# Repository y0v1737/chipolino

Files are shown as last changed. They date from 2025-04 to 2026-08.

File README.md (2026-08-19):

# Chip'olino: [The Playbook](The_Playbook/Chipolino_The_Playbook.md)

**Chip'olino** is a hardware-software platform designed for performing glitch attacks via power supply. It includes the main Chip'olino board and a set of addons for various microcontrollers. Chip'olino addresses two main tasks:
- Performing known power supply attacks on microcontrollers.    
- Research and experiments in the field of power supply attacks.

### Targets
Currently, the project includes algorithms for conducting attacks on:
* [Realtek (rtl8762)](The_Playbook/Realtek.md)
* [Rockchip (RK3588)](The_Playbook/RK3588.md)
* [nRF52 (The entire nRF5 family)](The_Playbook/nRF52.md)
* [Renesas RH850 (The entire RH850 family)](The_Playbook/Renesas.md)
* [NXP (LPC214x, LPC134x)](The_Playbook/NXP.md)
* [STM32 (Different series of chips)](The_Playbook/STM32.md)

In addition to the main algorithms, the repository contains auxiliary scripts for locking test chips, reading firmware, erasing the chip, and determining the current protection level.


##### Author's note.
Chip'olino implements algorithms for unlocking a large number of chips, but this does not eliminate the need to read the documentation and thoroughly understand what is happening. One needs to understand both how the protection of the target MCU works and how the attack is carried out. Power supply attacks are a complex and fascinating topic with many nuances.

Below is the functional diagram of the Chip'olino.

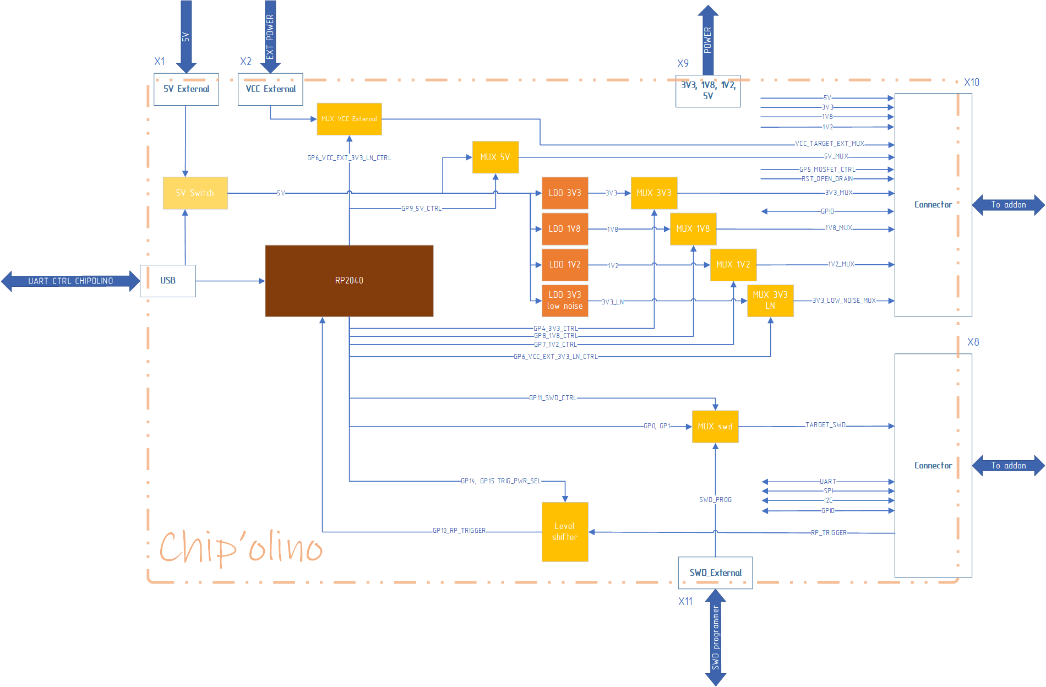
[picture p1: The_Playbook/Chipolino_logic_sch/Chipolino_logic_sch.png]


To carry out an attack on the MCU, it needs to be desoldered and soldered onto a ready-made addon, which can be connected to the main board. This approach allows for precise control of the timing parameters of the attack and significantly improves the repeatability of the attack.

### Features
* **External power supply for attacks:** Support for external power supply (0–5V, 100mA) through the X2 connector (External Target Supply). This is useful when the built-in power source is insufficient or when a lower voltage is required (e.g., for some chips that require less than the standard 3.3V). It allows you to connect a lab power supply and experiment with different power levels.    
- **High-speed SWD interface:** The implementation of SWD on the PIO in the Chip'olino module ensures direct and fast interaction with microcontrollers (NRF52, STM32, etc.) without the delays typical of USB programmers (J-Link and similar), speeding up command cycling by hundreds of times.    
- **SWD multiplexer:** The ability to switch between the built-in SWD interface and an external debugger connected to the X11 connector, which is convenient for quickly connecting an external programmer right after the attack is completed.    
- **Variety of power sources:** Several built-in power sources with independent control and support for external 5V power supply for the entire device, reducing the impact of noise and interference.    
- **Universal addon:** A module for connecting and testing any boards and devices.    
- **Auxiliary scripts:** A set of ready-made scripts for automating tasks and simplifying work with microcontrollers.

##### Note
```
All values for pulse widths and offset shifts for glitches provided in the instructions are based on the RP2040 clock frequency of 250 MHz.
```

### Files

```
.
├── The_Playbook
│   └── Chipolino_The_Playbook.md    # Chip'olino Playbook 
├── fw                               # Chip'olino firmware project 
│   ├── includes
│   ├── pio_sm
│   └── targets
├── pcb                              # PCB projects
│   ├── ChipOlino_revA               # Chip'olino PCB project
│   ├── Realtek                      # Realtek addons PCB
│   │   ├── RTL8762CKF_revA
│   ├── Nordic                       # Nordic addons PCB
│   │   ├── nRF52832-CIAA
│   │   ├── nRF52840-QIAA
│   │   └── nRF52833-QDAA
│   ├── NXP                          # NXP addons PCB
│   │   ├── LPC1343FBD48_revA
│   │   └── LPC2148FBD64_revA
│   ├── STM                          # STM addons PCB
│   │   ├── STM32F446RCT6_revA
│   │   └── STM32F411CCU_revA
│   ├── Renesas                      # Renesas addons PCB
│   │   └── RH850_F1L_revB   
│   ├── template_addon_revA          # template addon project
│   └── universal_addon_revA         # universal addon project
├── scripts                           
│   ├── check_ssr_rh850.py    
│   ├── chipctrl.py                  # Chip'olino control script (main for use)
│   ├── chipolino.py                 # class for Chip'olino board 
│   ├── dump_rh850.py                
│   ├── dump_stm32.py 
│   ├── dump_lpc1343.py
│   ├── dump_lpc2148.py
│   ├── erase_lpc2148.py
│   ├── erase_lpc1343.py
│   ├── erase_rh850.py               
│   ├── requirements.txt             # pip install -r requirements.txt
│   └── test_erase_stm32.py          
└── ...
```

### Quick start

1) Install all the necessary packages:
```
pip install -r ./scripts/requirements.txt
```
2) Read [The Playbook](The_Playbook/Chipolino_The_Playbook.md)

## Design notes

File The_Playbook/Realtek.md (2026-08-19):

## RTL8762CKF

### Overview
The **RTL8762CKF** is an ultra-low-power system on-chip solution for Bluetooth 5 low energy applications that combines the excellent performance of a leading RF transceiver with a low-power ARM Cortex-M4F and rich powerful supporting features and peripherals.

**RTL8762CKF** provides 6 security levels: 0 to 5. The security levels can be divided into two groups: 0 to 2 and 3 to 5. The only one difference of them is the HCI Download feature. A larger number indicates higher security level, which will affect debug and re-program of eFuse. Function control of each module under different security level is listed in the following table. 

| Security Level | SWD Control | eFuse Read | eFuse Write | HCI Download | HCI BT Test |
| --- | --- | --- | --- | --- | --- |
| 0 | Enable | Enable | Enable | Enable | Enable |
| 1 | Enable by password | Enable by password | Enable | Enable | Enable |
| 2 | Enable by password | Disable | Enable by password | Enable | Enable |
| 3 | Enable | Enable | Enable | Enable by password | Enable |
| 4 | Enable by password | Enable by password | Enable | Enable by password | Enable |
| 5 | Enable by password | Disable | Enable by password | Enable by password | Enable |

The documentation and SDK for this chip can be found here:
[https://www.realmcu.com/en/Resources/SDK/RTL8762C-Series](https://www.realmcu.com/en/Resources/SDK/RTL8762C-Series)  

For testing, you can solder the **RTL8762CKF** chip onto the addon board without any lock enabled and then activate the protection on it. It is recommended to use FT232 USB to UART converter boards for better stability. Connect addon board to USB to UART adapter as depicted below and use **MP Tool**  utility.  

Note: 2.5V (±10%) power supply must be applied when programming eFuse. The flash procedure supports wide voltage range and can be powered by 2.5V (±10%) as well. Under such circumstances, Flash and eFuse can be programmed in one step.  

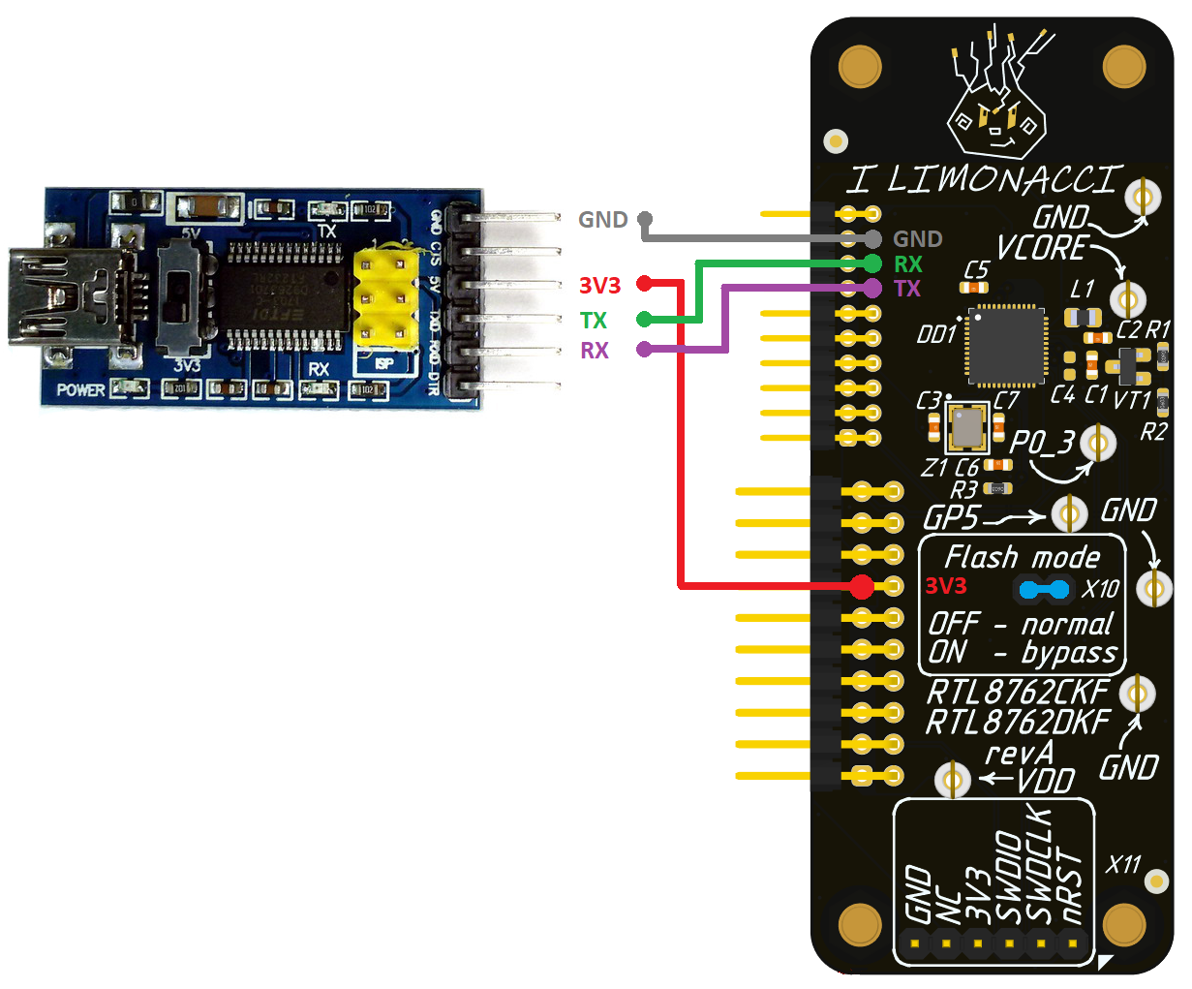
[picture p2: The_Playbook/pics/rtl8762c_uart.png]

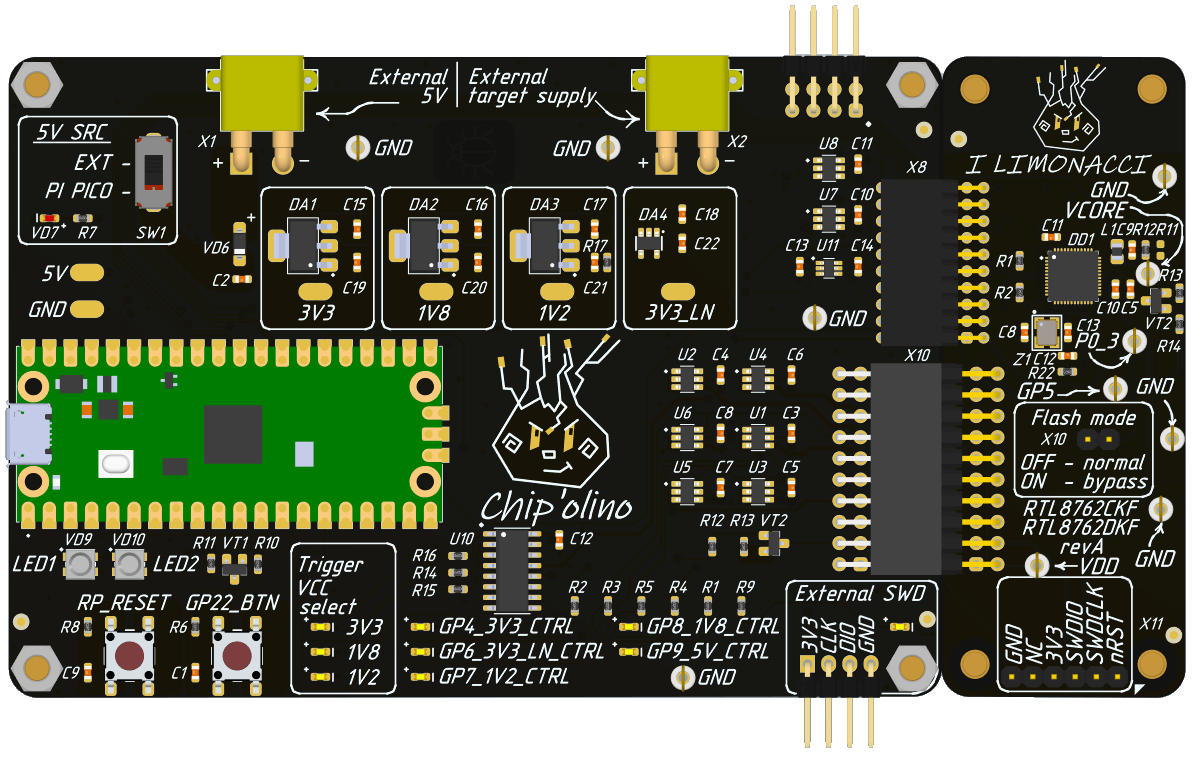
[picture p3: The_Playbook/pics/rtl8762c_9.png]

## Glitch can bypass SWD password check on boot.
During the security research of RTL8762CKF we were able to dump ROM from chip. One of the ROMs functions: **configure_security_register_and_LOCK_it()**  performs check of security state of IC and also verifies password to unlock SWD (Security LOCK_MODE 5, greatest).

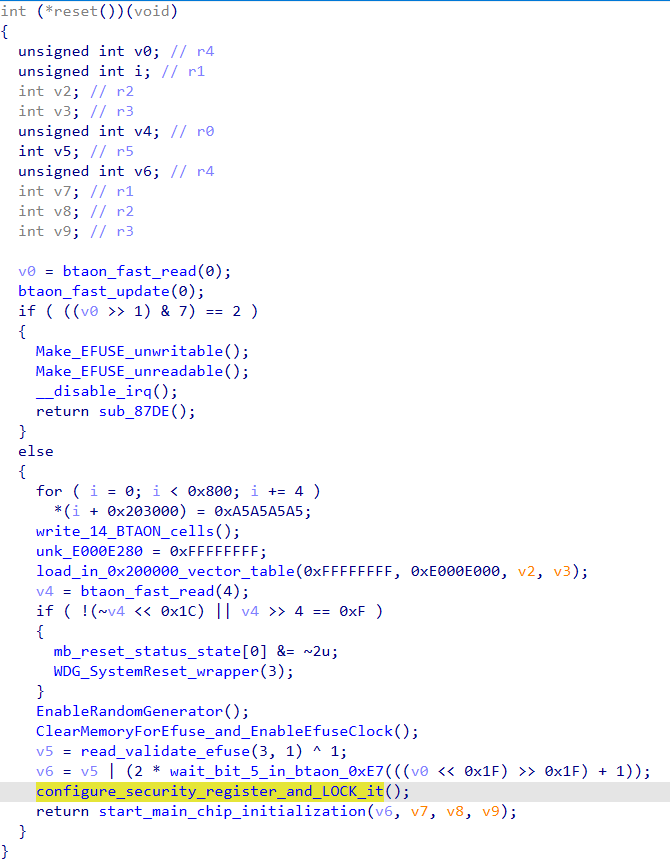
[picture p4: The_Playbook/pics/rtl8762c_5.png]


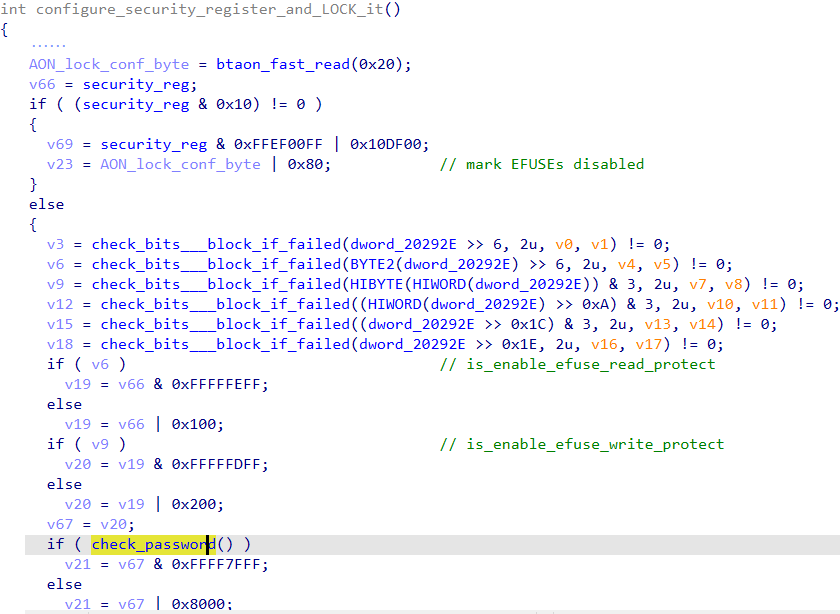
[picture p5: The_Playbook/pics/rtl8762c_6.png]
  

In **check_password()** function we identified, after memcmp() function we can possibly glitch CPU power to skip instruction or revert state of R0 register.

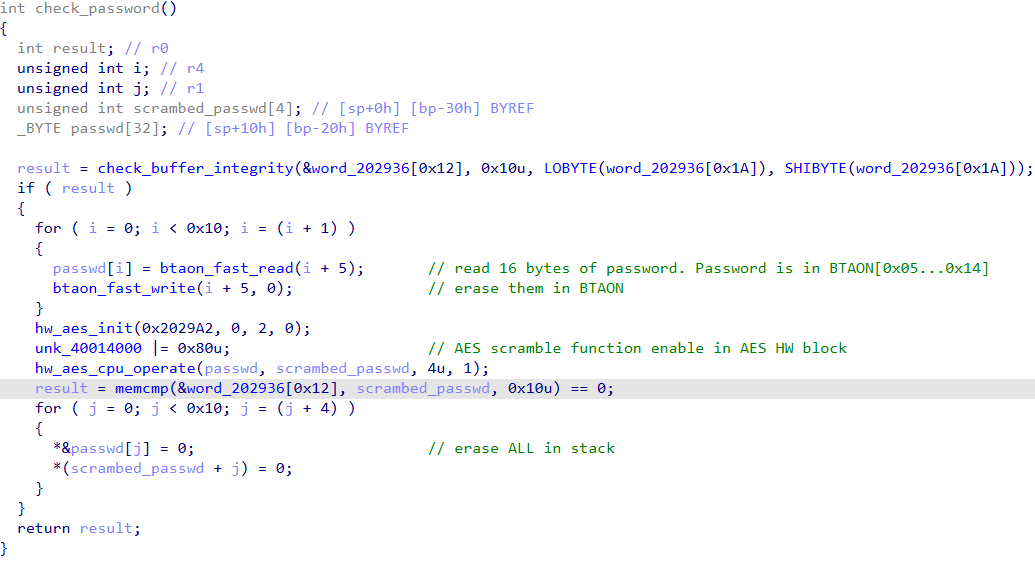
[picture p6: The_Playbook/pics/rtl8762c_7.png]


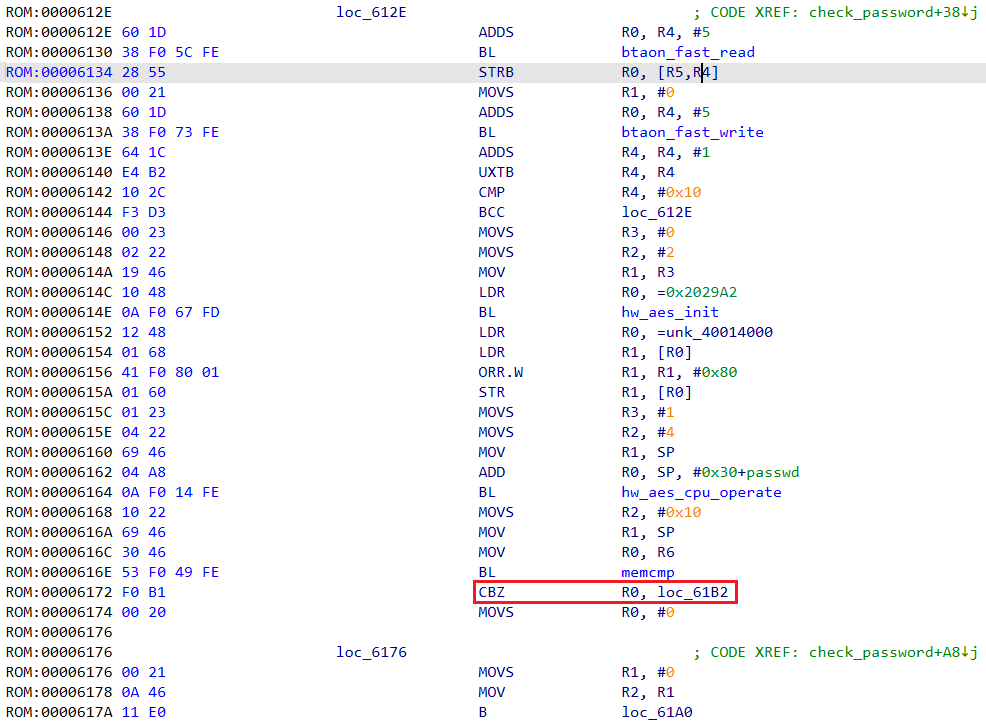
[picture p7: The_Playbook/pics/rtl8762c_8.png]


Note, there are several places in the code where successfull glitch (that skips instruction or alters register value) may lead to SWD unlock.  

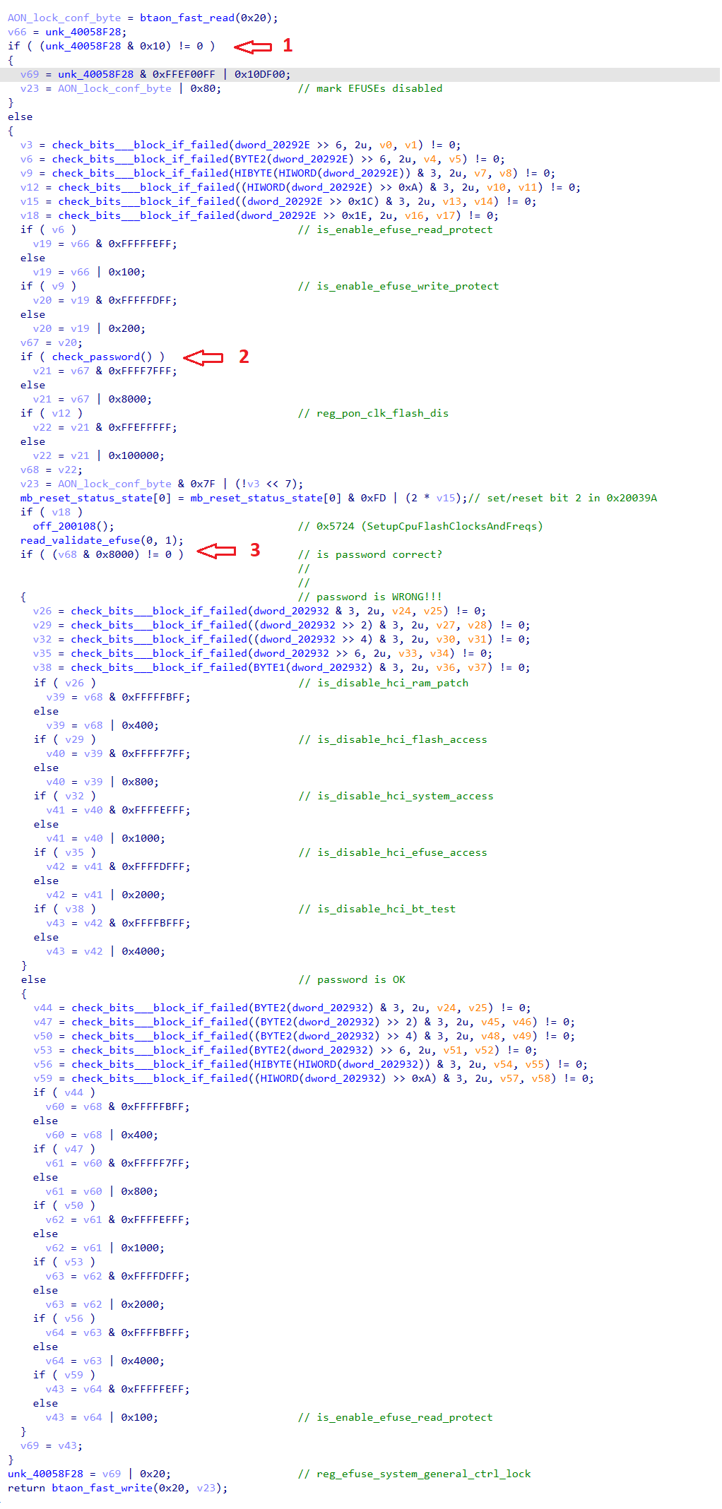
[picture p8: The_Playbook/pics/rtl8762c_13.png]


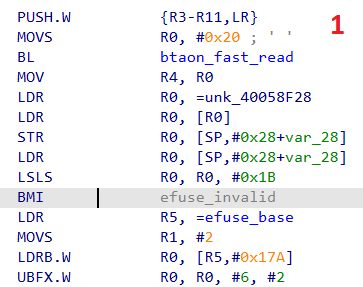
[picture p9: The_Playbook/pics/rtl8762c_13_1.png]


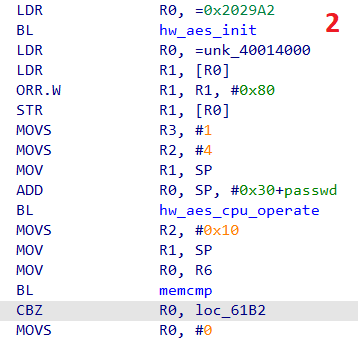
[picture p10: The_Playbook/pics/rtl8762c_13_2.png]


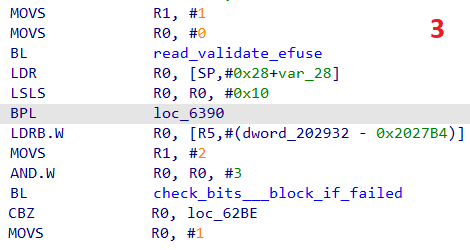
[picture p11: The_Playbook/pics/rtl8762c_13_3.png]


With the EM probe we perform a simple side-channel analysis (SCA) to understand when SWD access check operation is implemented, what parts of bootrom code precede and what follow it. This insight helps us in narrowing down the point in time for the fault injection attack to unlock debug interface with precision of few microseconds.  

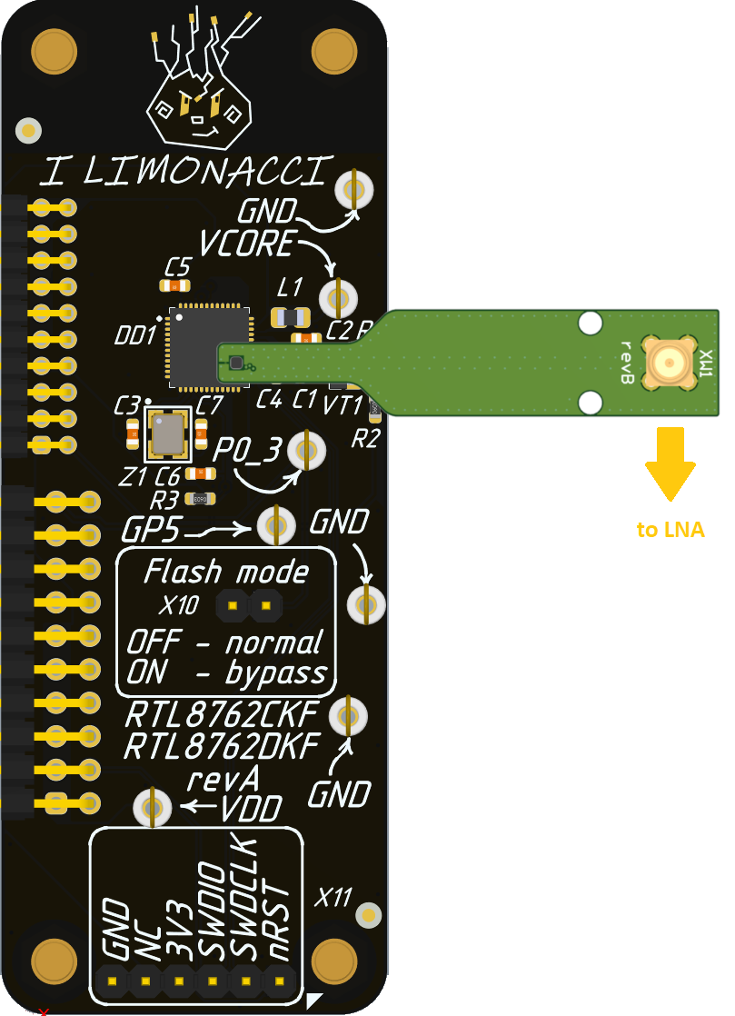
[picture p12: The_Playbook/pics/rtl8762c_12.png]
  

It is important to note that in order to obtain a clear picture of the chip's EM emission, the value of the capacitance shunting the VDIGI pin of the RTL8762CKF must be reduced to 10 nF.  

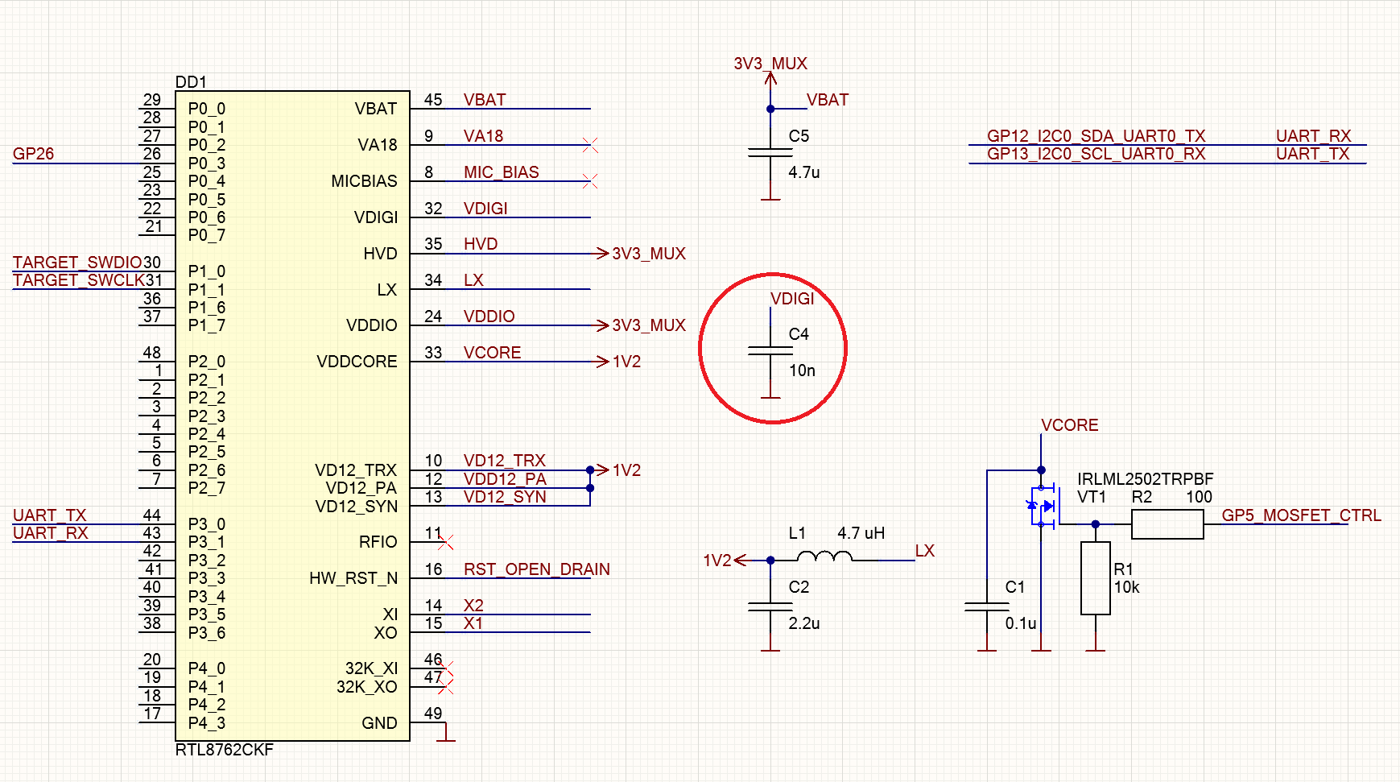
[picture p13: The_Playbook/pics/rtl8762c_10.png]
  

The following picture shows the EM trace of the chip's activity from the beginning of the bootrom execution.  

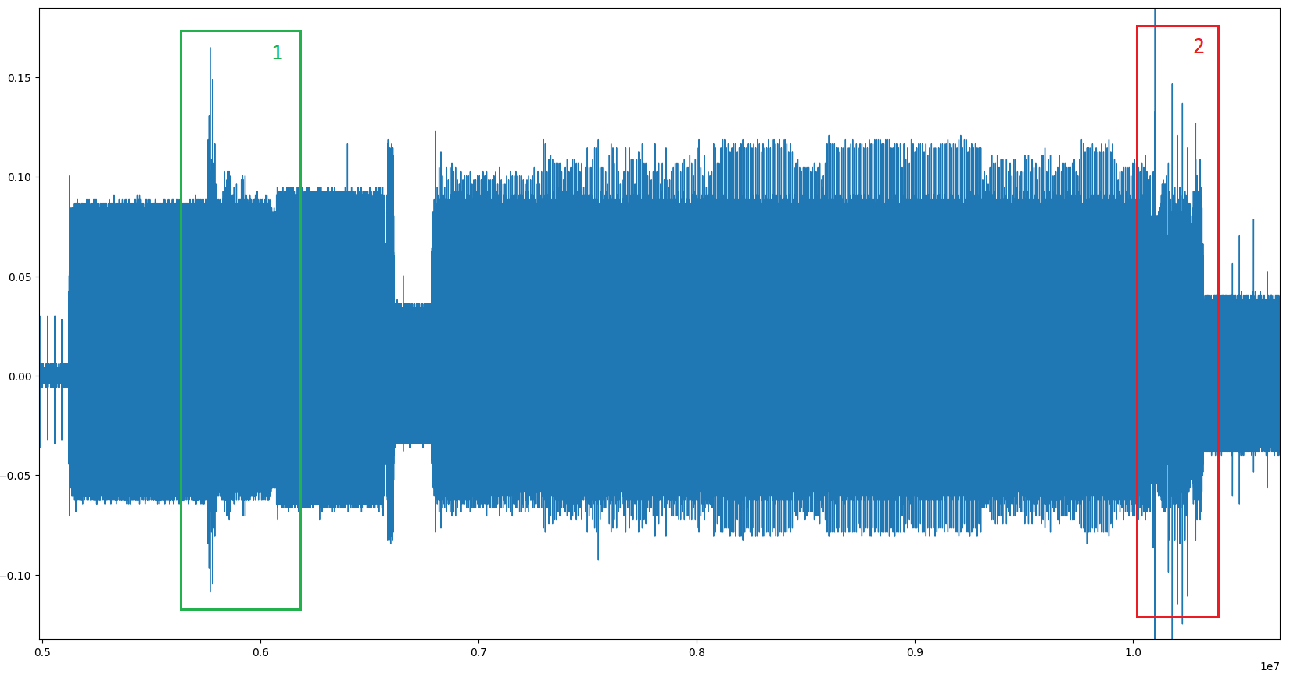
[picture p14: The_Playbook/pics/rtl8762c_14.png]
  

At the beginning it's easy to visualize the place where 14 bytes of BTAON cells are written (write_14_BTAON_cells()). Moreover all previous and consequent cyclic operations with SRAM are clearly distinguished.  

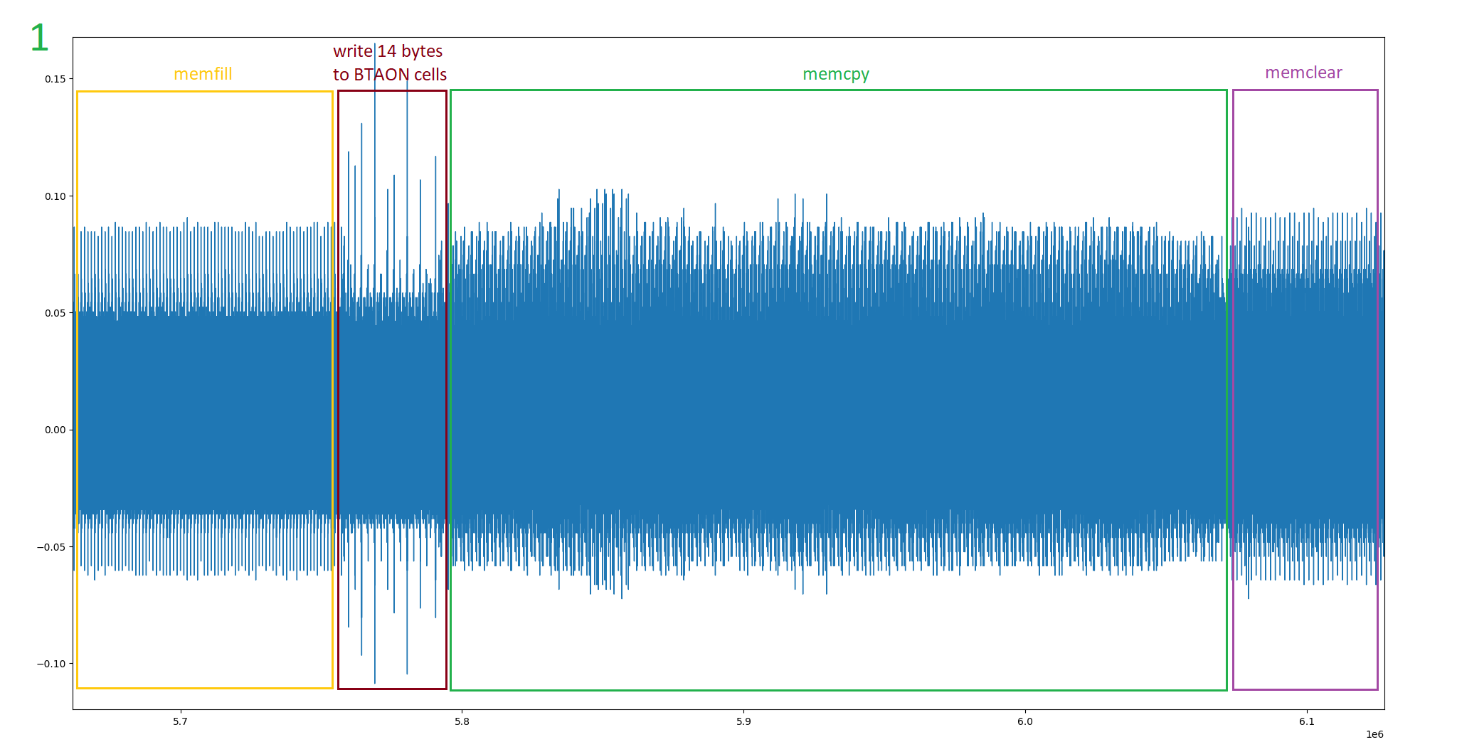
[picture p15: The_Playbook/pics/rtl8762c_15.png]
  

In the area marked **2** another similar BTAON access pattern is visualized. It correspons to read and clear of 16 cells which store password, and is followed by AES-based password verification. This is the target area for power glitch.  

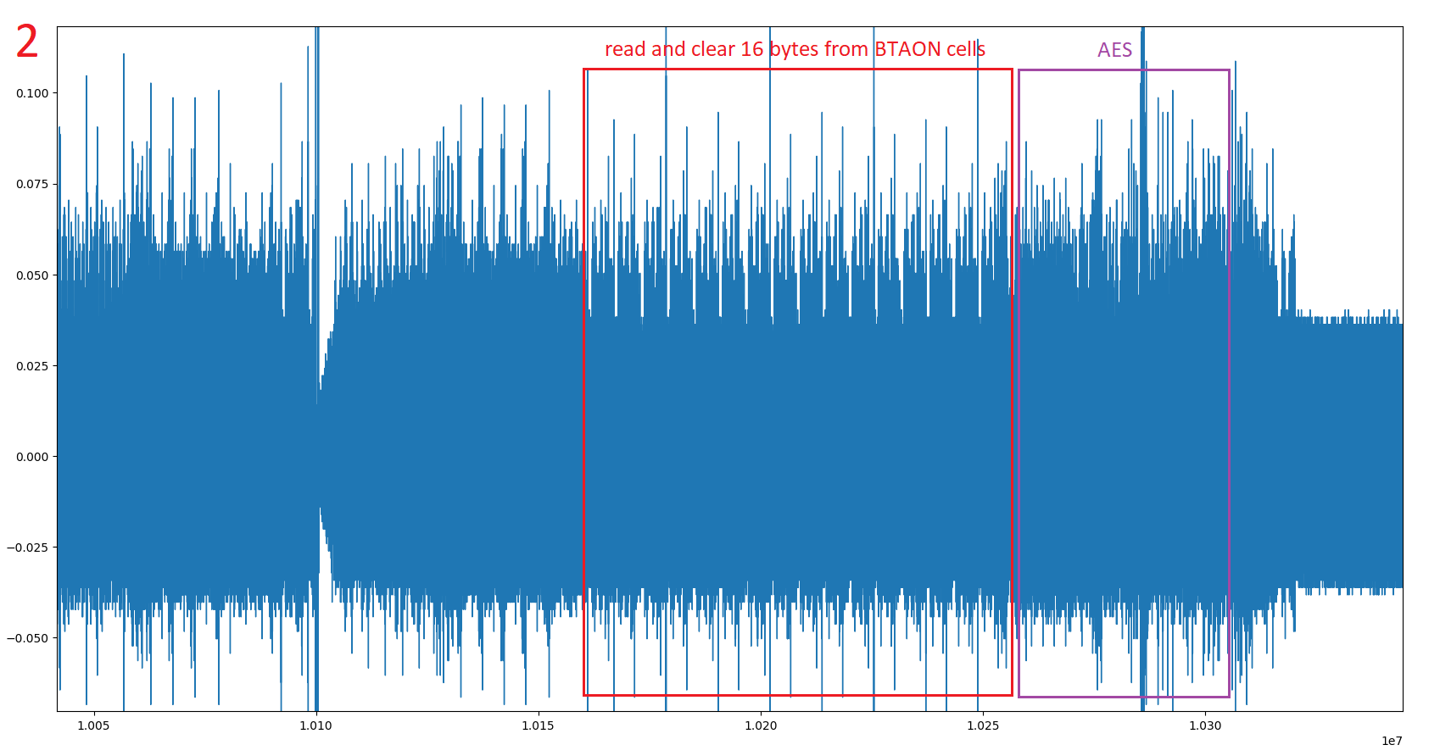
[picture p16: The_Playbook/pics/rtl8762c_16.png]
  

The following pictures show the chip's EM emission from the start and approximate position for the succesfull power glitch.  

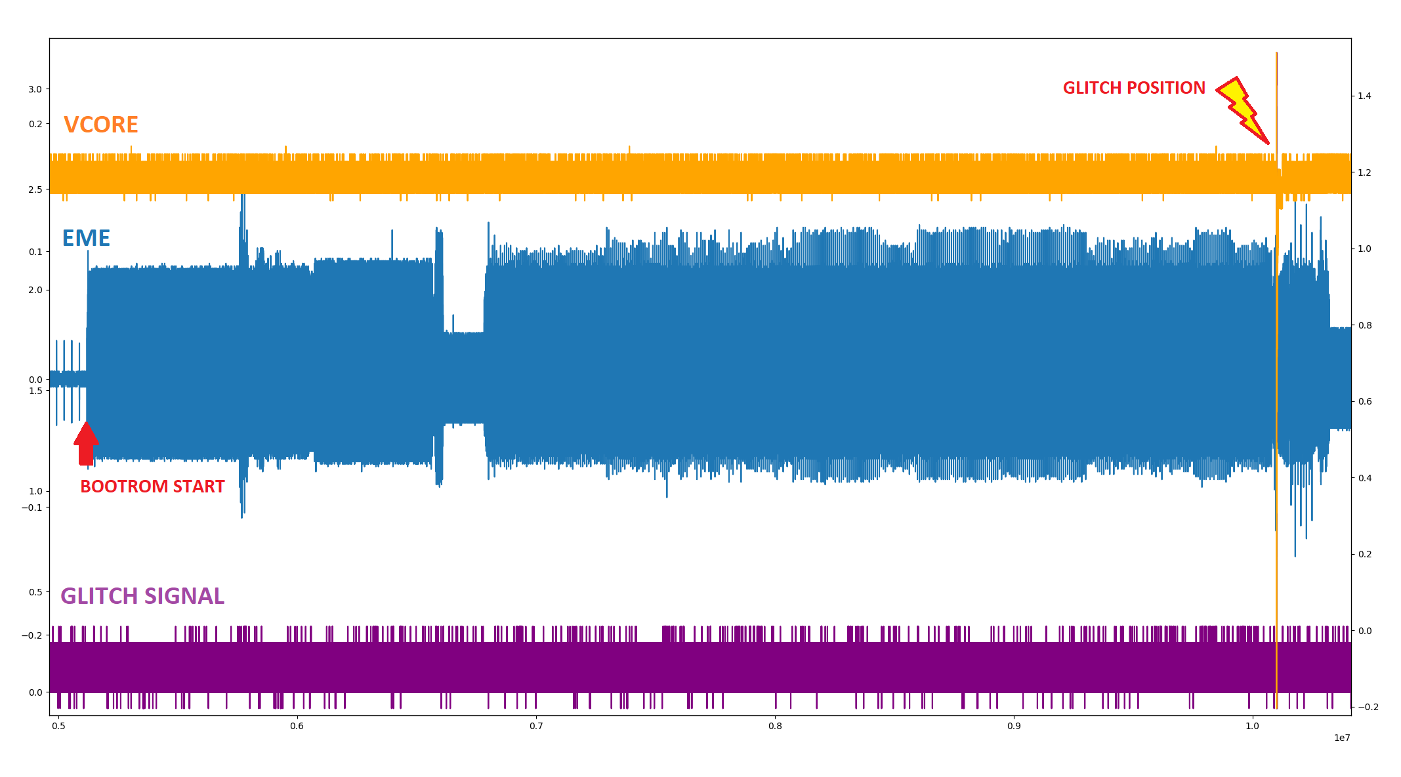
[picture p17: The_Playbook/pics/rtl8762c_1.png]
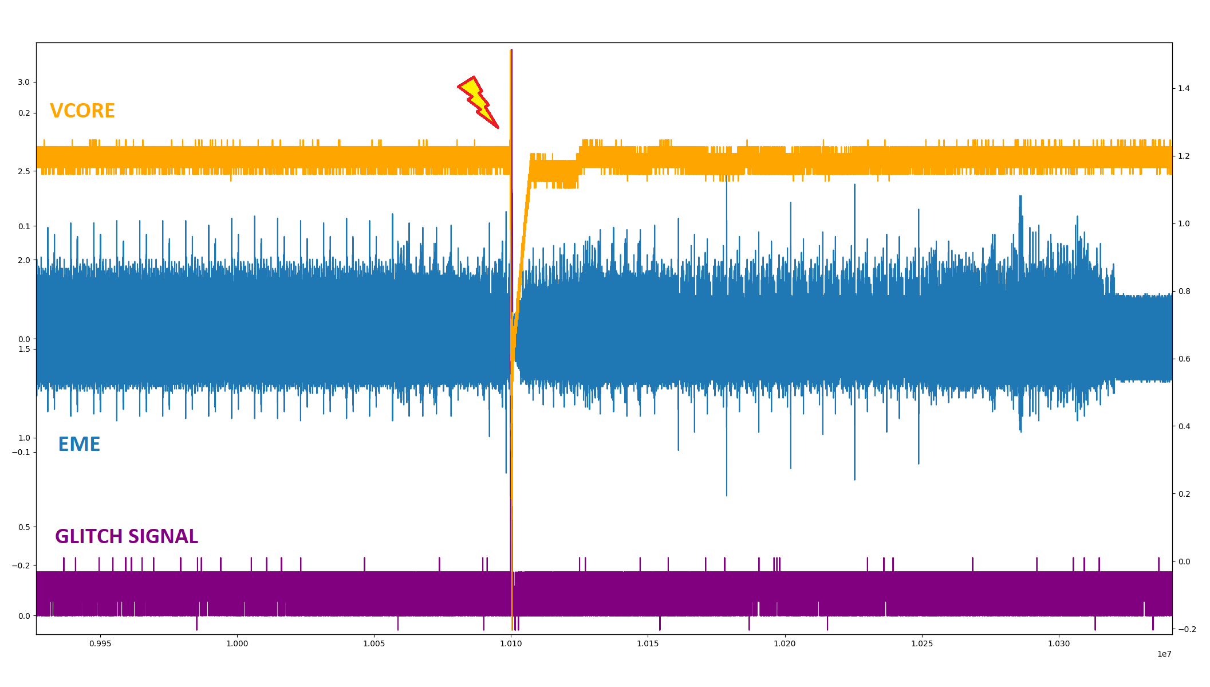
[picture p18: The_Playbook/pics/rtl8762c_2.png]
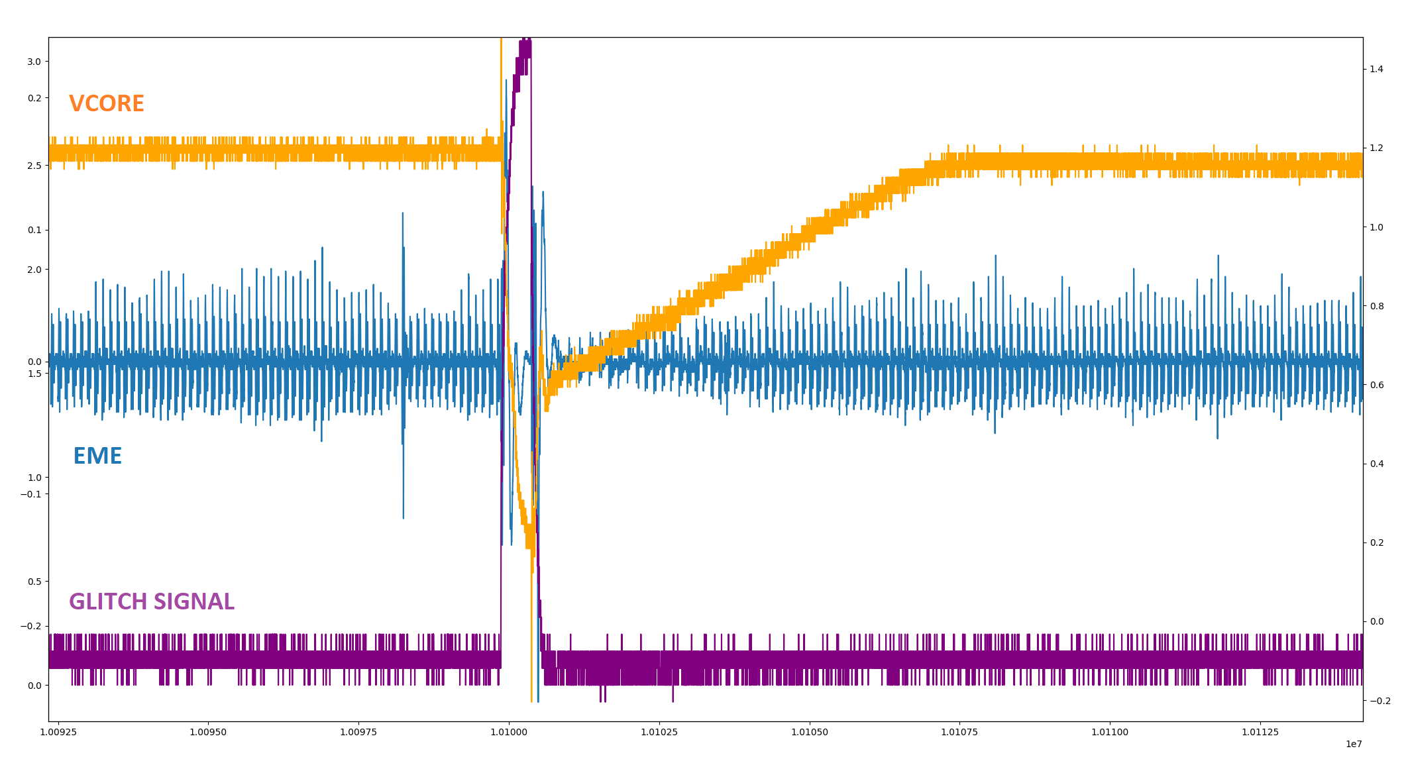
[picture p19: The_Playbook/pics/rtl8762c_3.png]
  

To carry out power-glitch attack with Chip'olino the automated Python script is used:

```
py.exe chipctrl.py -p COM5 -g -t rtl8762c -o 8516600 9000000 -w 55 65
```

Note, the offset interval (8516600,9000000) and glitch width (55,65) may require some adjustments.  

After a successful attack, the SWD AP becomes accessible. Without disconnecting the addon from Chip'olino, switch the SWD pins from the RTL8762CKF to the external connector and connect а hardware debugger to it.

```bash
# Switch the SWD pins from the MCU to the external connector
py.exe chipctrl.py -p COM5 -swd ext
```

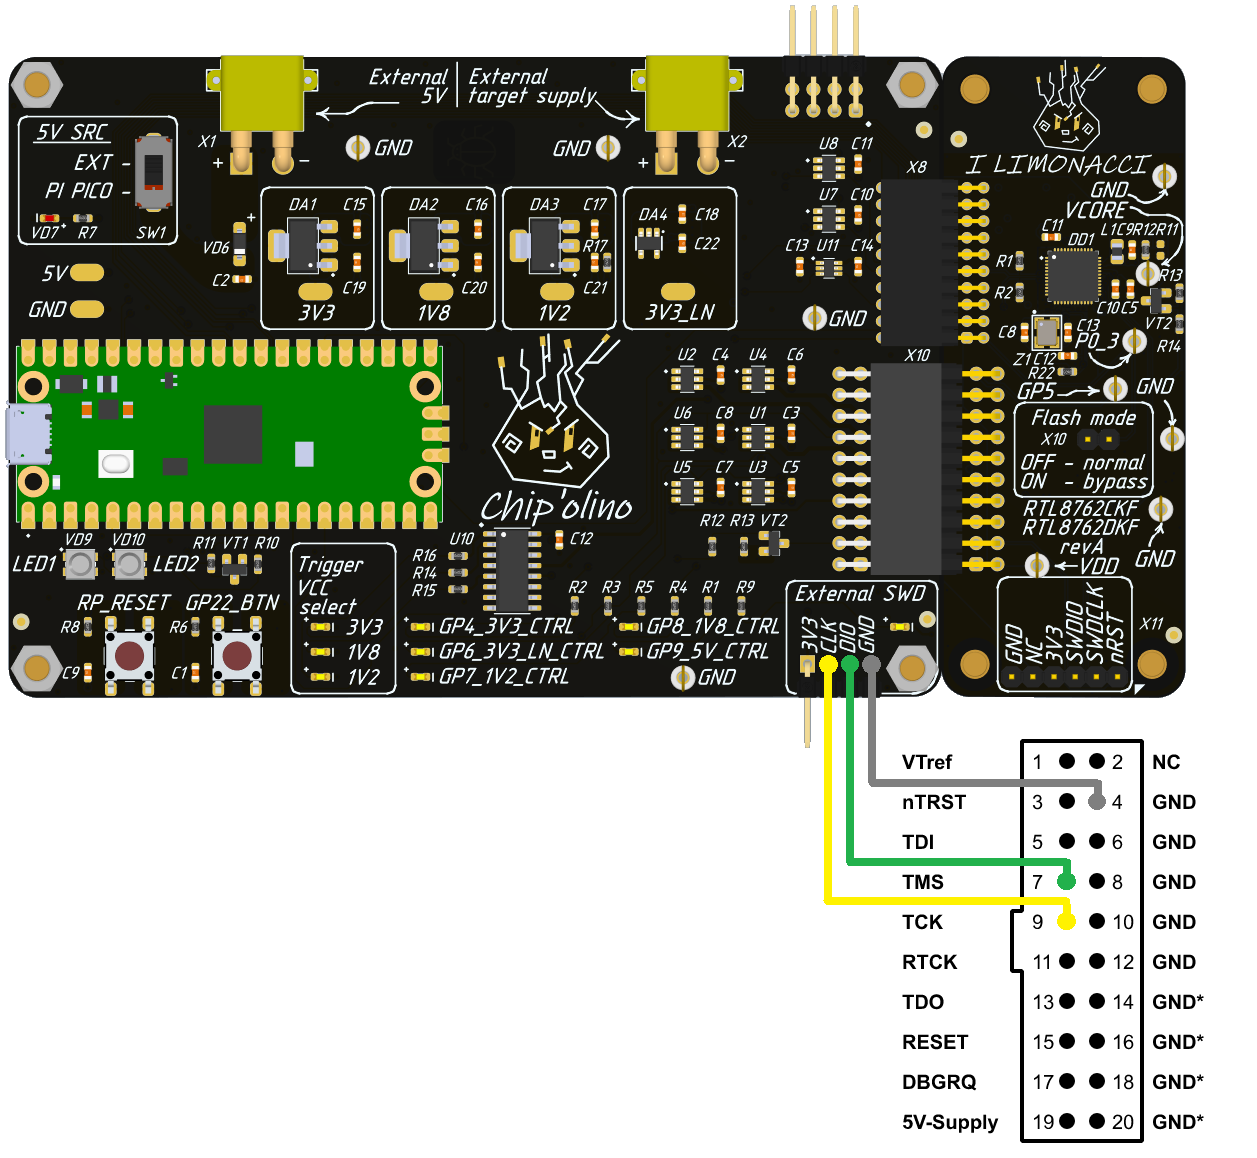
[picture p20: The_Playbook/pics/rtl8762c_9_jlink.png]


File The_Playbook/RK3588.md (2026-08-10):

# RK3588
## Bypass secure boot using power fault injection on Orange Pi 5 Plus

### Vulnerability description 

##### Note
```
This SoC has more than one BootROM. If Secure Boot is enabled, the Secure BootROM is executed instead. Therefore, to prepare the attack, we first need to dump and analyze it. This is where the Secure Boot algorithms are implemented.
```

For the attack, we used an Orange Pi 5 Plus board with an onboard SPI Flash. Booting from SPI Flash is more convenient for research than booting from eMMC. The vulnerability is also present when booting from eMMC, but boards with this configuration are relatively rare.

The SoC boot process works as follows:

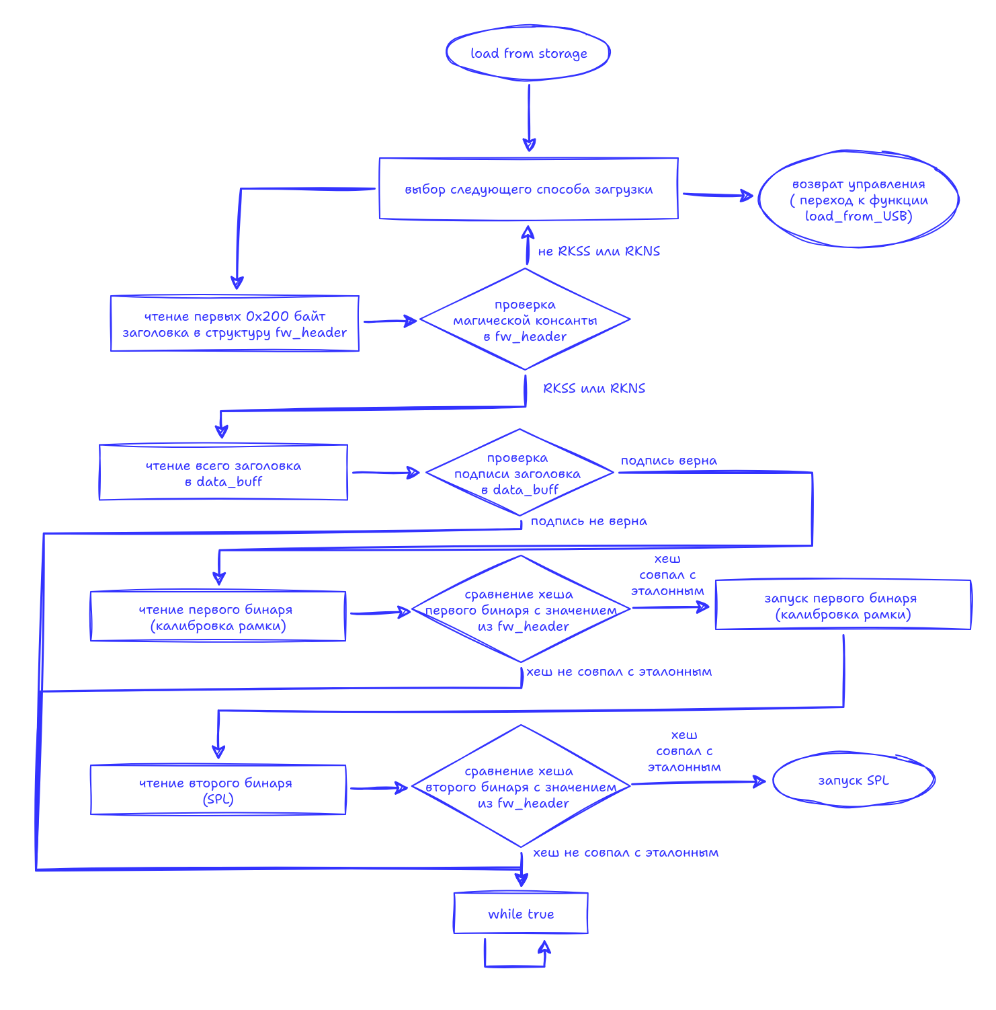
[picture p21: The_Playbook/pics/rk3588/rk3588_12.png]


- Load the header into memory (contains hashes for DDR training and SPL)
- Verify the header signature
- Load the DDR training binary into memory
- Verify the DDR training hash
- Execute DDR training
- Load the SPL binary into memory
- Verify the SPL hash
- Execute SPL
- And so on...

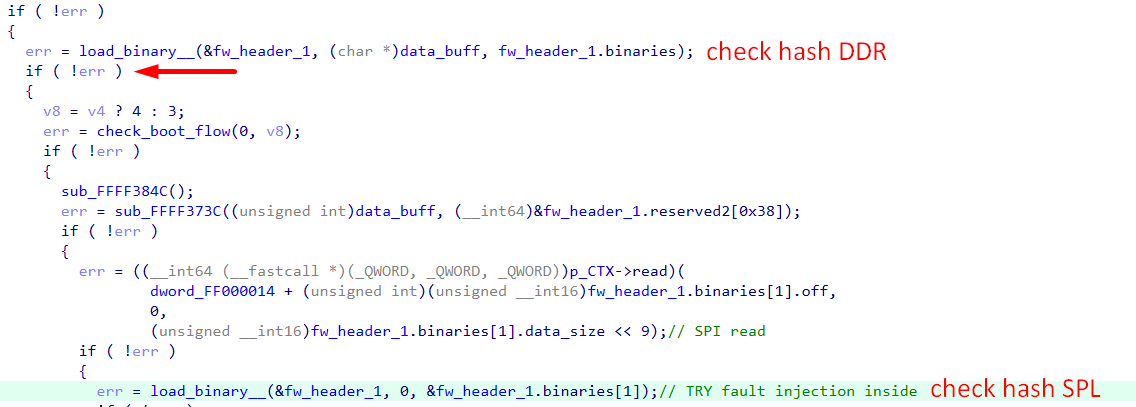
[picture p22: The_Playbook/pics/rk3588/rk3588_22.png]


**A suitable point for the attack:** the hash verification of the SPL or DDR training. In this case, there is no need to modify the header or change any of its data. It is sufficient to patch the binary as needed, and if the glitch is successful, the code will be executed:

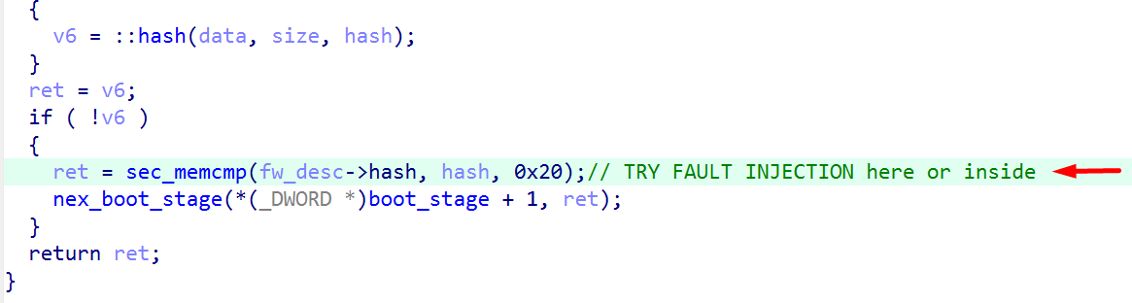
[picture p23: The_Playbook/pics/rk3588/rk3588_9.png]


### Preparation Orange PCB
The first step is preparing the test setup. Usually, for each new microcontroller, we build a small board — an add-on with the minimum necessary circuitry. This significantly simplifies tuning the attack parameters and makes the attack reproducible on other similar MCUs.

In this case, the SoC is large and complex, making it difficult to build a dedicated board for it. We wanted to get this optional task done quickly. So, for the first time in a long while, we deviated from our usual approach and decided to perform the attack directly on the device — specifically, on an Orange Pi board.

After reviewing the SoC documentation and the Orange Pi schematics, it became clear that the attack most likely needed to target the `VDD_CPU_LIT_S0` power line. LIT stands for _little_, referring to the little core. This is the core that executes the BootROM code we need to glitch.

Another indication that the BootROM runs on “little” core 0 is its first instruction: `MRS X0, MPIDR_EL1`. This instruction reads the `MPIDR_EL1` system register into the X0 register. The code then checks whether execution is taking place on core 0; if not, it gets stuck in a `while (true)` loop.



In addition, analyzing the schematic revealed several other important details:
- the presence and number of capacitors on the core power rail (not that we didn’t expect them)
- the maximum current the core power supply can deliver — 5 A

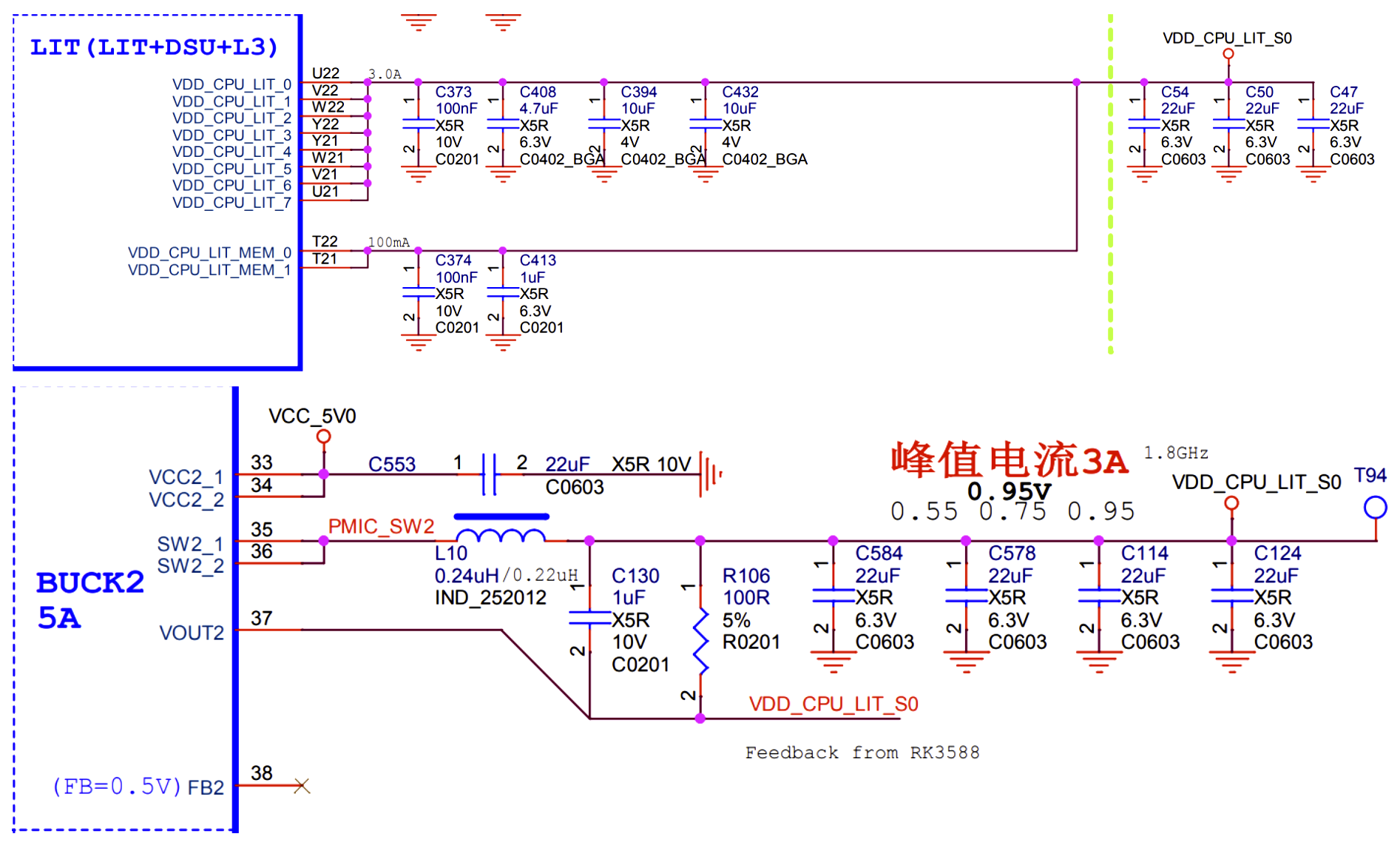
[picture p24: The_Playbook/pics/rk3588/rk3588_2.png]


All capacitors on the `VDD_CPU_LIT_S0` line were identified and removed from the board. The SoC boots normally without them, although this is not always the case. Often, several capacitors need to be left in place for the chip to operate properly, even though they make it harder to pull the core voltage down sharply.

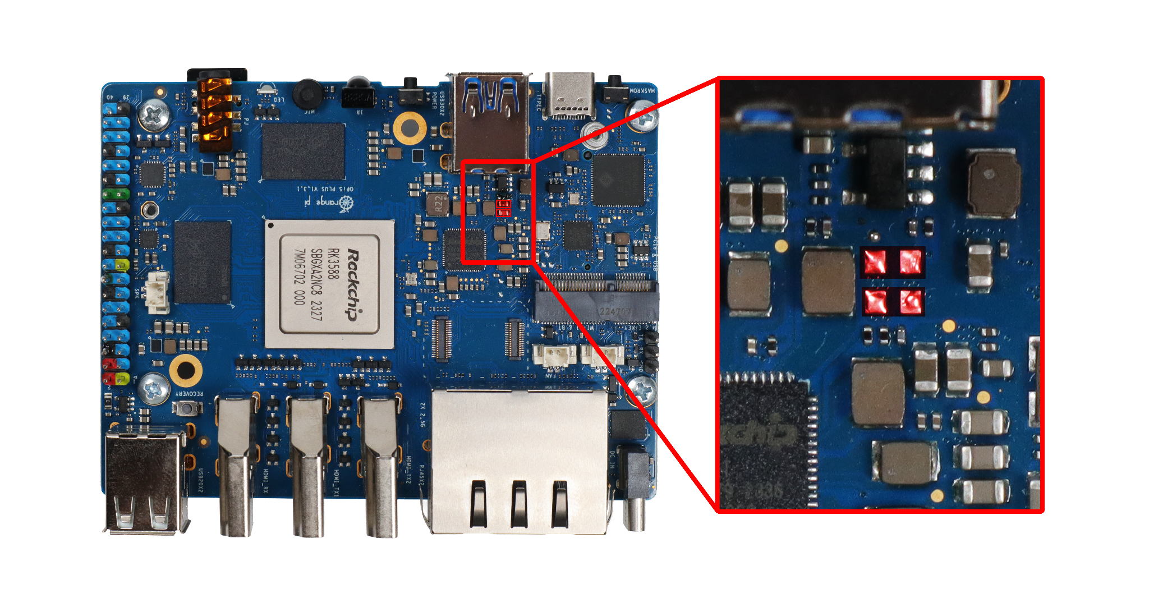
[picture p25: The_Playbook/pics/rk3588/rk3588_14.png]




The fact that the DC/DC converter can deliver a high current means that a powerful transistor with a dedicated driver is required to control it. After all, the shape and duration of the pulse are among the key factors determining the success of the attack.

As a result, in addition to Chipolino, we built an external transistor module based on this schematic. Here’s what we got:



The module requires a 5 V power supply and a connection to common GND, while the control input is connected to Chipolino.

An important factor in achieving the steepest possible pulse waveform is minimizing the resistance of the connection between the module and the SoC core power inputs. Therefore, the module is mounted on the back side of the board, as close as possible to the SoC pins, and a thick wire is used to connect it to Vcore.



### Glitch SoC

As the attack platform, we use Chipolino and, in this case, a universal add-on for convenient connection to the Orange Pi and the driver. It looks like this:


Connection table:



##### Note
```
Orange debug serial port parameters: 1500000 8N1.
```

This board boots from SPI Flash. This means that the BootROM looks for the header and SPL there. For this reason, we designed the attack logic around the data exchange on the SPI interface. If we look at the boot log:



we can note the following:

- The approximate point at which control is transferred to the DDR module can be determined from the messages it starts sending over UART.
- The DDR module starts approximately 550 µs after the end of its read from SPI Flash.
- The CS (chip select) line is toggled 17 times from reset assertion until the end of the DDR module read.

All of this suggests that we can synchronize the attack with the CS line and count its edges until the DDR module has finished loading. This should allow us to get as close as possible to the point at which the DDR binary hash is verified. Of course, some fine-tuning of the attack timing will still be required, but it is clear that there is no point searching beyond 550 µs after the end of the read — by that time, the module has already started executing.

Thus, we have established the attack logic and reduced the timing search window to 550 µs, which is very small in our experience.

So, here is the plan:

- Start the Orange Pi using the reset signal (connected to Chipolino).
- Wait for 17 edges on the CS line (connected to Chipolino's GP28).
- Glitch Vcore line.
- Wait for messages from the modified DDR module over UART.
- If the messages are received, the attack was successful and the code has started executing. If not, repeat steps 1–5 with a different attack timing.
- The End.

So, we enable Secure Boot and boot a correctly signed image to study the system's behavior. We then patch the DDR module. As soon as this image was written to the SPI Flash, the SoC stopped booting normally and the UART messages disappeared, meaning the system was ready for the Power Glitch attack.

Following the plan described above, we implemented the attack algorithm in Chipolino. Essentially, our experiments resulted in several parameters that define a successful attack. Here they are:
###### Command
```bash
py.exe chipctrl.py -p COM5 -g -t rk3588 -o 135435 135450 -w 250 280
```



###### Glitch parameters
* ~1 us pulse duration;
* ~540 µs after the last edge on the CS line during the DDR module read
* Method: N-MOSFET driver on the VDD_CPU_LIT_SO (core power line)





### Links
* [Extract Secure BootROM](https://ptresearch.media/articles/kak-zashifrovat-apelsinku-ili-e-boot-na-orange-pi-5)

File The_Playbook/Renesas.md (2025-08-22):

# Renesas
## RH850

MCUs built on the RH850 architecture include a wide range of microcontroller families. All of them feature several security mechanisms, but only three can actually interfere with firmware extraction. Chip'olino supports bypassing all of these protections: [Unlock "ID authentication"](#id_lock), [Unlock "Read protection"](#rp_lock), [Unlock "Serial connection is prohibited"](#ser_lock).



### Supported devices

The most detailed description is provided for bypassing the protection [Unlock "Serial connection is prohibited"](#ser_lock), so it's best to start reading from there. All attacks use the same add-on — there's no need to rewire or modify it depending on the type of protection.
Currently, the repository includes add-ons for:
* RH850 F1L family
* RH850 F1KM family (in progress, will be soon)
* ...
* any RH850 MCU - using the universal add-on.

<details>
  <summary>Addon RH850 (F1L)</summary>
  




</details>

### <span id="id_lock">Unlock "ID authentication"</span>

The most commonly used protection level for RH850 MCUs is **ID authentication.** This means a password has been set. Without it, you cannot read memory, erase the microcontroller, write to memory, or perform other operations. Essentially, all bootrom commands remain inaccessible until the correct password — the _IDCODE_ — is entered.

| Function | Description |
| --- | --- |
| ID authentication | The result of ID authentication can be used to control the connection of a<br>dedicated flash memory programmer for serial programming. The result of ID<br>authentication can also be used to control enabling of self-programming. |

To determine the protection level, you can use either the Renesas Flash Programmer utility or a script **/scripts/check_protect_rh850.py**. To do this, connect the addon to the PC using a USB-UART adapter.





#### Glitch MCU

To communicate with a password-protected MCU, you need to send several commands in a specific order. After that, the MCU will enter a normal command processing mode, which includes the ability to read FLASH memory. Below is the list of required commands:

| Command | Description |
| --- | --- |
| 0x38 | get device type |
| 0x32 | set frequency |
| 0x34 | set baudrate |
| 0x00 | inquiry |
| 0x2C | is_set_IDCODE |
| 0x30 | IDCODE check |

The argument of command 0x30 is a 16-byte IDCODE. If the password is incorrect, the MCU will respond with an error **0xDB - ID mismatch**.



To bypass glitch protection, the glitch must be triggered during the time window between sending the password and receiving the MCU's response.  Any password can be used as the argument for command `0x30`; by default, Chip'olino uses 16 bytes of `0xFF`.
To launch the attack, run the script **/scripts/chipctrl.py** for target (-t) "rh850_id":

```bash
py.exe chipctrl.py -p COM5 -g -t rh850_id -o 17660 37000 -w 95 117
```



An example of a successful attack for the IDCODE bypass is shown below.







###### Glitch parameters
* ~66 µs from the last edge of the "idcode_check" (0x30) command sent over UART;
* ~400 ns pulse duration;
* Method: N-MOSFET on the VCL lines powering the MCU core.

#### Dump firmware
After a successful glitch, do not disconnect the add-on from the Chip'olino board — the MCU remains powered and can process commands over UART. Connect the USB-UART adapter to the add-on and to the PC **before** the attack. Use only the RX, TX, and GND pins.
##### Attention!
```
Important! Do not connect the DTR-Reset line or 3.3V after the glitch. Opening the port triggers a reset.
```



The RH850 bootloader includes a memory read command with ID = 0x15, which can now be used.  
There is a ready-to-use script for this: _**/scripts/dump_rh850.py**_.
##### Attention!
```
Beforehand, you need to review the memory map specific to your MCU. There are quite a few variants in the RH850 series.
```

Use the script for dumping RH850 (10233) memory: ***/scripts/dump_rh850.py***
```bash
# dump code flash
py .\dump_rh850.py -p COM4 -a 0x0 0x07ffff -f rh850_code_flash.bin

# dump data flash
py .\dump_rh850.py -p COM4 -a 0xFF200000 0xFF207fff -f rh850_data_flash.bin
```

### <span id="rp_lock">Unlock "Read protection"</span>

Another protection level that prevents extracting firmware from RH850 MCUs is **Prohibition of read commands**. This means the memory read command is disabled. Without this protection, you can put the MCU into bootrom mode. After the synchronization process, the MCU is ready to process various commands, including command `0x15` — "Read memory". This allows reading the MCU’s FLASH memory.
However, if the "Read protection" is enabled, reading memory this way won’t work because the MCU will respond to the "Read memory" command with an error.

| Function | Description |
| --- | --- |
| Prohibition of read commands | Read commands at the time of serial programming are prohibited. Only<br>through execution of the configuration clearing command can the prohibition be lifted. |

To determine the protection level, you can use either the Renesas Flash Programmer utility or a script **/scripts/check_protect_rh850.py**. To do this, connect the addon to the PC using a USB-UART adapter.





#### Glitch MCU

To communicate with a password-protected MCU, you need to send several commands in a specific order. After that, the MCU will enter a normal command processing mode, including the ability to read FLASH memory. Below is the list of required commands:

| Command | Description |
| --- | --- |
| 0x38 | get device type |
| 0x32 | set frequency |
| 0x34 | set baudrate |
| 0x00 | inquiry |
| 0x21 | read_ssr |
| 0x15 | read memory |

The argument for command `0x15` consists of the start and end addresses of the memory range to read. Each address is 32 bits. If protection is enabled, the MCU will respond with the error **0xDA - protection error**.



To bypass the protection, a glitch must be triggered during the time window between sending the memory read command and receiving the MCU's response. If the attack is successful, you can continue the reading process via USB-UART. The memory read command occurs in two iterations:
* Sending the command and waiting for the MCU's response;
* Receiving data from the MCU in 0x400-byte chunks.

To launch the attack, run the script **/scripts/chipctrl.py** for target (-t) "rh850_rp":

```bash
py.exe chipctrl.py -p COM5 -g -t rh850_rp -o 17660 37000 -w 95 117
```



An example of a successful attack for the read protection bypass is shown below.







###### Glitch parameters
* ~70 µs from the last edge of the "read memory" (0x15) command sent over UART;
* ~400 ns pulse duration;
* Method: N-MOSFET on the VCL lines powering the MCU core.

### <span id="ser_lock">Unlock "Serial connection is prohibited"</span>

RH850 has several security features. They can be enabled individually or all at once. This chapter focuses on bypassing the protection called "**Prohibition of connection of a dedicated flash memory programmer"** — which blocks communication with the MCU in bootloader mode, making it impossible to read the firmware using standard bootloader commands.

| Function | Description |
| --- | --- |
| Prohibition of connection of a dedicated flash memory programmer | The connection of a dedicated flash memory programmer for serial programming is prohibited. Since execution of the configuration clearing command is also prohibited when the connection of a dedicated flash memory programmer is prohibited, changing a security setting from “prohibited” to<br>“permitted” is not possible. |

##### Attention!
```
Before carrying out the attack, make sure that this specific protection is enabled. You can verify this by using either /scripts/check_protect_rh850.py or the Renesas Flash Programmer.
```

Connect the addon (without the Chip'olino board) to the PC via a USB-UART adapter. The DTR, RX, TX, 3.3V, and GND lines are mandatory. Then either run the script _**/scripts/check_protect_rh850.py**_ or try to connect using the Renesas Flash Programmer. In both cases, you should see the message:  
**"A serial connection is prohibited for this device."**







#### Glitch MCU

For the glitch attack, an N-MOSFET is installed on the AWOVCL and ISOVCL pins of the addon. Additionally, the addon has the required pull-up resistors installed to enable the MCU to start in bootloader and serial programming mode.

##### Note
```
A quartz crystal resonator (16 MHz) is required for the microcontroller to operate.
```

The glitch moment is after sending the "Inquiry" command and before receiving its response over UART. If serial communication is restricted, the response will include the code 0xDC indicating "serial programming disabled." Specifically, the responses look like this:
* b'\x81\x00\x01\x00\xFF\x03' — protection is **not** enabled;
* b'\x81\x00\x02\x80\xDC\xA2\x03' — protection **is** enabled.




Chip'olino implements a synchronization protocol with the RH850 via UART. For a successful attack, it is necessary to synchronize and send several preliminary commands before the "Inquiry" command.





At this stage, we have confirmed that the "Prohibition of connection of a dedicated flash memory programmer" protection is enabled and have a rough understanding of what happens during the attack.

Run the script **/scripts/chipctrl.py** with the specified parameters.
```bash
py.exe chipctrl.py -p COM5 -g -t rh850_ser -o 16420 17000 -w 95 105
```

###### Note
```
Your port, offset, and pulse width may differ.
```

If you are using Chip’olino together with the addon, you can simply run the script as shown above. The glitch offset and pulse width parameters usually won’t change much. If something doesn’t work out, below are oscilloscope screenshots of a successful attack. You can compare both the signal shape and timing parameters, then fine-tune the offset and pulse duration accordingly.

###### Note
```
Carefully review the screenshots — they can be extremely helpful in case any issues arise.
```







###### Glitch parameters
* ~66 µs from the last edge of the "Inquiry" command `{0x01, 0x00, 0x01, 0x00, 0xFF, 0x03}` sent over UART;
* ~400 ns pulse duration;
* Method: N-MOSFET on the VCL lines powering the MCU core.

Run the script. If everything is set up correctly and Chip'olino is functioning properly, you will see the message **"Target synchronized"** and the byte **0xDC** in the **Log** output. Both of these indicate that the process is working as expected.



##### Debug note
```
"Target not synchronized" means there is no communication with the MCU. The issue is most likely related to the assembly of the add-on.
If the Log does not show a periodic line containing the byte `0xDC`, it means the synchronization process between Chip'olino and the RH850 does not reach the stage of receiving a response to the "Inquiry" command.
```

#### Dump firmware
After a successful glitch, do not disconnect the add-on from the Chip'olino board — the MCU remains powered and can process commands over UART. Connect the USB-UART adapter to the add-on and to the PC **before** the attack. Use only the RX, TX, and GND pins.
##### Attention!
```
Important! Do not connect the DTR-Reset line or 3.3V after the glitch. Opening the port triggers a reset.
```



The RH850 bootloader includes a memory read command with ID = 0x15, which can now be used.  
There is a ready-to-use script for this: _**/scripts/dump_rh850.py**_.
##### Attention!
```
Beforehand, you need to review the memory map specific to your MCU. There are quite a few variants in the RH850 series, and the correct documentation can be found based on the marking on the chip package.
For the MCU I had, the marking was 10233. Using this number, you can locate the addresses and sizes of the required memory regions in the documentation.
```







Use the script for dumping RH850 memory: ***/scripts/dump_rh850.py***
```bash
# dump code flash
py .\dump_rh850.py -p COM4 -a 0x0 0x07ffff -f rh850_code_flash.bin

# dump data flash
py .\dump_rh850.py -p COM4 -a 0xFF200000 0xFF207fff -f rh850_data_flash.bin
```
##### Note
```
Note that the COM port to be specified is not for Chip'olino, but for the USB-UART adapter.
```



### Links
* https://icanhack.nl/blog/rh850-glitch/
* https://github.com/I-CAN-hack/rh850-glitch
* Renesas Flash Programmer V3.17

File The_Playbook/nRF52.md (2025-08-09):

# nRF52

<details>
  <summary>Addon NRF52840</summary>
  




</details>
<details>
  <summary>Addon NRF52833</summary>
  




</details>
<details>
  <summary>Addon NRF52832</summary>
  




</details>

## Bypass APPROTECT
The entire nRF52 MCU series has a single type of protection: **APPROTECT**, which prevents reading the firmware. When this protection is enabled, access to the MCU via SWD is disabled. The protection is activated when the APPROTECT register is set to 0x00.


##### Note
```
It’s worth noting that this register is located in non-volatile memory (NVM). Moreover, rewriting this register is unrestricted—as long as you have access via SWD.
```

You can read more details in the original [research](https://limitedresults.com/2020/06/nrf52-debug-resurrection-approtect-bypass/).

For testing, you can solder the nRF52 chip onto the addon without any lock enabled and then activate the protection on it. To do this, power up the microcontroller, then switch the SWD pins to the external connector (by default, they are routed to the Pi Pico on the Chip'olino board). After that, you can connect a J-Link debugger to the powered microcontroller and enable the protection using the **nrfjprog** utility.

```bash
# Power on the nRF52 (3.3V).
py.exe chipctrl.py -p COM5 -gp 4 1

# Switch the SWD pins from the MCU to the external connector
py.exe chipctrl.py -p COM5 -swd ext

# Enable protection on the nRF52
nrfjprog --rbp ALL -f NRF52
```



### Glitch MCU
The goal of the attack is the moment of the MCU’s hardware initialization. When power is applied, the MCU checks the value in the APPROTECT register and, depending on it, may disable access via SWD.
##### Attention!
```
It is important to understand that this vulnerability has been fixed by the chip manufacturer. In early chip revisions, the protection was disabled by default.
During hardware initialization (before code execution), the protection was enabled if the APPROTECT register contained the corresponding value.
In newer revisions, the protection is enabled by default.
```



##### Note
```
The hardware revision of the MCU (HW revision) can be identified from the markings on the chip package.
```



#### Запуск атаки на NRF52
```bash
py.exe chipctrl.py -p COM5 -g -t nrf52 -o 198000 475000 -w 3 30
```

The offset and pulse width values vary significantly depending on the model (for example, nRF52840 or nRF52833) as well as the MCU revision. The screenshot below shows the segment on the DEC1 power line that should be targeted. The signal shape on DEC1 may differ substantially from the example, as MCU revisions have a strong influence. However, this segment can always be located. It consistently lasts about 15 µs and is preceded by a distinctive dip. From that dip to the end of the segment is always just under 20 µs.






During a successful brute-force attempt, the **Log** field should occasionally display the value **"23000000"**. This value appears when reading the **AHB-AP Identification Register** on a locked MCU. For an unlocked MCU, the value **0x24770011** is read (this applies specifically to nRF52).



he success of the attack is determined by the read value of the **AHB-AP ID**.

### Dump firmware

After a successful attack, the SWD AP becomes accessible. Then you can use J-Link directly to read out the firmware. Without disconnecting the addon from Chip'olino, switch the SWD pins from the nRF52 to the external connector and connect J-Link to it.

```bash
# Switch the SWD pins from the MCU to the external connector
py.exe chipctrl.py -p COM5 -swd ext
```





Once J-Link is connected, you can normally read the firmware from the nRF device—for example, using J-Mem.

##### Note
```
Nice bonus: usually, after rebooting the MCU, it gets locked again—but not always. Sometimes the MCU stays unlocked until the next forced lock.
```

### Glitch examples

The nRF52 chips, as mentioned earlier, vary significantly depending on the hardware revision and model. Therefore, below are oscilloscope screenshots for several MCUs in this series — both without glitch and during the glitch moment.
###### nRF52840 rev A0  (QIAA)

```bash
# Launch
py.exe chipctrl.py -p COM5 -g -t nrf52 -o 198300 296000 -w 12 25

# Result
Target synchronized
Glitching ---> Offset: 198695/296000, Width: 18/25, Log: b'24770011'
Glitch successed
Offset: 198695, Width: 18

#
Pulse duration: ~300 ns
```




###### nRF52833 rev A0 (QDAA)

```bash
# Launch
py.exe chipctrl.py -p COM5 -g -t nrf52 -o 255000 296000 -w 16 21

# Result
Target synchronized
Glitching ---> Offset: 255067/296000, Width: 19/21, Log: b'24770011'
Glitch successed
Offset: 255067, Width: 19

#
Pulse duration: ~250 nc
```





### Links
* https://limitedresults.com/2020/06/nrf52-debug-resurrection-approtect-bypass/

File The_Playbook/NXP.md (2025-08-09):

# NXP

### Supported devices

The repository includes descriptions of attacks on LPC microcontrollers. The most detailed analysis is written for [LPC2148](#lpc2148), which you should definitely review.
* [LPC2148](#lpc2148)
* [LPC1343](#lpc1343)
* ...
* Any similar LPC — using a universal addon.

## <span id="lpc2148">LPC2148</span>

<details>
  <summary>Addon LPC2148</summary>
  




</details>

### Bypass CRP1, CRP2

LPC2148 has several levels of protection. The current protection level is determined by the value stored in flash memory at address 0x1FC. This chapter covers bypassing protection levels CRP1 and CRP2. In both modes, debugging via JTAG is disabled, as well as certain commands executable by the bootloader.



This MCU always starts with the bootloader. The bootloader code checks the value at address 0x1FC and configures the MCU accordingly. One of these checks is located just before the MCU enters ISP mode. This check is the target of the attack. The goal is to get into ISP mode while making the MCU believe that no protection is enabled.



##### Note
```
You can dump the bootloader from the LPC2148, perform reverse engineering, and visually locate this check. 
The bootloader is located in memory from 0x7FFFD000 to 0x80000000.
```

Before performing the attack, make sure that one of the target protection levels—CRP1 or CRP2—is enabled. To do this, connect the addon to Chip'olino and start the attack. Chip'olino will power up the microcontroller and attempt to synchronize with the bootloader.



```bash
py.exe chipctrl.py -p COM6 -g -t lpc2148 -o 255800 270100 -w 275 295
```

If the glitching process starts as a result, it means the MCU is in CRP1 or CRP2 mode. Make sure the message "Target synchronized" appears.



##### Debug note
```
"Target not synchronized" значит, что нет связи с МК. Проблема может быть в сборке аддона или же в том, что установлен уровень защиты CRP3.
```

For preliminary training on a test MCU, you can conveniently set the protection via JTAG. Use the J-Mem utility together with J-Link. Connect the addon to Chip'olino, and then connect J-Link to the addon, as shown below.



To supply the required power to the MCU and prepare it for JTAG connection, you can run the attack script. If no protection is set, the script will simply power on the MCU. After that, you can connect via J-Link in the usual way. Write **0x12345678** or **0x87654321** to address 0x1FC to enable the protection.





#### Glitch MCU
For this MCU, the attack moment is during the bootloader code execution—that is, the time when the MCU boots up before any interaction with it. Then, the MCU loads into ISP mode and either responds to read commands or returns an error (if the glitch was unsuccessful). The attack itself is performed through the MCU's power line. The 3.3V power supply to the MCU passes through a multiplexer on the Chip'olino board, allowing the power line to be switched to ground at the moment of the attack. After attempting the glitch, Chip'olino will try to synchronize with the LPC2148 and request several bytes from the flash memory to verify whether the attack succeeded.




##### Note
```
A 12 MHz quartz crystal resonator is required for the MCU to operate, even in ISP (bootloader) mode.
```

Starting the attack on **LPC2148**:

```bash
py.exe chipctrl.py -p COM5 -g -t lpc2148 -o 255500 270100 -w 275 295
```



The message "LOCK" in the **Log** field means that the attack is proceeding correctly.

If you are using Chip'olino together with the addon, you can simply run the script as shown above. The offset and pulse width parameters won’t change much. If something doesn’t work out, below are oscilloscope screenshots of a successful attack. You can compare the signal shapes and timing parameters, then fine-tune the offset and duration accordingly.

Carefully study the screenshots. They can be a great help if you encounter any problems.






###### Glitch parameters
* ~110 µs from the MCU start (hardware initialization on the screenshot);
* ~83 µs from the start of bootloader execution (bootloader exec start on the screenshot);
* ~1.2 µs pulse duration;
* Method: multiplexer on the MCU power line (3.3V).



#### Dump firmware
After a successful attack, do not disconnect the addon from Chip'olino, so it will remain powered and ready for communication via UART. It’s best to connect the USB-UART adapter to the addon and PC before starting the attack. The firmware is stored in the flash memory, and its size depends on the MCU — you need to study the memory map of your MCU in advance.



For the LPC2148, you need to dump the memory region from 0x00000000 to 0x00080000. There is a script for this: _**/scripts/dump_lpc2148.py**_. Run it as shown below, making sure to specify the port corresponding to your USB-UART adapter.

```bash
# Dump of the LPC2148 flash memory region to the file **flash_lpc2148.bin**
py.exe .\dump_lpc2148.py -p COM8 -a 0 0x00080000 -f flash_lpc2148.bin
```

Memory dumping via UART is not the fastest procedure. This can be avoided. You can read only the 0th sector via UART, then erase just the 0th sector (using _**/scripts/erase_lpc2148.py**_). After that, the protection on the MCU will be removed since the value that determines the protection level is located at address 0x1FC (within the 0th sector). The remaining part of the firmware can then be read via JTAG.



```bash
# Dump the 0th memory sector of the LPC2148 into the file zero_sector.bin
py.exe .\dump_lpc2148.py -p COM8 -a 0 0x1000 -f zero_sector.bin

# Once the 0th sector is read, it can be erased
py .\erase_lpc2148.py -p COM8
```








All the actions described above should be done without disconnecting the addon from Chip'olino. After erasing the 0th sector, the chip needs to be rebooted once. This can be done with the following commands:

```bash
# Power off the MCU
py.exe chipctrl.py -p COM5 -gp 4 0
# Power on the MCU
py.exe chipctrl.py -p COM5 -gp 4 1
```

After reboot, JTAG should work.
#### Links
* https://www.nxp.com/docs/en/user-guide/UM10139.pdf
* https://recon.cx/2017/brussels/resources/slides/RECON-BRX-2017-Breaking_CRP_on_NXP_LPC_Microcontrollers_slides.pdf

## <span id="lpc1343">LPC1343</span>

The attack on LPC1343 is similar to the one for LPC2148, with a few differences:
- Slightly different UART packet format — so different scripts are used;    
- SWD interface instead of JTAG.    
Otherwise, there are no major differences. That’s why the detailed explanation is given only for LPC2148 — it’s best to read that first before moving on to LPC1343.

<details>
  <summary>Addon LPC1343</summary>
  




</details>

### Bypass CRP1, CRP2
#### Glitch MCU





Starting the attack on LPC1343:

```bash
py.exe chipctrl.py -p COM6 -g -t lpc1343 -o 15300 190100 -w 14 20
```



The message "LOCK" in the **Log** field means that the attack is proceeding correctly.

You can compare both the signal shapes and timing parameters, then fine-tune the offset and pulse duration accordingly. Carefully study the screenshots — they can be extremely helpful if any issues arise.





###### Glitch parameters
* ~65 µs from MCU start;
* ~55 µs from bootloader execution start;
* ~75 ns pulse duration;
* Method: multiplexer on the MCU’s 3.3V power line.
#### Dump firmware
After a successful attack, do not disconnect the addon from Chip'olino—this way it will remain powered and ready for communication via UART. It’s best to connect the USB-UART adapter to both the addon and the PC before starting the attack. The firmware is located in the flash memory; its size depends on the microcontroller (MCU), so you should first study the memory map of your specific MCU.

```bash
# Dump the flash memory region of the LPC1343 to the file flash_lpc1343.bin
py.exe .\dump_lpc1343.py -p COM8 -a 0 0x8000 -f flash_lpc1343.bin
```

Dumping memory via UART is not the fastest procedure. This can be avoided. You can read only the 0th sector via UART, then erase only the 0th sector (_**/scripts/erase_lpc1343.py**_). After that, the protection on the MCU will be removed because the value that defines the protection level is located at address 0x1FC (in the 0th sector). The remaining part of the firmware can then be read via SWD.



```bash
# Dump the 0th sector of LPC1343 memory to the file zero_sector.bin
py.exe .\dump_lpc1343.py -p COM8 -a 0 0x1000 -f zero_sector.bin

# Once the 0th sector is read, it can be erased
py .\erase_lpc1343.py -p COM8
```





All the actions mentioned above should be performed without disconnecting the addon from Chip'olino. After erasing the 0th sector, the chip will need to be rebooted once. This can be done with the following commands:

```bash
# Power off MCU
py.exe chipctrl.py -p COM5 -gp 4 0
# Power on MCU
py.exe chipctrl.py -p COM5 -gp 4 1

# Switch the SWD pins from the MCU to the connector for external connection
py.exe chipctrl.py -p COM6 -swd ext
```

After the reboot, SWD should be functional.


#### Links
* https://www.nxp.com/docs/en/user-guide/UM10139.pdf
* https://recon.cx/2017/brussels/resources/slides/RECON-BRX-2017-Breaking_CRP_on_NXP_LPC_Microcontrollers_slides.pdf

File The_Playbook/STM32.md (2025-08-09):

# STM32

## Description 

STM32 microcontrollers have a protection mechanism called **Readout Protection (RDP)**. For more advanced chip versions, it's accurate to say there are three protection levels, where level 0 means no protection.
- **RDP1** – access to flash memory is restricted.    
- **RDP2** – the debug interface is completely disabled.    

It's also typically stated that a chip cannot be returned from RDP2 to a previous state, while it _is_ possible to downgrade from RDP1 — but only with a complete erasure of the flash memory.

### Supported devices

The repository contains a description of attacks on both **RDP1** and **RDP2**. The most detailed analysis is provided for the [STM32F466](#stm32f466) — it is essential to study this one. For all other STM32 series, only timing parameters and oscilloscope waveforms are available.
* [STM32F466](#stm32f466)
* [STM32F401](#stm32f401)
* [STM32F411](#stm32f401)
* ...
* any STM32 - using the universal add-on.
###### Note
All STM32 microcontrollers have a similar protection mechanism, but there are some minor differences. Make sure to read the documentation for your specific MCU.
* STM32F401 ([RM0368 Reference manual](https://www.st.com/resource/en/reference_manual/rm0368-stm32f401xbc-and-stm32f401xde-advanced-armbased-32bit-mcus-stmicroelectronics.pdf))
* STM32F411 ([RM0383 Reference manual](https://www.st.com/resource/en/reference_manual/rm0383-stm32f411xce-advanced-armbased-32bit-mcus-stmicroelectronics.pdf))
* STM32F466 ([RM0390 Reference manual](https://www.st.com/resource/en/reference_manual/rm0390-stm32f446xx-advanced-armbased-32bit-mcus-stmicroelectronics.pdf))

### General commands

In the general case, you can power on an STM32 microcontroller soldered onto the add-on as follows:
```bash
# Power on STM32 (3.3V)
py.exe chipctrl.py -p COM23 -gp 4 1
# Do not pull the microcontroller's Reset pin to ground
py.exe chipctrl.py -p COM23 -gp 3 0

# Switch SWD pins from the microcontroller to the external connector
py.exe chipctrl.py -p COM23 -swd ext
```

After this, the microcontroller on the add-on will be powered on in bootloader mode, and you will be able to connect to it via the external SWD connector on **Chip'olino**, using **J-Link**/**ST-Link** and **STM32CubeProgrammer**. This allows you to set protection levels or view the current one. You can also check the bootloader version on the microcontroller.



### RDP1 
The **RDP1 attack** involves powering on the microcontroller in **bootloader mode** (system memory). Then, an attempt is made to read the flash memory using the standard bootloader command **0x11 (Read Memory)**. This command can be sent via various interfaces — **UART, SPI, I2C, CAN, or USB**.



###### Note
``` Markdown
The supported interfaces of the microcontroller can be found in the AN2606 Application note STM32 microcontroller system memory boot mode.
Support depends not only on the MCU series but also on the version of its bootloader.
```

For the attack, it is necessary to glitch the microcontroller’s core immediately after sending the command. If the protection level is set to **RDP1**, the response to the request will be a **NACK (0x1F)**. The goal is to find the glitch timing and parameters that cause the microcontroller to respond with an **ACK (0x79)** instead.






The most popular power glitch attack method on STM32 involves placing an N-MOSFET transistor on the **Vcap** pin (core power), if it is available. If there are two Vcap pins, you can experiment to see whether it's better to glitch one pin or both simultaneously. Sometimes, the Vcap pin is absent; in that case, the attack is performed on the main MCU power line (3.3V).



For precise timing of the attack, it is best to synchronize directly to the edges on the interface lines. For example, the optimal attack method on the STM32F407 involves starting the timing count from the last edge on the **UART_TX** line. That is, once the read memory command is sent, the timing begins. For other STM32 series, it is more convenient to synchronize to the edges on the **SPI_CLK** line. Synchronizing to SPI provides a more accurate result compared to UART.

### RDP2 
The **RDP2 attack** involves targeting the microcontroller during its initial startup. The attack occurs after the MCU reset and before code execution begins. The approximate attack window on all STM32 devices can be identified using an oscilloscope — a characteristic pattern appears on the power supply line.





You can determine whether the protection has been bypassed by reading the **IDCODE** (via SWD). If after the attack the MCU believes it is not in **RDP2**, the real IDCODE will be read. The actual value depends on the STM32 series. For example, for STM32F4xx, it is **0x2BA01477**. If the protection is still active, the IDCODE cannot be read; for Chip'olino, this will appear as **0xFFFFFFFF**.

The most popular power glitch attack method on STM32 involves installing an N-MOSFET transistor on the **Vcap** pin (core power), if available. If there are two Vcap pins, you can experiment with whether it's better to glitch one pin or both simultaneously. Sometimes, the Vcap pin is absent; in that case, the attack is performed on the MCU's main 3.3V power line. For precise timing of the attack, it is best to synchronize directly to the rising edge of the power supply to the MCU or the Reset signal.



## <span id="stm32f466">STM32F466</span>

<details>
  <summary>Addon STM32F466</summary>
  




</details>

### <span id="spi_way">Bypass RDP1 (SPI way)</span>

The attack on **STM32F466** is best performed with synchronization to the **SPI_CLK** line (if the bootloader supports SPI) at the moment the memory read command is sent. For this, the **PIO state machine** is configured to wait for **24 clock edges** on the SPI_CLK line starting from the beginning of the **0x11 command** transmission. After that, the countdown to the glitch begins. In 24 SPI clock cycles, three bytes are sent from master to slave. The SPI command for the bootloader consists of the bytes: **{0x5A, cmd_byte, cksm_cmd_byte}**. In the case of the Read Memory command, this is: **{0x5A, 0x11, 0xEE}**.

On add-ons where it's possible to synchronize with edges on **SPI**, **UART**, or **CAN**, the corresponding resistor must be soldered in place. For example, for **STM32F466 + SPI**:



#### Glitch MCU

To launch the attack, solder the **STM32F466** onto the add-on **[\pcb\Addons\STM\STM32F446RCT6_revA](\pcb\Addons\STM\STM32F446RCT6_revA)**. Then, run the script:

```bash
py.exe chipctrl.py -p COM23 -g -t stm32f4xx_spi_rdp1 -o 220 260 -w 23 35
```



##### Debug note
```
"Target not synchronized" after starting the attack means that either the add-on is assembled incorrectly, or the protection level is set to RDP2.
```

##### Debug note
```
An occasionally flashing "NACK" message in the Log field during brute-force attempts indicates that the process is running as expected.
```



You can observe and debug the process using an oscilloscope. Below are waveforms of a successful attack. They can be used to examine the timing characteristics of the glitch.






###### Glitch parameters
* ~1 µs from the 24th clock edge of the "Read Memory" command transmission;
* ~100 ns pulse duration;
* Method: N-MOSFET on the **Vcap** core power lines of the MCU;
* Capacitor value: **1 µF**.

#### Dump firmware

The process of extracting firmware from a locked STM32 is quite lengthy. The bootloader command that gets disrupted during the attack allows reading only **0x100 bytes** at a time. One attack attempt isn’t enough—you'll have to repeat the glitch for each subsequent memory chunk. By default, the script **`/scripts/chipctrl.py`** with the **`-g`** argument sends the **GLITCH** command to Chip'olino. For all STM32 devices, the firmware includes the address of the **system memory** (bootloader). So all test runs always attempt to read the first **0x100 bytes** of the bootloader.
##### Attention!
``` Markdown
During a glitch attack on STM32, there is a very high chance of disrupting the operation of the microcontroller’s Flash Memory Controller (FMC). This can lead to data loss in flash memory.
```

To avoid this, you should first fine-tune the attack parameters on a **test microcontroller** and **narrow the brute-force window as much as possible**. Everything described in the **Glitch MCU** section helps with initially identifying the timing and parameters of the attack.

After a successful glitch, you can run the script **chipctrl.py** with the **-dump** argument to view the contents of the buffer containing the data read as a result of the attack.

```bash
# Viewing the data buffer after an STM32 RDP1 attack
py.exe chipctrl.py -p COM23 -dump
```


The **dump** command will display both the contents of the buffer and the memory address from which the data was read. In this case, for the STM32F466, the memory at address **0x1FFF0000** (system memory) was read.

To loop the attack and sequentially read memory, use the script **/scripts/dump_stm32.py**.
##### Note
```
Note how precisely the attack parameters can be tuned when synchronized with SPI.
```

```bash
py.exe .\dump_stm32.py -p COM23 -t stm32f4xx_spi_rdp1 -o 230 232 -w 30 32 -a 0x8000000 0x8000600 -f flash_466.bin
```

When launched this way, Chip'olino will continuously glitch, cycling through both the offset and pulse width until it manages to read a chunk of memory at the initial address. Then the address will increase by 0x100, and the process will repeat. In this case, you need to specify the start and end memory addresses using the **-a** argument, and the file where the read data will be saved using the **-f** argument.



##### Attention!
``` Markdown
You can avoid disrupting the Flash Memory Controller (FMC) by precisely tuning the attack parameters. To do this, you need to run tests on a test MCU beforehand. Solder a test MCU onto the add-on and write any 0x100-byte pattern into its flash memory. Then adjust the attack parameters so that the MCU does **not** get erased.
```

For this kind of testing, there is the script **/scripts/test_erase_stm32.py**.

```bash
py.exe .\test_erase_stm32.py -p COM23 -t stm32f4xx_spi_rdp1 -o 230 232 -w 30 32 -a 0x8000000 -f test466.bin -c cmp_stm401.bin
```

The script continuously attempts to read data from a single address and compares it with the data in the specified file. In this case, a pattern was pre-written to memory at address **0x8000000**:





If the parameters are not set very precisely, a failure will still occur. It looks like this:



Usually, when the FMC fails, the flash is filled with bytes of **0x00**, rather than **0xFF** as with a normal mass erase. Immediately after detecting such a failure, you can connect to the MCU via SWD and check what happened. In the option byte responsible for the RDP value, instead of **0xBB**, it will be **0xFF**. Additionally, the **SRPMOD protection bit** will be set. All this indicates a failure in the flash controller’s operation.

##### Note
```
Use test MCUs. Narrow the brute-force window to a minimum. Find an attack point where the FMC does not fail.
```

##### Note
```
Not all STM32 series experience FMC failures so easily, but on STM32F4xx this problem is quite common. It’s worth noting that sometimes this can be easily avoided by performing the attack over UART instead of SPI, or vice versa.
```

### <span id="uart_way">Bypass RDP1 (UART way)</span>

The attack on **STM32F466** can be performed synchronized to the **UART_TX** line (if the bootloader supports UART) at the moment the memory read command is sent. For this, the **PIO state machine** is configured to wait for **5 edges** on the UART_TX line starting from the beginning of the **0x11 command** transmission. After that, the countdown to the glitch begins. The UART command for the bootloader consists of the bytes **{cmd_byte, cksm_cmd_byte}**. In the case of the Read Memory command, this is: **{0x11, 0xEE}**.

On add-ons where it is possible to synchronize to the edges of SPI, UART, or CAN lines, the corresponding resistor must be soldered. For example, for **STM32F466 + UART**:



#### Glitch MCU

To start the attack, solder the STM32F466 onto the add-on **[\pcb\Addons\STM\STM32F446RCT6_revA](\pcb\Addons\STM\STM32F446RCT6_revA)**. Then run the script:

```bash
py.exe chipctrl.py -p COM23 -g -p COM23 -t stm32f4xx_uart_rdp1 -o 1660 1700 -w 20 30
```



##### Debug note
```
"Target not synchronized" after starting the attack means that either the add-on is assembled incorrectly or the protection level is set to RDP2.
```

##### Debug note
```
An intermittently flashing "NACK" message in the **Log** field during the brute-force process indicates that the process is proceeding normally.
```



You can observe and debug the process using an oscilloscope. Below are waveforms of a successful attack, which show the timing characteristics of the glitch.






###### Glitch parameters
- ~7 µs from the last edge of the "read memory" command transmission;    
- ~100 ns pulse duration;    
- Method: N-MOSFET on the Vcap core power lines of the MCU;    
- Capacitor value: 1 µF.

#### Dump firmware

The process of extracting firmware from a locked STM32 is quite lengthy. The bootloader command disrupted during the attack only allows reading **0x100 bytes** at a time. One attack is not enough—you will have to perform the glitch repeatedly to read each subsequent chunk of memory. By default, the script **/scripts/chipctrl.py** with the **-g** argument sends the **GLITCH** command to Chip'olino. For all STM32 devices, the firmware contains the address of the system memory section (bootloader). Therefore, all test runs always attempt to read the first **0x100 bytes** of the bootloader.

##### Attention!
```
During a glitch attack on STM32, there is a very high chance of disrupting the operation of the MCU's Flash Memory Controller (FMC). This can lead to data loss in the flash memory.
```

To avoid this, you need to fine-tune the attack parameters on a test MCU and narrow the brute-force window to a minimum. Everything described in the **Glitch MCU** chapter helps to initially identify the timing and parameters of the attack.
After a successful glitch, you can run the script **chipctrl.py** with the **-dump** argument to view the contents of the buffer with the data read as a result of the attack.

```bash
# Viewing the data buffer after an STM32 RDP1 attack
py.exe chipctrl.py -p COM23 -dump
```


The **dump** command will display both the contents of the buffer and the memory address from which the data was read. In this case, for the STM32F466, the memory at address **0x1FFF0000** (system memory) was read. To loop the attack and sequentially read memory, use the script **/scripts/dump_stm32.py**.
###### Note
```
Note how precisely the attack parameters can be tuned.
```

```bash
py.exe .\dump_stm32.py -p COM23 -t stm32f4xx_uart_rdp1 -o 1660 1690 -w 23 28 -a 0x8000000 0x8000800 -f test466.bin
```

When launched this way, Chip'olino will continuously glitch, cycling through both the offset and pulse width until it successfully reads a chunk of memory at the initial address. Then the address value will increase by 0x100, and the process will repeat. In this case, you need to specify the start and end memory addresses using the **-a** argument and the file where the read data will be saved using the **-f** argument.



##### Attention!
```
You can avoid FMC failure by precisely tuning the attack parameters. To do this, you first need to run tests on a test MCU. Solder a test MCU onto the add-on, write any 0x100-byte pattern into its flash memory, and adjust the attack parameters so that the MCU does not get erased.
```

There is a script for such testing: **/scripts/test_erase_stm32.py**.

```bash
py.exe .\test_erase_stm32.py -p COM23 -t stm32f4xx_uart_rdp1 -o 1665 1675 -w 24 26 -a 0x8000000 0x8000800 -f test466.bin -c cmp_stm401.bin
```

The script repeatedly tries to read data from a single address and compares it with the data in the specified file. In this case, a pattern was pre-written to memory at address **0x8000000**:





If the parameters are not set precisely enough, a failure will still occur. It looks like this:



Typically, when an FMC failure occurs, the flash memory gets filled with bytes of 0x00 instead of 0xFF, which is what happens during a normal mass erase. Immediately after detecting such a failure, you can connect to the MCU via SWD and check what happened. In the option byte responsible for RDP, the value is no longer 0xBB but 0xFF. Additionally, the SRPMOD protection bit is set. All this indicates a malfunction in the flash controller.

##### Note
```
Use test MCUs. Narrow the brute-force window to a minimum. Find an attack timing where the FMC does not fail.
```

##### Note
```
Not all STM32 series experience FMC failures so easily, but on STM32F4xx this problem is quite pronounced. It’s worth noting that sometimes this can be easily avoided by performing the attack over UART instead of SPI, or vice versa.
```

### Bypass RDP2

#### Glitch MCU

To start the attack, solder the STM32F466 onto the add-on **[\pcb\Addons\STM\STM32F446RCT6_revA](\pcb\Addons\STM\STM32F446RCT6_revA)**. Then run the script:

```bash
py.exe chipctrl.py -p COM23 -g -p COM23 -t stm32f4xx_rdp2 -o 410000 500500 -w 10 50
```



##### Debug note
```
"0xFFFFFFFF" in the Log field after starting the attack means that the SWDIO line is pulled up to 3.3V — this indicates that the add-on is assembled correctly and the MCU is powering on.
```

A successful attack is characterized by a correctly read IDCODE:



You can observe the process and debug it using an oscilloscope. Below are oscilloscope screenshots of a successful attack. They show the timing characteristics of the attack.






###### Glitch parameters
- ~ 45–60 µs from the start of the hardware initialization process;    
- ~ 200 µs from the power-up of the LDO for the MCU core;    
- Pulse duration: ~100 ns;    
- Method: N-MOSFET on the Vcap lines powering the MCU core;    
- Capacitor capacitance: 1 µF.

#### Dump firmware

After a successful attack, the MCU's SWD will still be operational. The MCU will think it is in RDP1 mode. Without disconnecting the add-on from Chip'olino, switch the SWD lines from the MCU to the external connector and connect to it via ST-Link.

```bash
py.exe chipctrl.py -p COM23 -g -p COM23 -swd ext
```

Since the failure results in an error when reading the option bytes, the RDP field in STM32CubeProgrammer will show any value different from 0xCC (RDP2).



This is where it gets really interesting. Despite all the warnings that the MCU cannot be recovered after setting RDP2, it _can_ be restored. **If the goal is to further read the firmware, then by bypassing the RDP2 protection, you need to set it to RDP1 (0xBB); in this case, the flash memory will not be erased.** If the firmware is not needed, you can switch to RDP0 (0xAA), which will erase the chip’s memory and return it to factory state.



After that, the firmware can be extracted as described in the chapter [**Bypass RDP1 (UART way)**](#uart_way) or  [**Bypass RDP1 (SPI way)**](#spi_way)

##### Attention!
```
When attempting to glitch the STM32 operation, it is possible to disrupt the FMC (Flash Memory Controller), which can lead to loss of data in the flash memory. You can avoid FMC failure by precisely tuning the attack parameters. To do this, you first need to run tests on a test MCU. Solder a test MCU onto the add-on, write any 0x100-byte pattern into its flash memory, and adjust the attack parameters so that the MCU does not get erased.
```

##### Note
```
Use test MCUs. Narrow the search window to a minimum. Choose an attack timing where the FMC does not fail. It is also better to reduce the pulse duration to the shortest possible time.
```

## <span id="stm32f401">STM32F401, STM32F411</span>

<details>
  <summary>Addon STM32F401/411</summary>
  




</details>

### Bypass RDP1
#### Glitch MCU
To start the attack, solder the STM32F466 onto the add-on **[\pcb\Addons\STM\STM32F411CCU_revA**](\pcb\Addons\STM\STM32F411CCU_revA)**. Then run the script:

```bash
py.exe chipctrl.py -p COM6 -g -t stm32f4xx_spi_rdp1 -o 220 260 -w 10 23
```



You can observe and debug the process using an oscilloscope. Below are oscilloscope traces of a successful glitch attack. They show the timing characteristics of the attack.






###### Glitch parameters
- ~ 1 µs after the 24th rising edge of the "read memory" command transmission;    
- Pulse duration  ~100 ns;    
- Method: N-MOSFET on the Vcap lines powering the MCU core.

#### Dump firmware

```bash
py.exe .\dump_stm32.py -p COM6 -t stm32f4xx_spi_rdp1 -o 239 240 -w 16 17 -a 0x8000000 0x8000600 -f flash_401.bin
```

```bash
py.exe .\test_erase_stm32.py -p COM6 -t stm32f4xx_spi_rdp1 -o 240 242 -w 17 18 -a 0x8000000 -f test401.bin -c cmp_stm401.bin
```

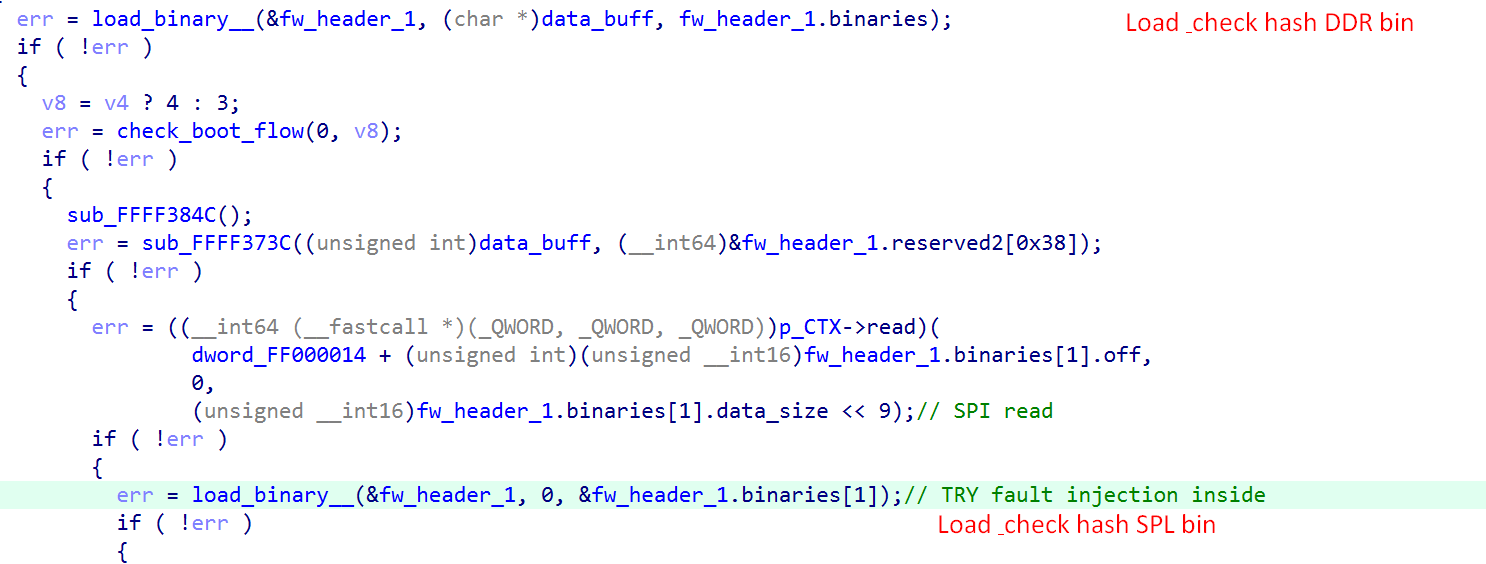
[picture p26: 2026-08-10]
The_Playbook/pics/rk3588/rk3588_8.png

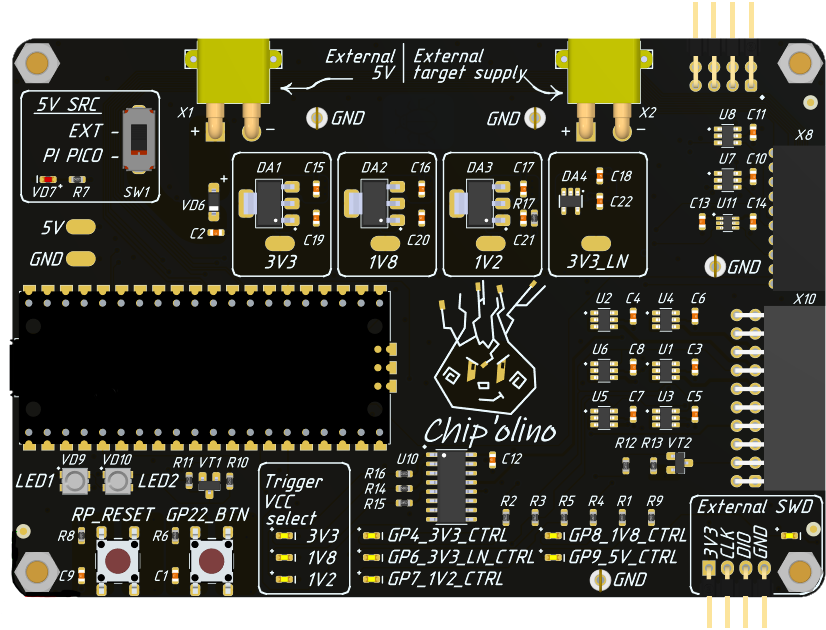
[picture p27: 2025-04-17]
The_Playbook/pics/pcb_pics/chipolino_1.png

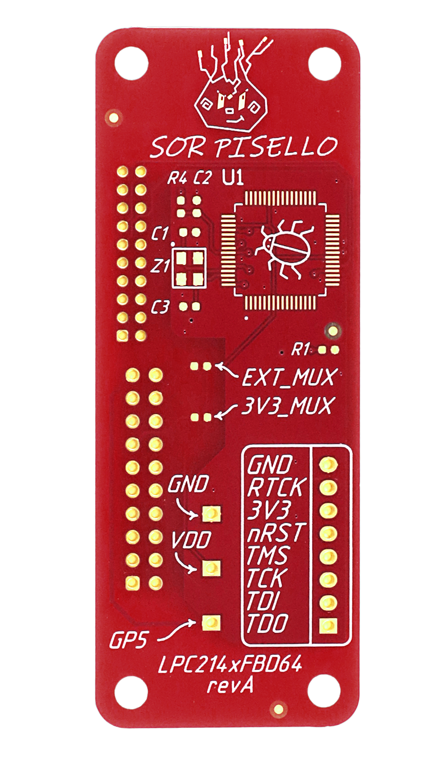
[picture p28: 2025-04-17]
The_Playbook/pics/pcb_pics/SOR PISELLO.png

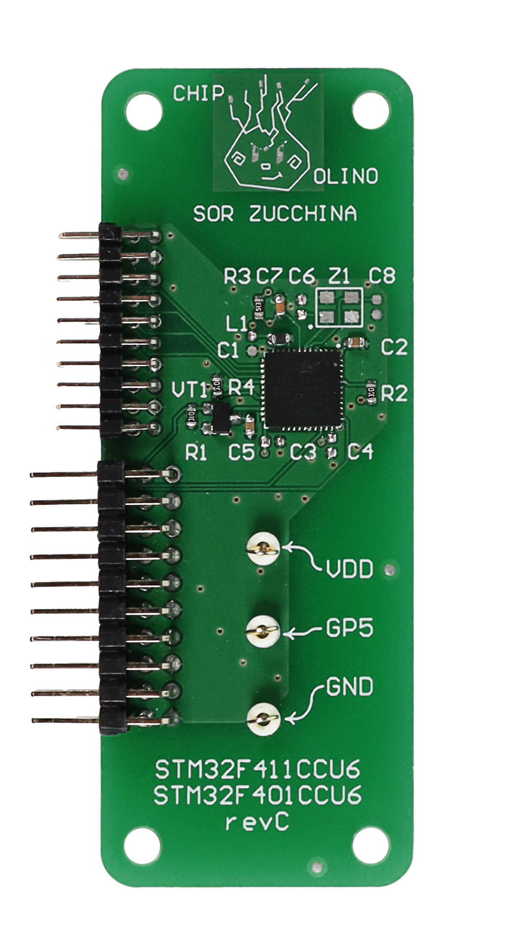
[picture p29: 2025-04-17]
The_Playbook/pics/pcb_pics/SOR ZUCCHINA.png

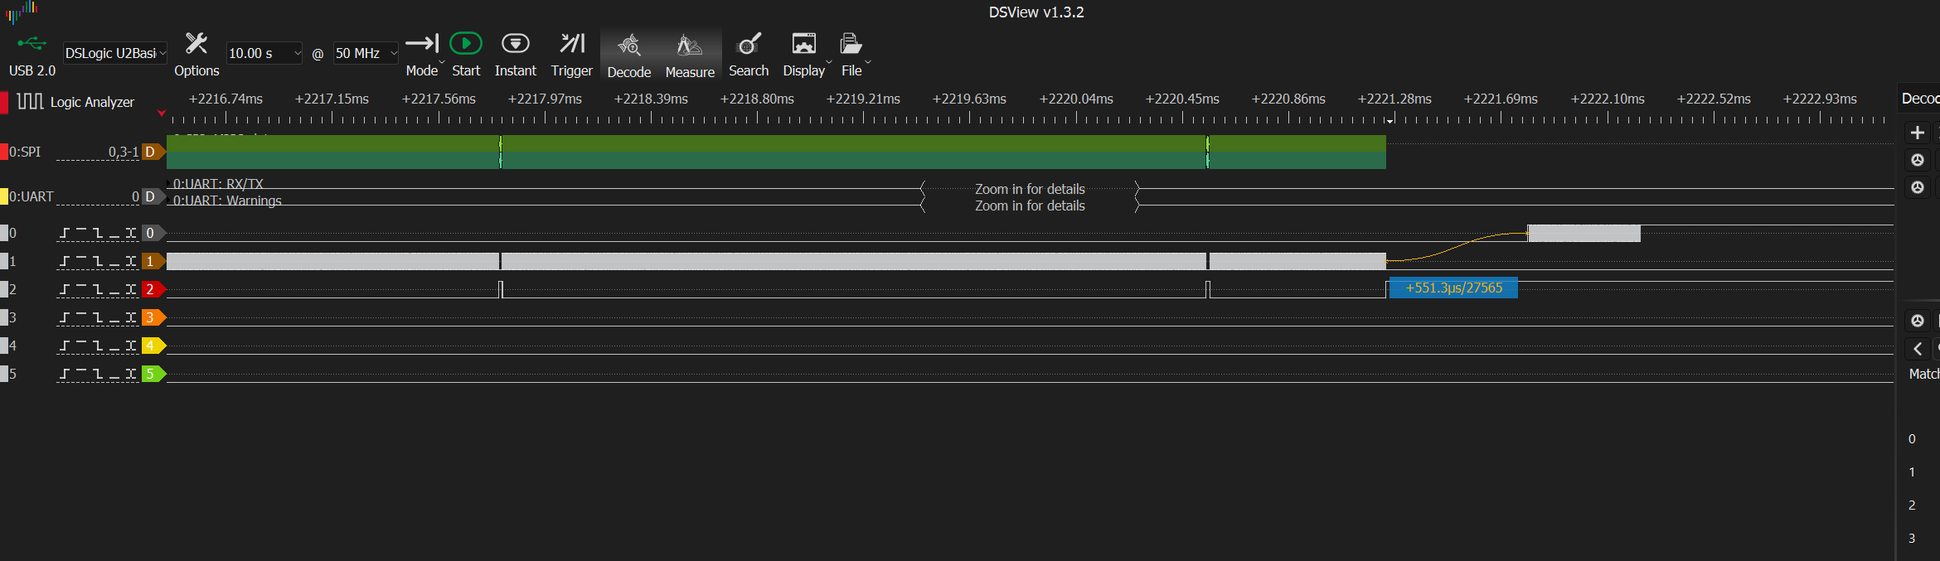
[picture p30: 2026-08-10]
The_Playbook/pics/rk3588/rk3588_11.png

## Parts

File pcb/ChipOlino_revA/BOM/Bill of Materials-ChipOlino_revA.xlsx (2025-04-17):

Designator | Description/Value | PartNumber | Quantity
C1, C2, C3, C4, C5, C6, C7, C8, C9, C10, C11, C12, C13, C14, C15, C16, C17 | Ceramic capacitor, 0603, 0.1u, ±10%, 50V, X7R, -55...+125°C | GRM188R71H104K | 17
C18, C19, C20, C21, C22 | Ceramic capacitor, 0603, 10u, ±10%, 16V, X7R, -55...+125°C | GRM188R61C106KAALD | 5
DA1 | LDO voltage regulator, +3.3V, 800mA [SOT-223] | LD1117S33TR | 1
DA2 | LDO voltage regulator, +1.8V, 800mA [SOT-223] | LD1117S18TR | 1
DA3 | LDO voltage regulator, +1.2V, 800mA [SOT-223] | LD1117S12TR | 1
DA4 | LDO voltage regulator, Ultra-Low Noise, +3.3V, 150mA [SOT23-5] | ADP150AUJZ-3.3 | 1
MP1, MP2, MP3, MP4 | Hexagon Nut M3 DIN 934 | Nut M3 DIN 934 | 4
MP5, MP6, MP7, MP8 | PCB brass stand, M3, 10mm | PCHSN-10 | 4
R1, R2, R3, R4, R5, R9, R14, R15, R16 | Resistor thick-film, 0603, 1k, ±5%, 0.1W, -55...+125°C | RC0603JR-071KL | 9
R6, R8, R13 | Resistor thick-film, 0603, 10k, ±5%, 0.1W, -55...+125°C | RC0603JR-0710KL | 3
R7 | Resistor thick-film, 0603, 3.3k, ±5%, 0.1W, -55...+125°C | RC0603JR-073K3L | 1
R10, R11 | Resistor thick-film, 0603, 2k, ±1%, 0.1W, -55...+125°C | RC0603JR-072KL | 2
R12 | Resistor thick-film, 0603, 100, ±1%, 0.1W, -55...+125°C | RC0603FR-07100RL | 1
R17 | Resistor thick-film, 0603, 120, ±1%, 0.1W, -55...+125°C | RC0603JR-07120RL | 1
SB1, SB2 | Surface Mount Tactile Switch Type 6*6, DTSM-62 | DTSM-62 | 2
SW1 | Slide switch, KLS7-SS03-12D02-EG-3.0 | KLS7-SS03-12D02-EG-3.0 | 1
U1, U2, U3, U4, U5, U6, U7, U8 | Analog multiplexer 1 channel, SOT23-6 | RS2257XH | 8
U9 | Development board RP2040 | SC0915 | 1
U10 | Dual single-pole quad-throw analog switch, SOIC-16 | 74HC4052D | 1
U11 | Voltage Level Translator Bidirectional 1 Circuit 1 Channel TSOP-6 | 74LVC1T45GW | 1
VD1, VD2, VD3, VD4, VD5, VD8, VD11, VD12, VD13 | LED, 0603, YELLOW | GNL-0603UYC | 9
VD6 | Diode Shottky, SOD123 | MBR0520 | 1
VD7 | LED, 0603, RED | GNL-0603SRC | 1
VD9, VD10 | SMD integrated light source RGB LED, LED3535 | WS2812B-Mini | 2
VT1 | N-MOSFET Transistor, 50V, 0.2A, SOT-23-23 | BSS138 | 1
VT2 | N-MOSFET Transistor, 20V, 4.2A, SOT-23-23 | IRLML2502TRPBF | 1
X1, X2 | Socket; DC supply; XT30; male; PIN: 2; on PCBs; THT; Colour: yellow | XT30PW-M | 2
X4, X5, X6, X7 | PCB Test Point Through Hole Mount | TEST-1W | 4
X8 | PLD connector 20 pin, 2.0mm, Female, Right angel, DS1026-13-2x10 | DS1026-13-2x10 | 1
X9 | PLD connector 2x4 pin, 2.54mm, Right angel, DS1022-2x4 | DS1022-2x4 | 1
X10 | PLD connector 20 pin, 2.54mm, Female, Right angel, DS1024-2x10R | DS1024-2x10R | 1
X11 | PLS connector 4 pin, 2.54mm | DS1022-01x04 | 1

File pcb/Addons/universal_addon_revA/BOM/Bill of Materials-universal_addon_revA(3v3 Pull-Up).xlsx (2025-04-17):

Designator | Description/Value | PartNumber | Quantity
C1 | Ceramic capacitor, 0603, 0.1u, ±10%, 50V, X7R, -55...+125°C | GRM188R71H104K | 1
MP1, MP2, MP3, MP4 | Hexagon Nut M3 DIN 934 | Nut M3 DIN 934 | 4
MP5, MP6, MP7, MP8 | PCB brass stand, M3, 10mm | PCHSN-10 | 4
R3 | Resistor thick-film, 0603, 10k, ±5%, 0.1W, -55...+125°C | RC0603JR-0710KL | 1
R4 | Resistor thick-film, 0603, 100, ±1%, 0.1W, -55...+125°C | RC0603FR-07100RL | 1
R5 | Resistor thick-film, 0603, 10k, ±1%, 0.1W, -55...+125°C | RC0603FR-0710KL | 1
VT1 | N-MOSFET Transistor, 20V, 4.2A, SOT-23-23 | IRLML2502TRPBF | 1
X1 | PLD Connector 20 pin, 2.0mm, Male, DS1025-06-2x10 | DS1025-06-2x10 | 1
X2 | PLD Connector 20 pin, 2.54mm, Male, DS1022-2x10R | DS1022-2x10R | 1
X22, X23, X24, X25 | PCB Test Point Through Hole Mount | TEST-1W | 4

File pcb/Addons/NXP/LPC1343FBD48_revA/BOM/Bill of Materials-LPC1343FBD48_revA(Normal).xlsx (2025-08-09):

Designator | Description/Value | PartNumber | Quantity
C2 | Ceramic capacitor, 0603, 0.1u, ±10%, 50V, X7R, -55...+125°C | GRM188R71H104K | 1
MP1, MP2, MP3, MP4 | Hexagon Nut M3 DIN 934 | Nut M3 DIN 934 | 4
MP5, MP6, MP7, MP8 | PCB brass stand, M3, 10mm | PCHSN-10 | 4
R2, R3, R4 | Resistor thick-film, 0603, 10k, ±5%, 0.1W, -55...+125°C | RC0603JR-0710KL | 3
U1 | Microcontroller LPC1343FBD48, LQFP-48 | LPC1343FBD48 | 1
X1, X2, X3 | PCB Test Point Through Hole Mount | TEST-1W | 3
X4 | PLD Connector 20 pin, 2.0mm, Male, DS1025-06-2x10 | DS1025-06-2x10 | 1
X5 | PLD Connector 20 pin, 2.54mm, Male, DS1022-2x10R | DS1022-2x10R | 1
X6 | PLS Connector 3 pin, 2.54mm, Male | DS1021-01x3 | 1

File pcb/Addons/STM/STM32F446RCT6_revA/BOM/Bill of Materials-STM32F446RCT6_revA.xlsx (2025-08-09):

Designator | Description/Value | PartNumber | Quantity
C1, C2, C3, C4, C5, C6 | Ceramic capacitor, 0603, 0.1u, ±10%, 50V, X7R, -55...+125°C | GRM188R71H104K | 6
C7, C10 | Ceramic capacitor, 0603, 15, ±10%, 100V, C0G, -55...+125°C | GRM1885C2A150J | 2
C8 | Ceramic capacitor, 0603, 1u, ±10%, 25V, X7R, -55...+125°C | GCM188R71E105KA64D | 1
C9 | Ceramic capacitor, 0603, 2.2u, ±10%, 10V, X7R, -55...+125°C | GRM188R71A225KE15D | 1
MP1, MP2, MP3, MP4 | Hexagon Nut M3 DIN 934 | Nut M3 DIN 934 | 4
MP5, MP6, MP7, MP8 | PCB brass stand, M3, 10mm | PCHSN-10 | 4
R1, R2 | Resistor thick-film, 0603, 0, ±5%, 0.1W, -55...+125°C | RC0603JR-070RL | 2
R3, R4, R6, R7 | Resistor thick-film, 0603, 10k, ±5%, 0.1W, -55...+125°C | RC0603JR-0710KL | 4
R5 | Resistor thick-film, 0603, 100, ±5%, 0.1W, -55...+125°C | RC0603JR-07100RL | 1
U1 | ARM Cortex-M4 32-bit MCU+FPU, 256 KB Flash, 128 KB Internal RAM, 50 I/Os, 64-Pin LQFP, -40 to 85 degC, Tray | STM32F446RCT6 | 1
VT1 | N-MOSFET Transistor, 20V, 4.2A, SOT-23-23 | IRLML2502TRPBF | 1
X1, X2, X3, X4, X7 | PCB Test Point Through Hole Mount | TEST-1W | 5
X5 | PLD Connector 20 pin, 2.0mm, Male, DS1025-06-2x10 | DS1025-06-2x10 | 1
X6 | PLD Connector 20 pin, 2.54mm, Male, DS1022-2x10R | DS1022-2x10R | 1
X8 | PLS Connector 6 pins, 2.54mm, Male | DS1021-01-6 | 1
Z1 | Crystal, SMD3225C4, 8MHz | KSE-7U08000MAB143ZA3 | 1

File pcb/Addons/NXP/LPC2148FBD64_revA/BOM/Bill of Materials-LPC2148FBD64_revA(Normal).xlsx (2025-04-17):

Designator | Description/Value | PartNumber | Quantity
C1, C3 | Ceramic capacitor, 0603, 15, ±10%, 100V, C0G, -55...+125°C | GRM1885C2A150J | 2
C2 | Ceramic capacitor, 0603, 0.1u, ±10%, 50V, X7R, -55...+125°C | GRM188R71H104K | 1
MP1, MP2, MP3, MP4 | Hexagon Nut M3 DIN 934 | Nut M3 DIN 934 | 4
MP5, MP6, MP7, MP8 | PCB brass stand, M3, 10mm | PCHSN-10 | 4
R1 | Resistor thick-film, 0603, 3k, ±5%, 0.1W, -55...+125°C | RC0603JR-073KL | 1
R2 | Resistor thick-film, 0603, 0, ±5%, 0.1W, -55...+125°C | RC0603JR-070RL | 1
R4 | Resistor thick-film, 0603, 10k, ±5%, 0.1W, -55...+125°C | RC0603JR-0710KL | 1
U1 | ARM Mikrocontroller - MCU Single-chip 16-bit/32-bit microcontrollers; up to 512 kB flash with ISP/IAP, USB 2.0 full-speed device, 10-bit ADC DAC | LPC2148FBD64 | 1
X1, X2, X3 | PCB Test Point Through Hole Mount | TEST-1W | 3
X4 | PLD Connector 20 pin, 2.0mm, Male, DS1025-06-2x10 | DS1025-06-2x10 | 1
X5 | PLD Connector 20 pin, 2.54mm, Male, DS1022-2x10R | DS1022-2x10R | 1
X6 | PLS connector 10 pin, 2.54mm, Male, V/T Type, DS1021-1x10 | DS1021-1x10 | 1
Z1 | Crystal, SMD3225C4, 16MHz | NX3225GA-12MHZ | 1

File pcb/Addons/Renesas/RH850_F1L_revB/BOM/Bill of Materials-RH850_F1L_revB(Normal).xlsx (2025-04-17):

Designator | Description/Value | PartNumber | Quantity
C1, C9 | Ceramic capacitor, 0603, 15, ±10%, 100V, C0G, -55...+125°C | GRM1885C2A150J | 2
C2, C3, C4, C5, C6, C10 | Ceramic capacitor, 0603, 0.1u, ±10%, 50V, X7R, -55...+125°C | GRM188R71H104K | 6
MP1, MP2, MP3, MP4 | Hexagon Nut M3 DIN 934 | Nut M3 DIN 934 | 4
MP5, MP6, MP7, MP8 | PCB brass stand, M3, 10mm | PCHSN-10 | 4
R1, R5, R10, R11 | Resistor thick-film, 0603, 10k, ±5%, 0.1W, -55...+125°C | RC0603JR-0710KL | 4
R2, R3, R4, R9 | Resistor thick-film, 0603, 0, ±5%, 0.1W, -55...+125°C | RC0603JR-070RL | 4
R7 | Resistor thick-film, 0603, 100, ±5%, 0.1W, -55...+125°C | RC0603JR-07100RL | 1
U1 | RH850/F1L Microcontroller IC 32-Bit Single-Core 100-LFQFP (14x14) | R7F7010233 | 1
VT1 | N-MOSFET Transistor, 20V, 4.2A, SOT-23-23 | IRLML2502TRPBF | 1
X1, X2, X3, X4, X7, X8, X9 | PCB Test Point Through Hole Mount | TEST-1W | 7
X5 | PLD Connector 20 pin, 2.0mm, Male, DS1025-06-2x10 | DS1025-06-2x10 | 1
X6 | PLD Connector 20 pin, 2.54mm, Male, DS1022-2x10R | DS1022-2x10R | 1
X10 | PLS Connector 7 pin, 2.54mm, Male | DS1021-01-7 | 1
X11 | PLS Connector 6 pins, 2.54mm, Male | DS1021-01-6 | 1
Z1 | Crystal, SMD3225C4, 16MHz | KSE-7U16000M9Z143ZA3 | 1

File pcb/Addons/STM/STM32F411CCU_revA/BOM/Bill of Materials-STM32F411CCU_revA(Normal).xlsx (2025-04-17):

Designator | Description/Value | PartNumber | Quantity
C1, C2, C3, C4, C7 | Ceramic capacitor, 0603, 0.1u, ±10%, 50V, X7R, -55...+125°C | GRM188R71H104K | 5
C5 | Ceramic capacitor, 0603, 1u, ±10%, 25V, X7R, -55...+125°C | GRM188R71E105KA12D | 1
L1 | Inductor SMD, 10uH, 0.2A, INDC 0603(1608)X95N | MLZ1608M100WT000 | 1
MP1, MP2, MP3, MP4 | Hexagon Nut M3 DIN 934 | Nut M3 DIN 934 | 4
MP5, MP6, MP7, MP8 | PCB brass stand, M3, 10mm | PCHSN-10 | 4
R1, R2, R3, R4 | Resistor thick-film, 0603, 10k, ±5%, 0.1W, -55...+125°C | RC0603JR-0710KL | 4
U1 | IC microcontroller , STM32F411CCU6TR, 48-UFQFPN (7x7), 256KB, 128KB | STM32F411CCU6TR | 1
VT1 | N-MOSFET Transistor, 20V, 4.2A, SOT-23-23 | IRLML2502TRPBF | 1
X1, X2, X3, X4 | PCB Test Point Through Hole Mount | TEST-1W | 4
X5 | PLD Connector 20 pin, 2.0mm, Male, DS1025-06-2x10 | DS1025-06-2x10 | 1
X6 | PLD Connector 20 pin, 2.54mm, Male, DS1022-2x10R | DS1022-2x10R | 1

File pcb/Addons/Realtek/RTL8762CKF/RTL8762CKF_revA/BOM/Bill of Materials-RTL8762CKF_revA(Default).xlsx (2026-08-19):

Designator | Description/Value | PartNumber | Quantity
C1, C6 | Ceramic capacitor, 0603, 0.1u, ±10%, 50V, X7R, -55...+125°C | GRM188R71H104K | 2
C2 | Ceramic capacitor, 0603, 4.7u, ±10%, 16V, X7R, -55...+125°C | GRM188Z71C475KE21D | 1
C3, C7 | Ceramic capacitor, 0603, 9.1p, ±10%, 100V, C0G, -55...+125°C | CC0603CRNPO9BN9R1 | 2
C4 | Ceramic capacitor, 0603, 0.01u, ±10%, 100V, X7R, -55...+125°C | GCM188R72A103KA37D | 1
C5 | Ceramic capacitor, 0603, 4.7u, ±10%, 10V, X7R, -55...+125°C | GRM188Z71A475KE15D | 1
DD1 | RTL8762CKF, QFN-48 6x6mm | RTL8762CKF | 1
L1 | Inductor, 0805, 2.2uH, 0.8 A | LQM21PN2R2NGRD | 1
MP1, MP2, MP3, MP4 | Hexagon Nut M3 DIN 934 | Nut M3 DIN 934 | 4
MP5, MP6, MP7, MP8 | PCB brass stand, M3, 10mm | PCHSN-10 | 4
R1, R3 | Resistor thick-film, 0603, 10k, ±5%, 0.1W, -55...+125°C | RC0603JR-0710KL | 2
R2 | Resistor thick-film, 0603, 100, ±5%, 0.1W, -55...+125°C | RC0603JR-07100RL | 1
VT1 | N-MOSFET Transistor, 20V, 4.2A, SOT-23-23 | IRLML2502TRPBF | 1
X1, X2, X3, X4, X7, X8, X9 | PCB Test Point Through Hole Mount | TEST-1W | 7
X5 | PLD Connector 20 pin, 2.0mm, Male, DS1025-06-2x10 | DS1025-06-2x10 | 1
X6 | PLD Connector 20 pin, 2.54mm, Male, DS1022-2x10R | DS1022-2x10R | 1
X10 | Connector 2 pin | DS1021-01-2 | 1
X11 | PLS Connector 6 pins, 2.54mm, Male | DS1021-01-6 | 1
Z1 | Crystal, SMD3225C4, 40MHz | 7M-40.000MAAJ-T | 1

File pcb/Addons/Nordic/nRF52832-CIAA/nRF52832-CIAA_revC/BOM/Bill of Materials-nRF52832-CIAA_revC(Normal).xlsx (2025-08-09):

Designator | Description/Value | PartNumber | Quantity
C1, C2 | Ceramic capacitor, 0603, 0.1u, ±10%, 50V, X7R, -55...+125°C | GRM188R71H104K | 2
MP1, MP2, MP3, MP4 | Hexagon Nut M3 DIN 934 | Nut M3 DIN 934 | 4
MP5, MP6, MP7, MP8 | PCB brass stand, M3, 10mm | PCHSN-10 | 4
R2, R3 | Resistor thick-film, 0603, 0, ±1%, 0.1W, -55...+125°C | RC0603FR-070RL | 2
R4 | Resistor thick-film, 0603, 10k, ±1%, 0.1W, -55...+125°C | RC0603FR-0710KL | 1
U1 | RF System on a Chip - SoC BLE 2.4GHZ WLCSP 13" | NRF52832-CIAA | 1
VT1 | N-MOSFET Transistor, 20V, 4.2A, SOT-23-23 | IRLML2502TRPBF | 1
X1 | PLD Connector 20 pin, 2.0mm, Male, DS1025-06-2x10 | DS1025-06-2x10 | 1
X2 | PLD Connector 20 pin, 2.54mm, Male, DS1022-2x10R | DS1022-2x10R | 1
X3, X4, X5, X6 | PCB Test Point Through Hole Mount | TEST-1W | 4

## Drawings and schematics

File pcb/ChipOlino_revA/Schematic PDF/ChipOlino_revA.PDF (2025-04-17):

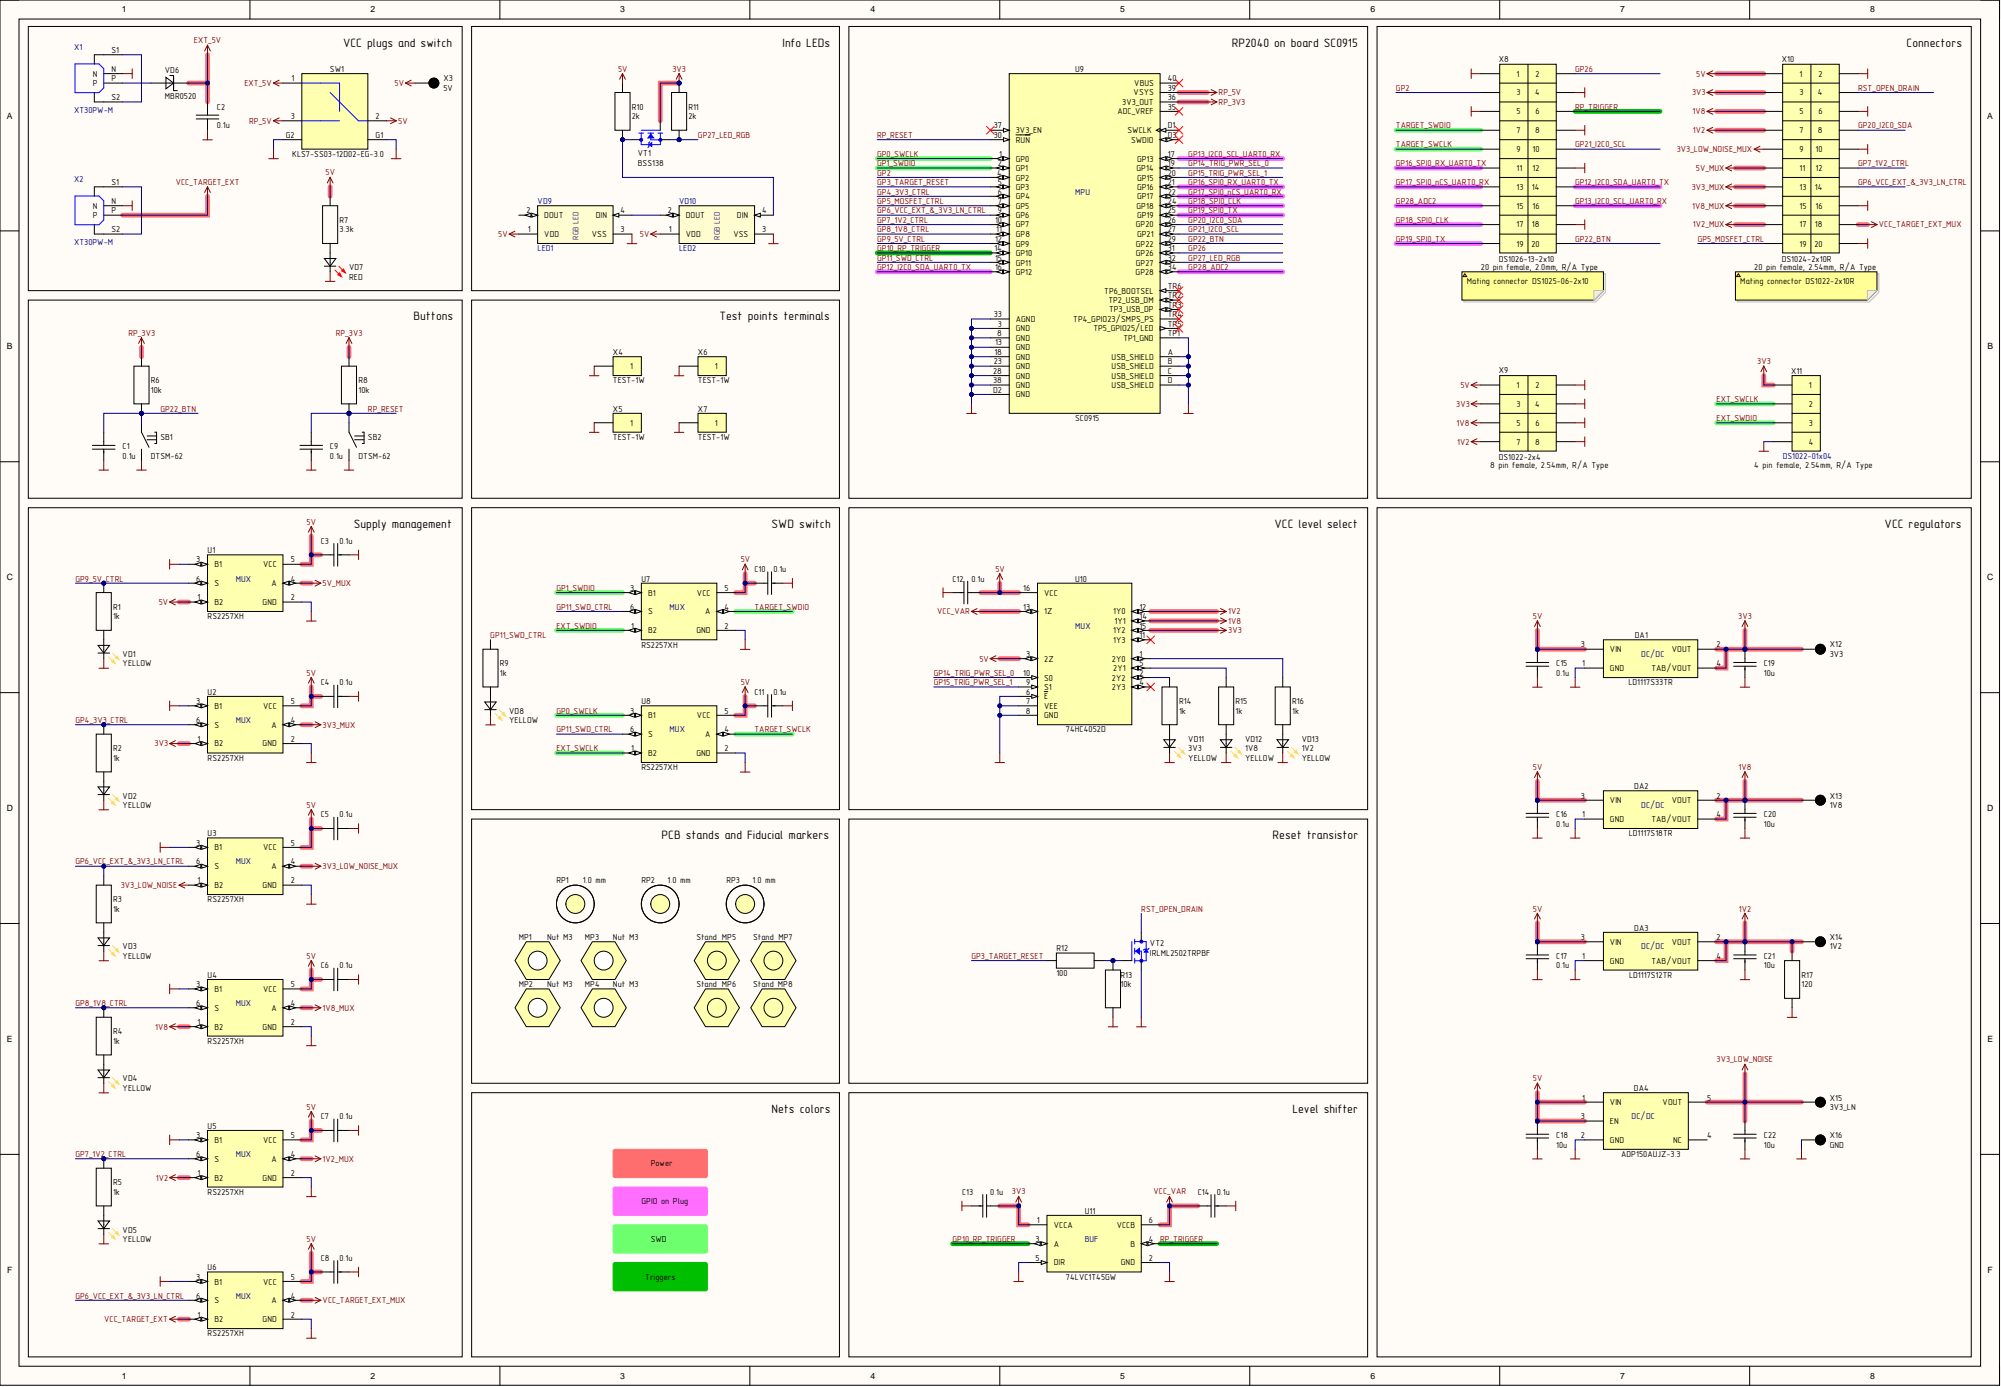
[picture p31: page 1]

VCC plugs and switch

PCB stands and Fiducial markers

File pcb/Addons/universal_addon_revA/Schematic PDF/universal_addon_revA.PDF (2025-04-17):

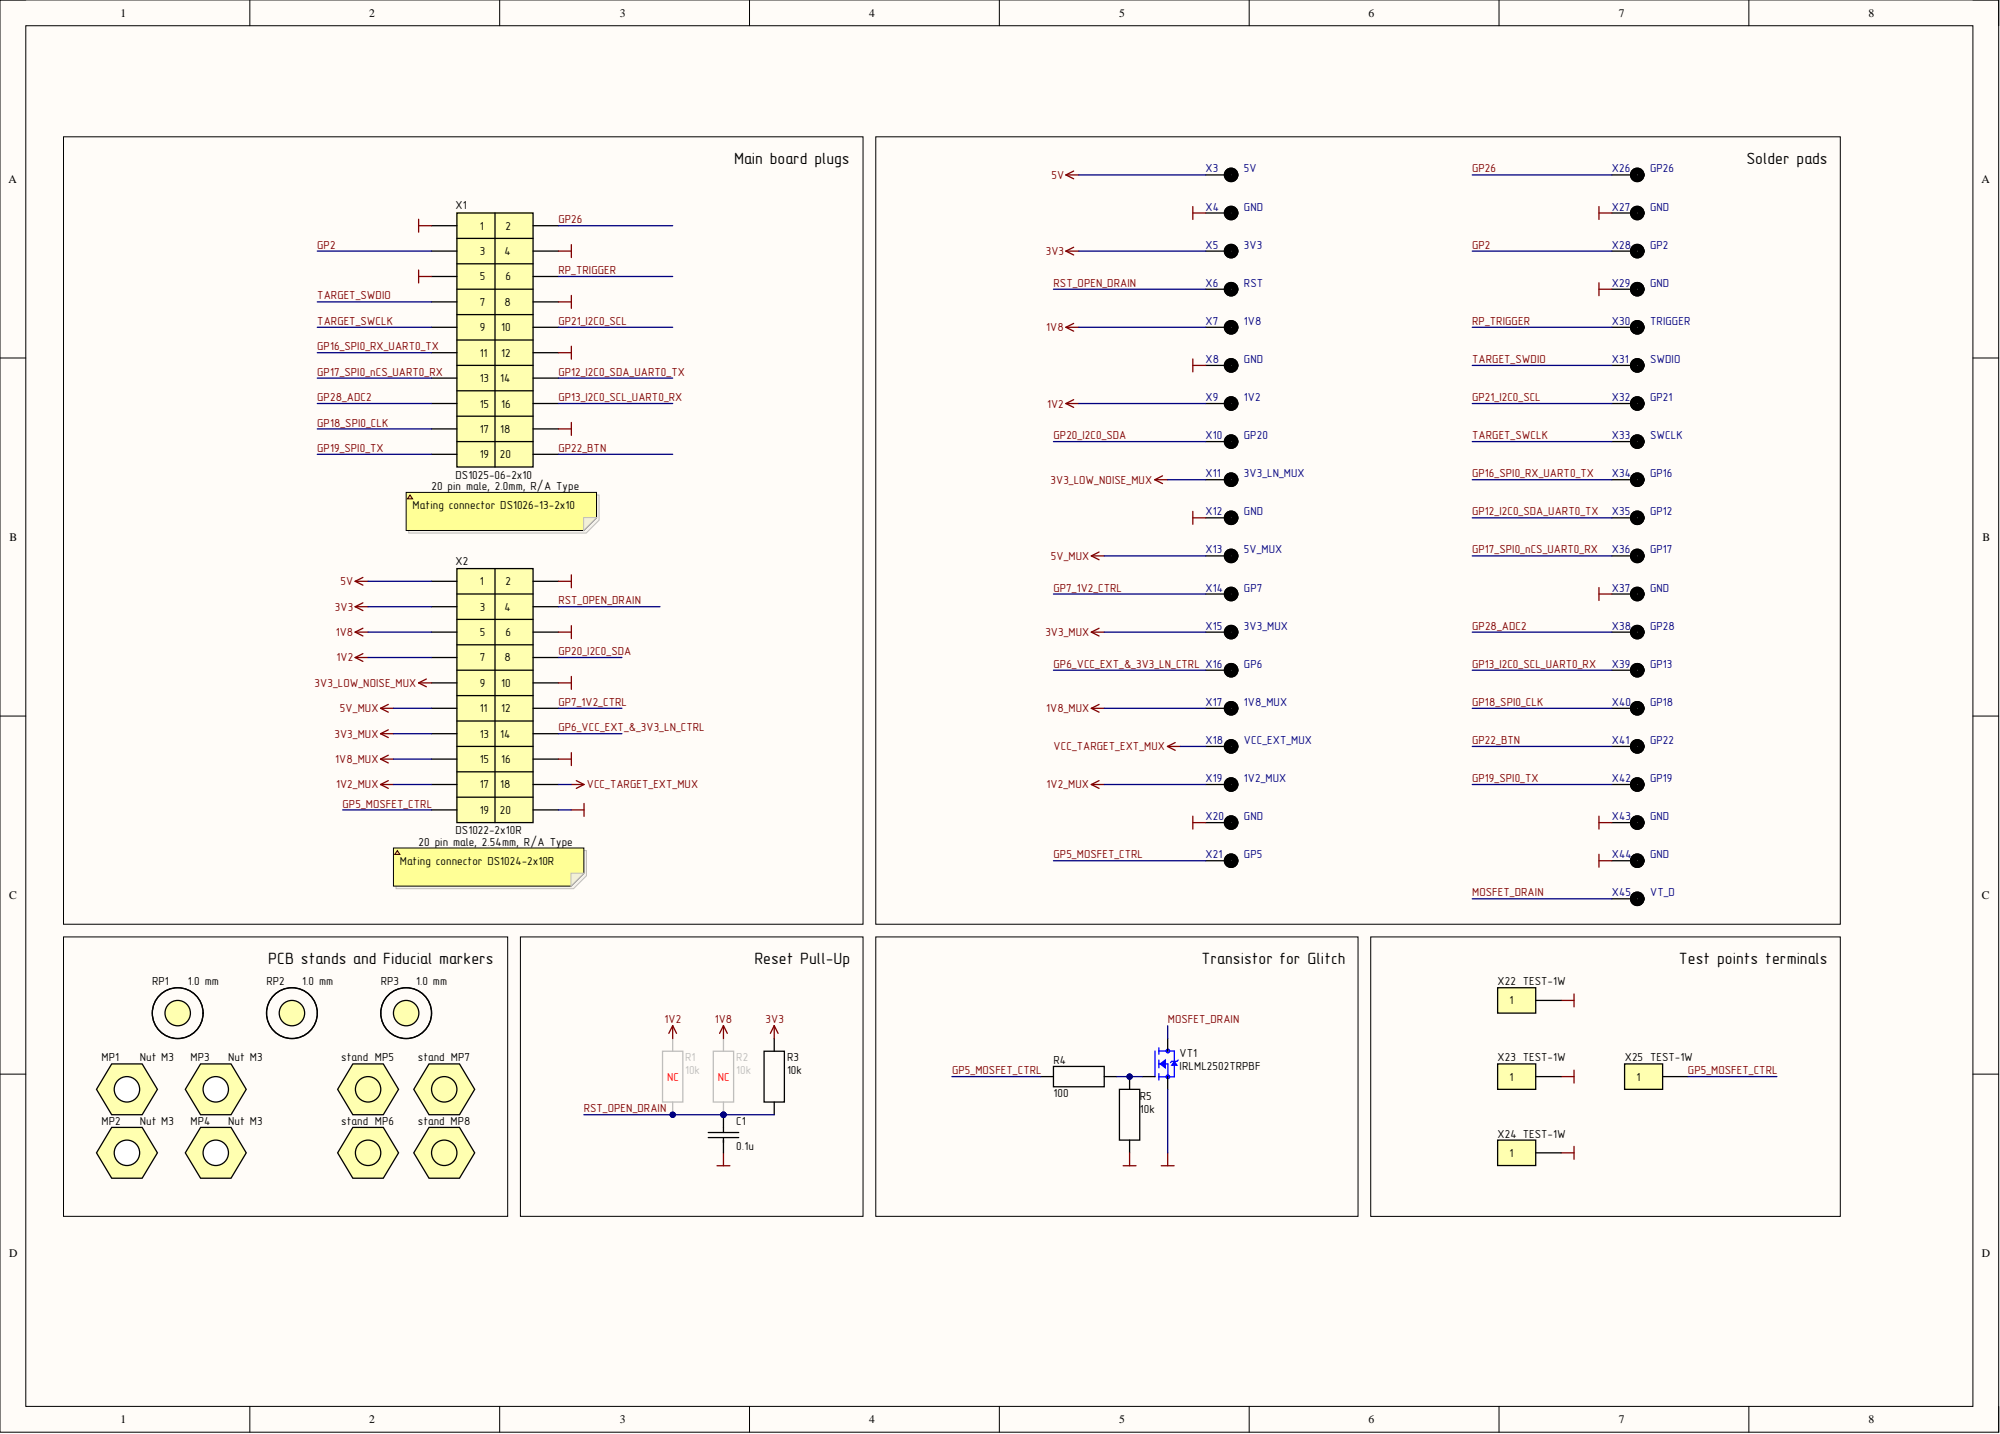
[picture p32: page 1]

GP16_SPI0_RX_UART0_TX
Mating connector DS1024-2x10R Mating connector DS1026-13-2x10

PCB stands and Fiducial marker

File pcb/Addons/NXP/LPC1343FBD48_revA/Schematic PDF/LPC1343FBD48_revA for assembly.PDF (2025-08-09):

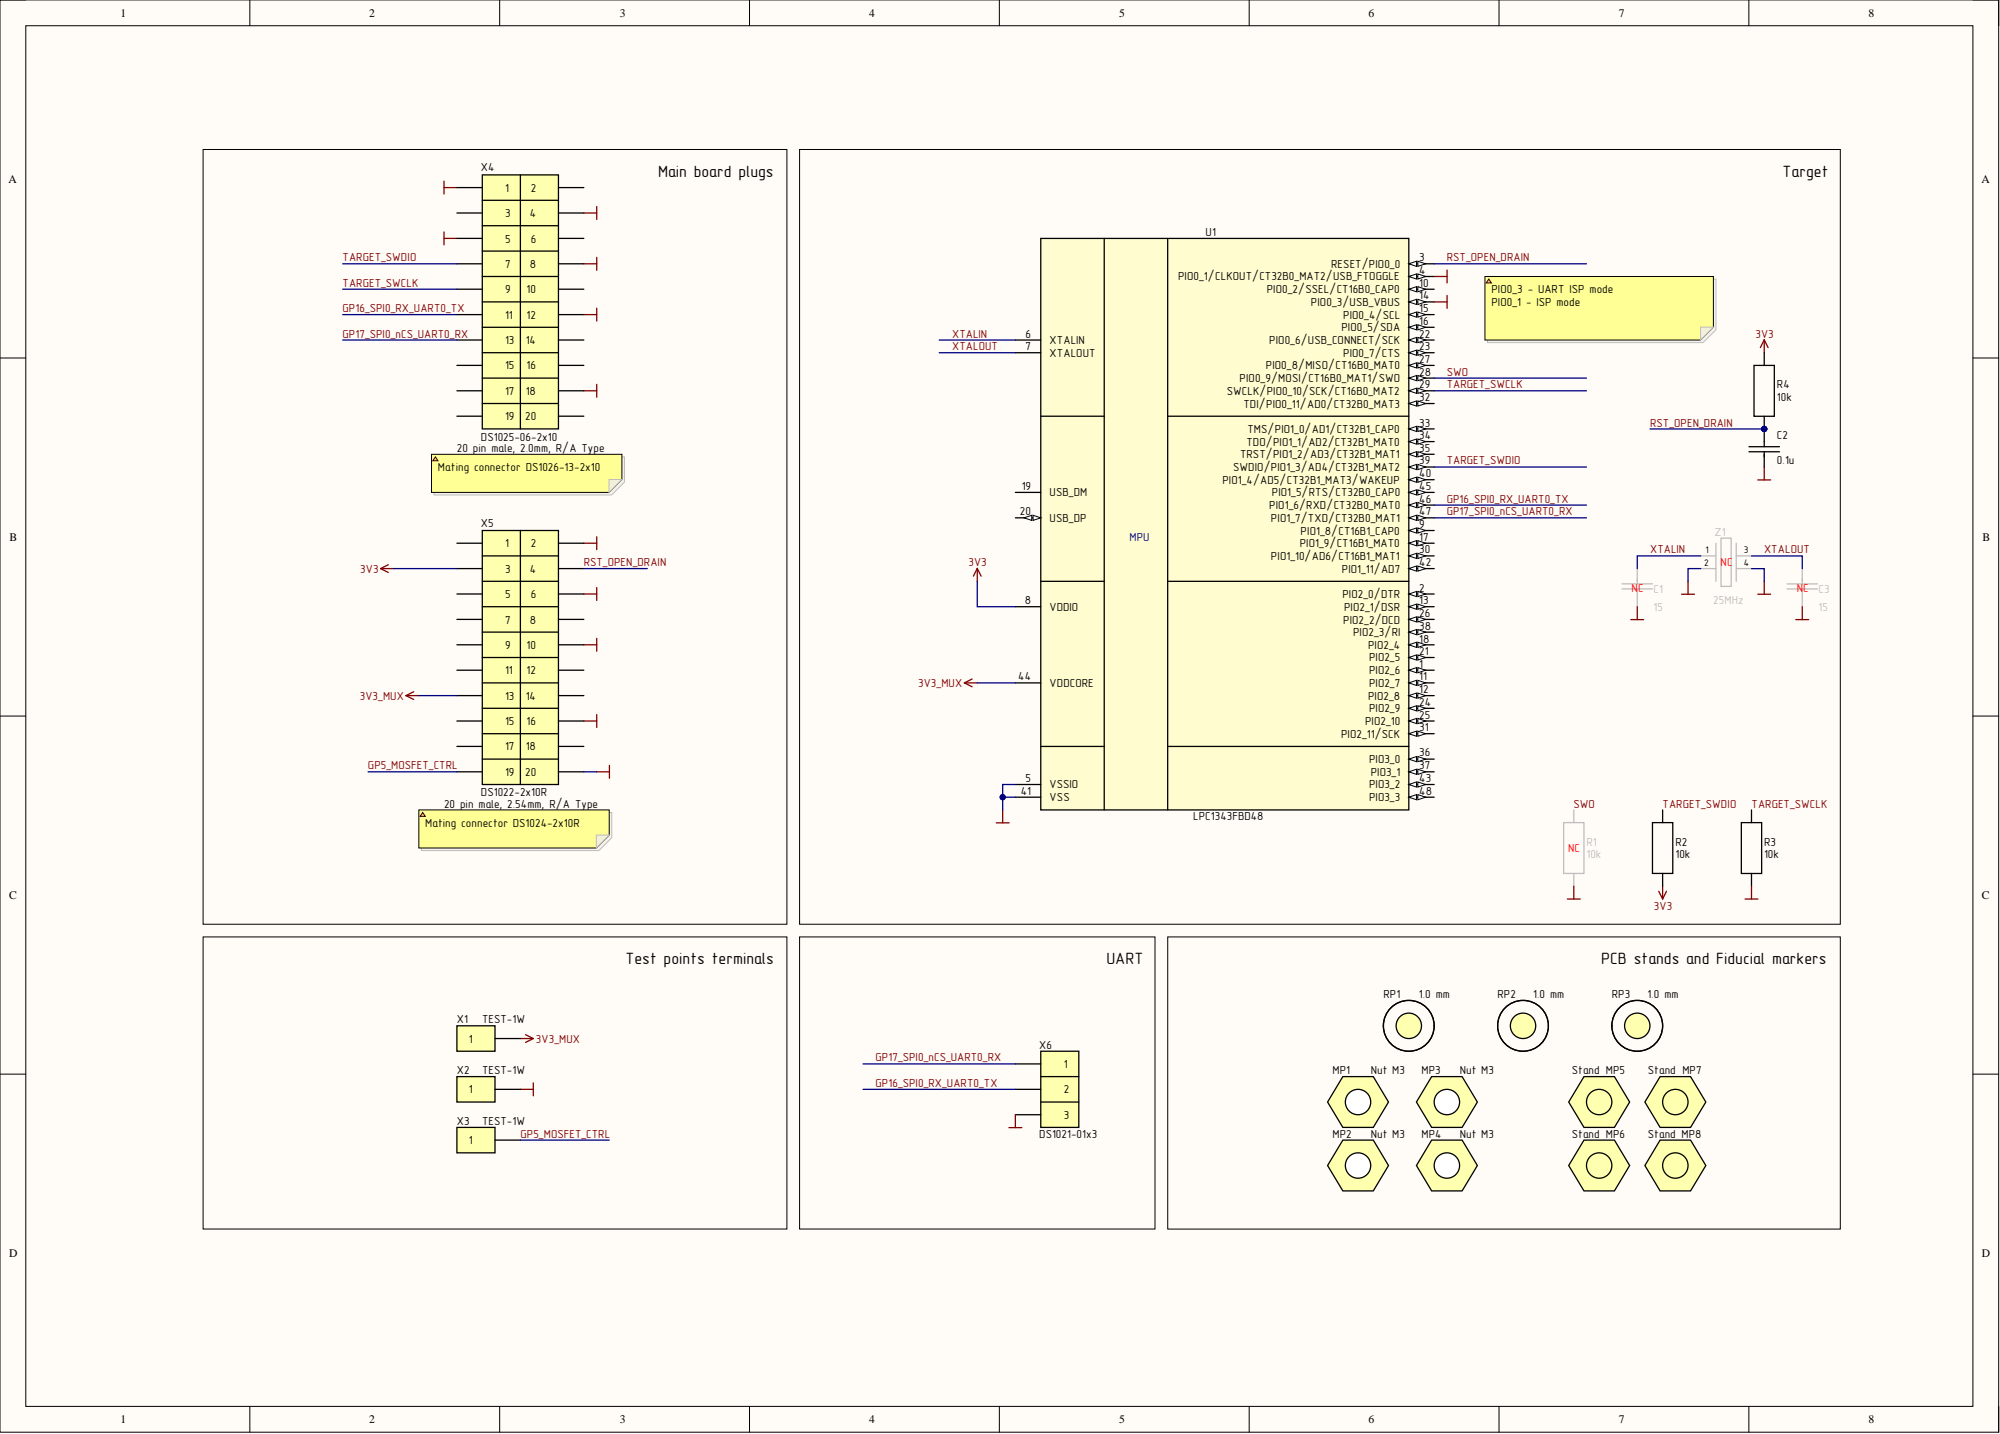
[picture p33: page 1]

PCB stands and Fiducial markers

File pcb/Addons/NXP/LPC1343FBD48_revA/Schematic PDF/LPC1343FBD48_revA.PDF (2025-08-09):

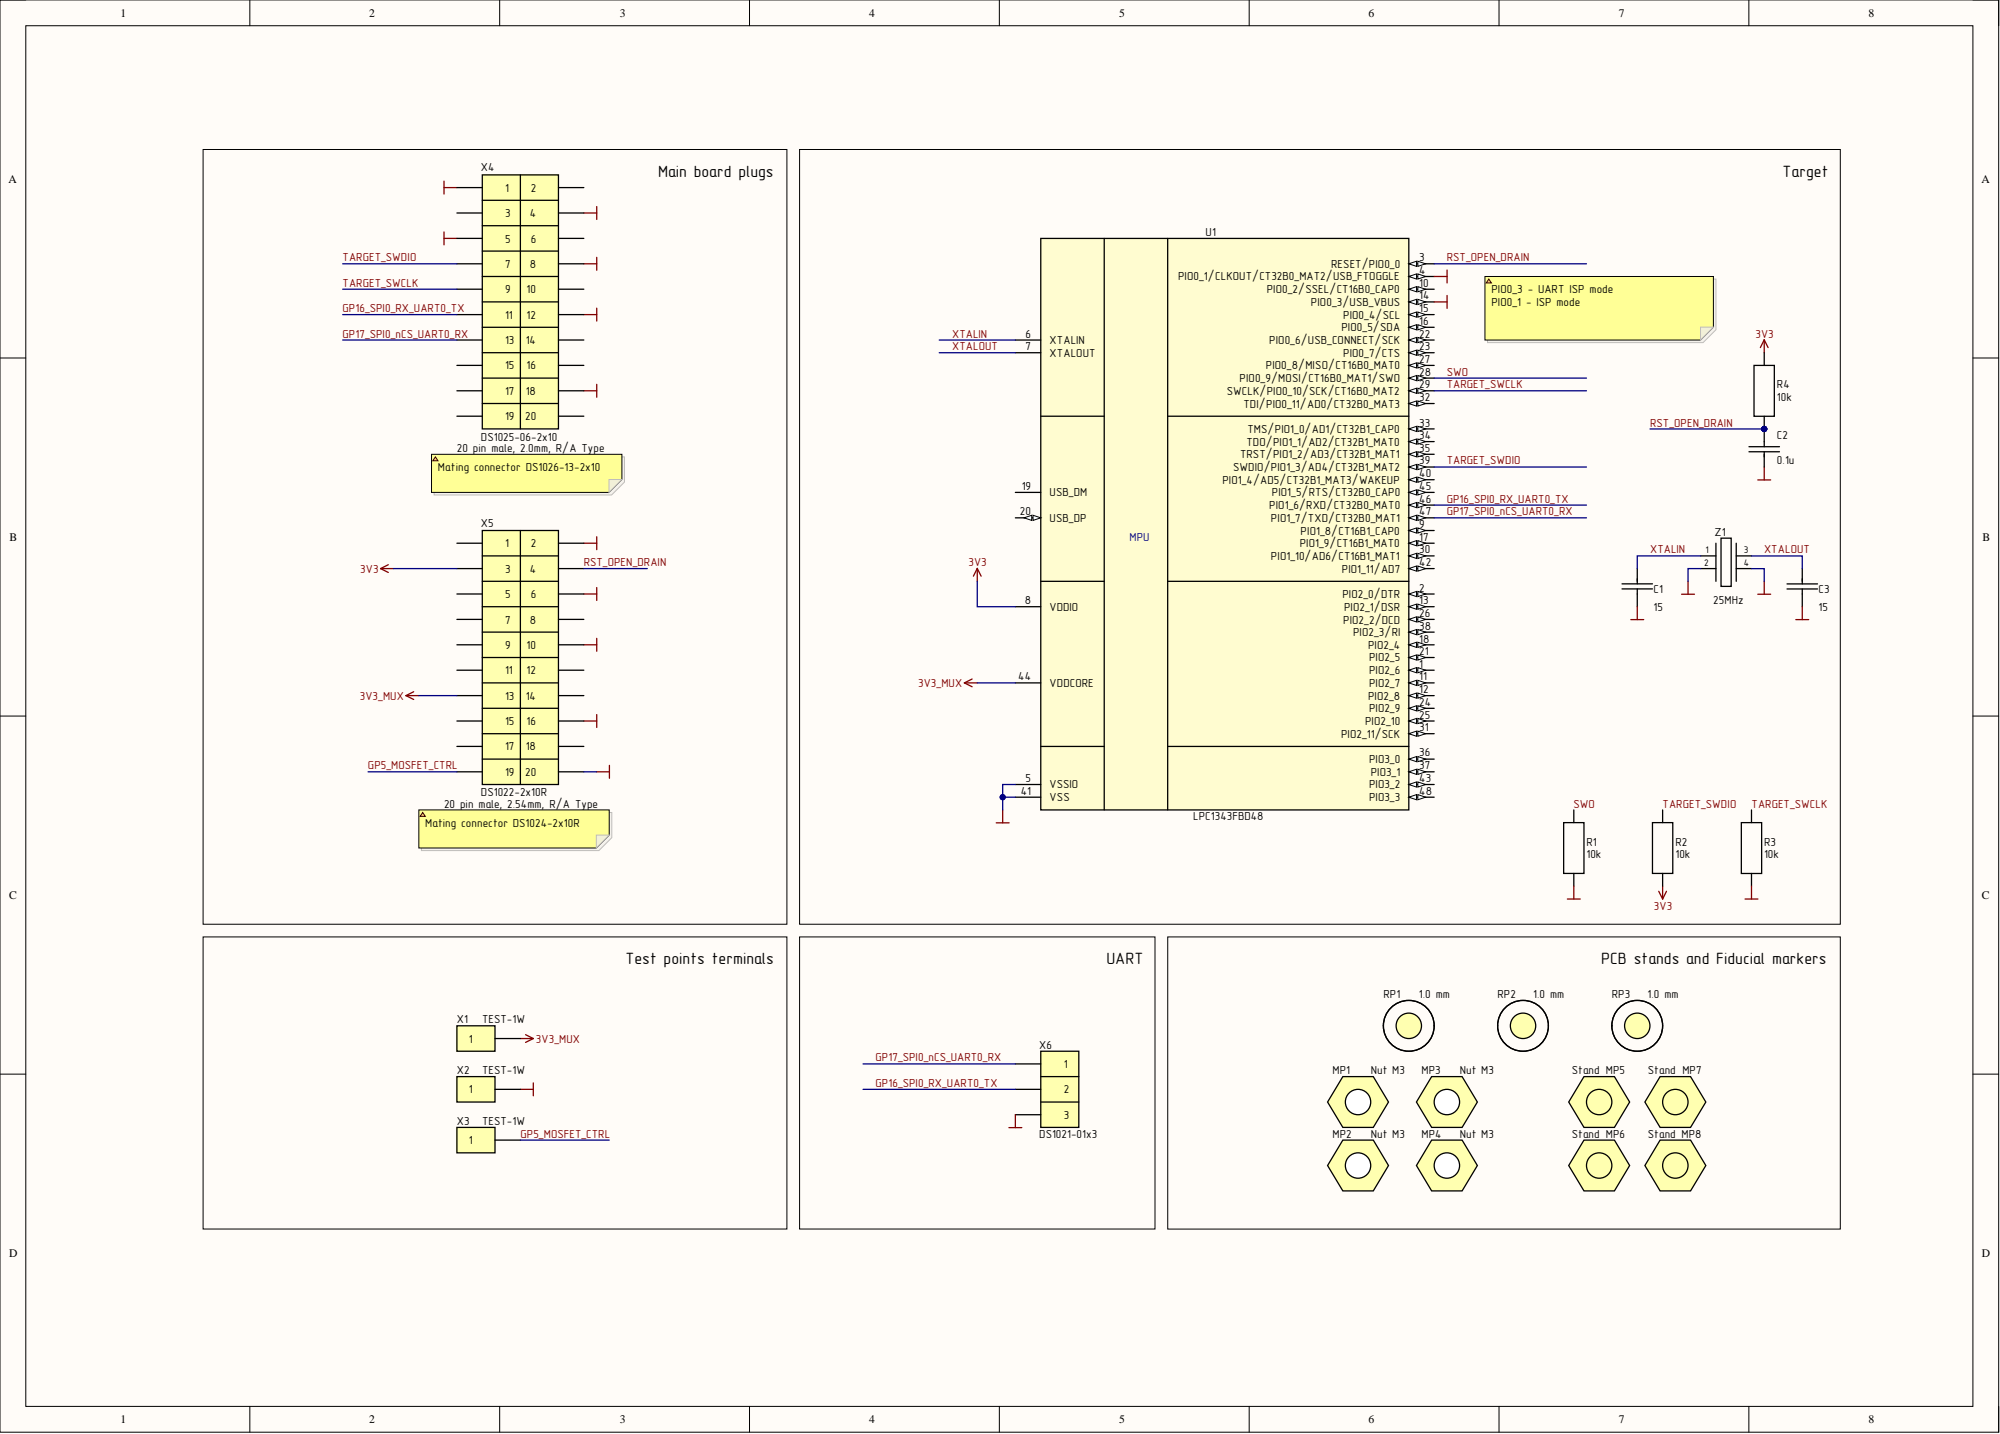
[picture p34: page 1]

PCB stands and Fiducial markers

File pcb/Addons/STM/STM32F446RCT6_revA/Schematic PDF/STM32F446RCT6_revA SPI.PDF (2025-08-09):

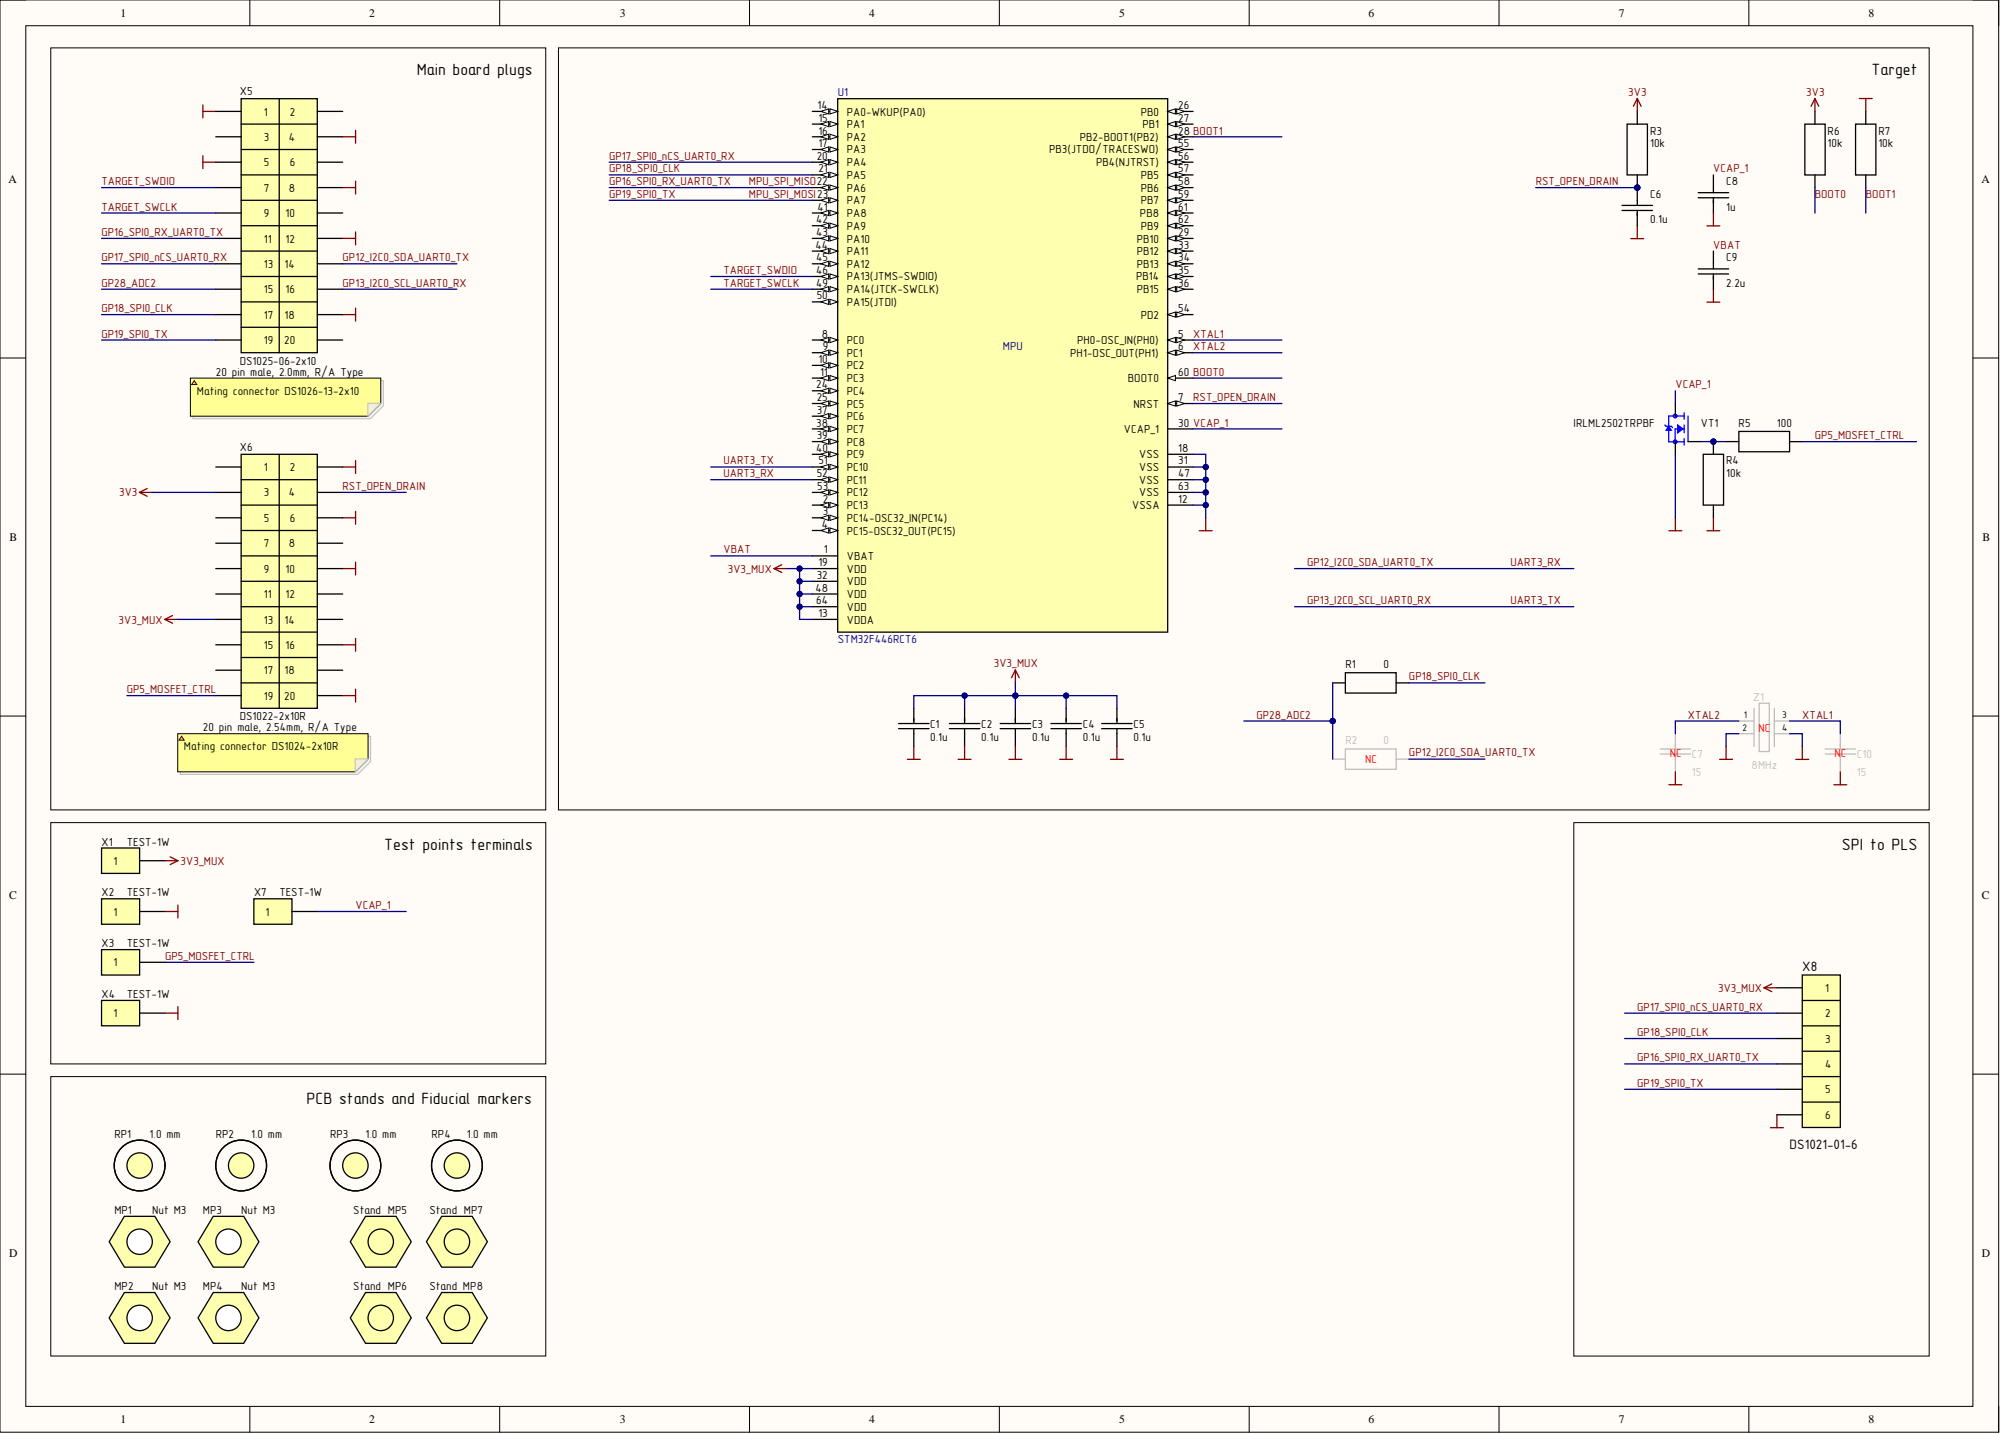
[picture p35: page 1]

4 | RST_OPEN_DRAIN 3

PCB stands and Fiducial markers

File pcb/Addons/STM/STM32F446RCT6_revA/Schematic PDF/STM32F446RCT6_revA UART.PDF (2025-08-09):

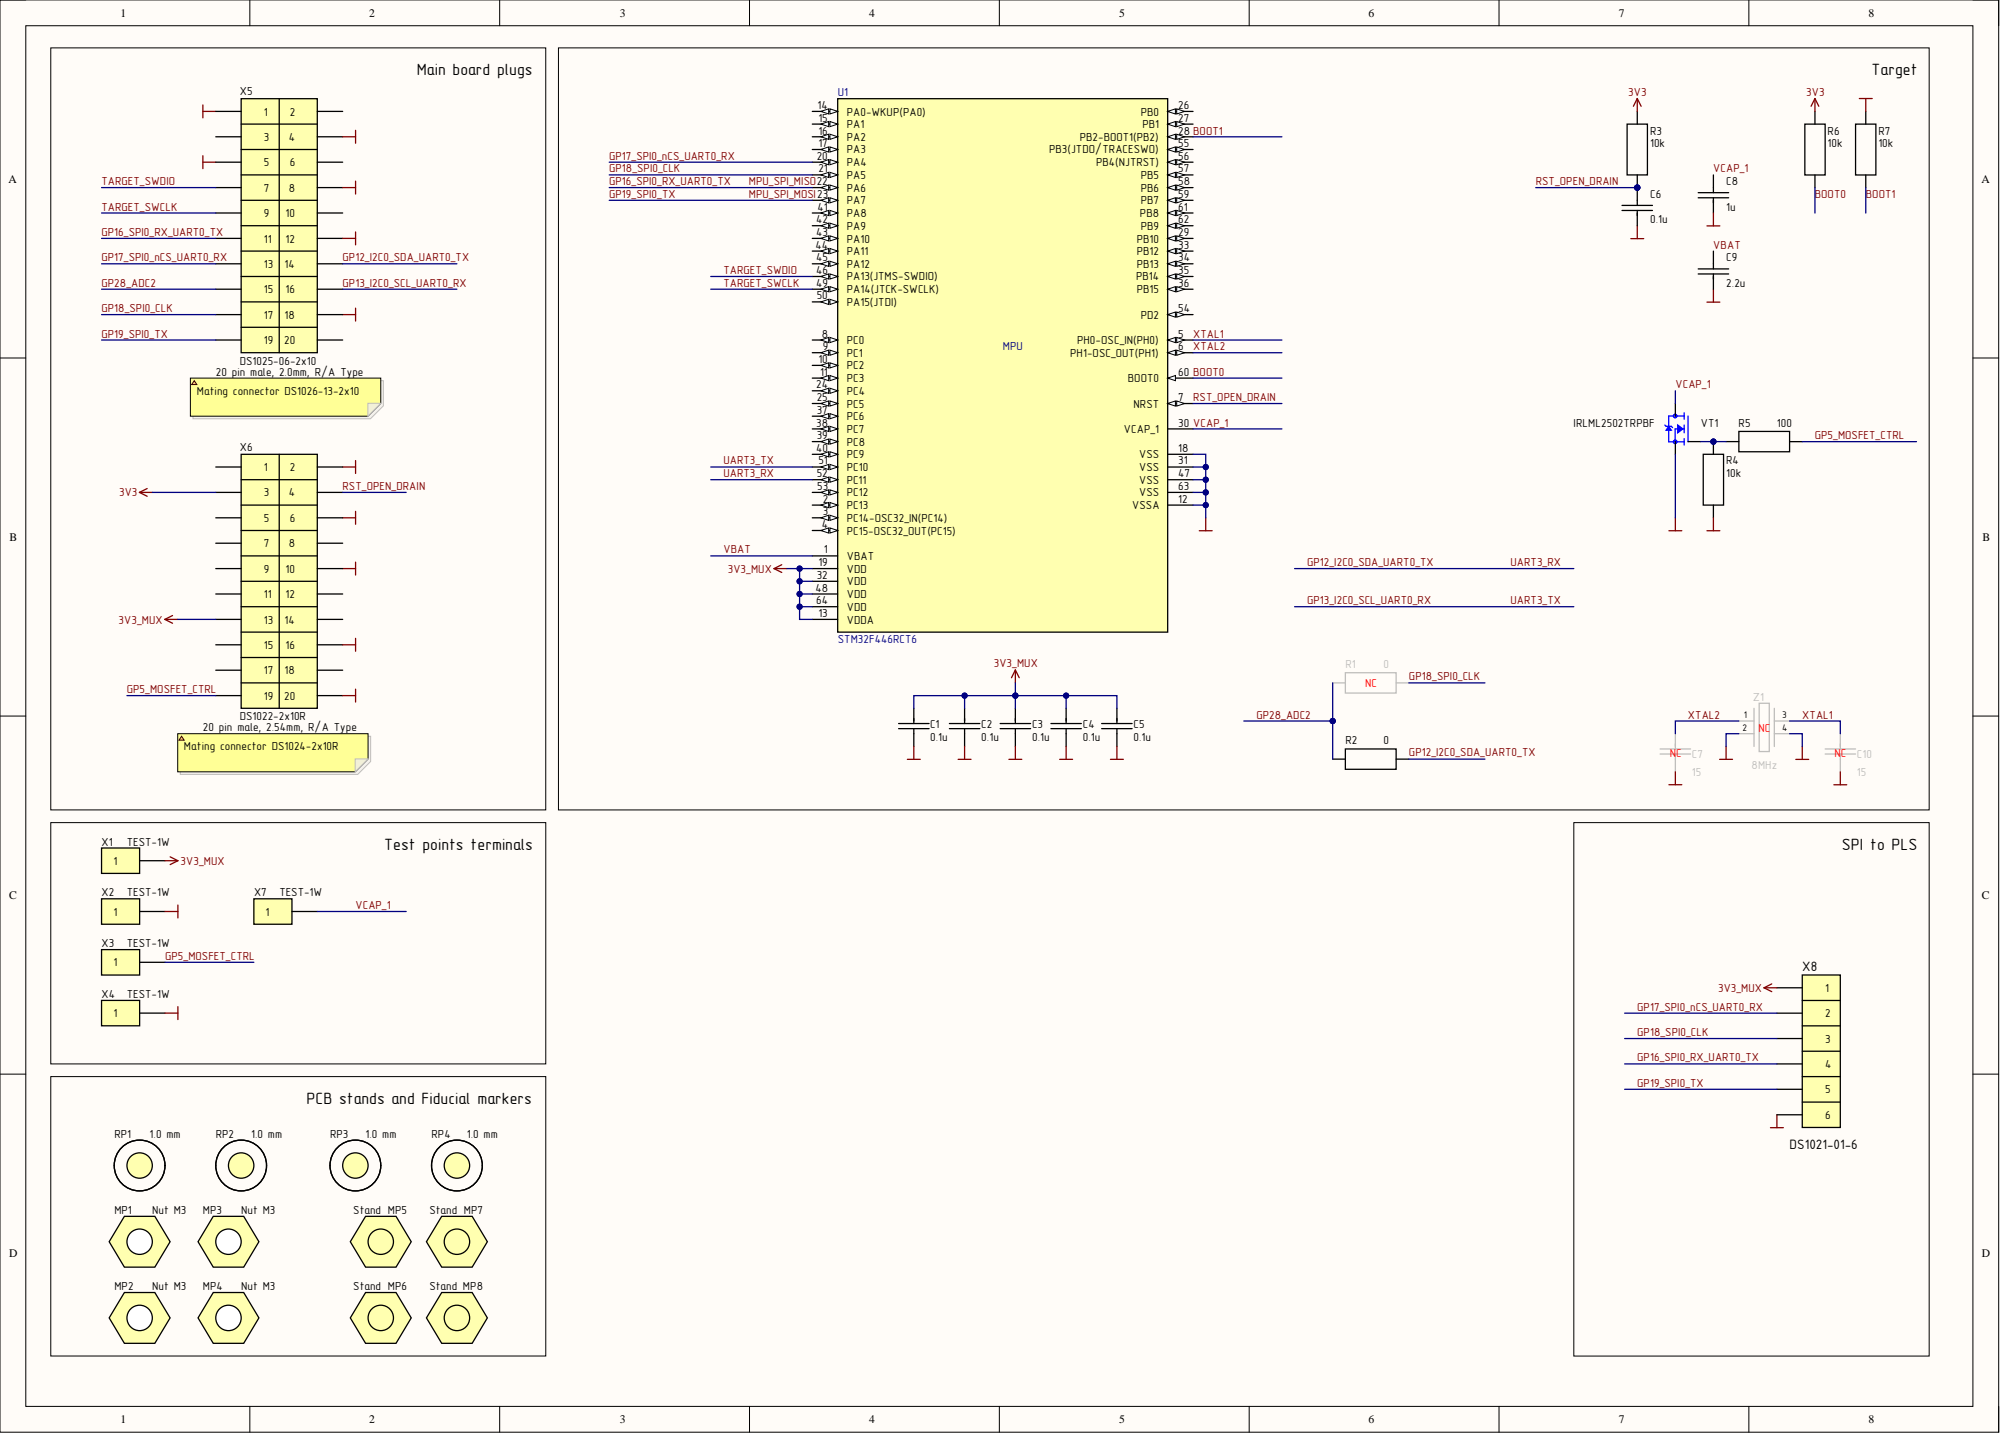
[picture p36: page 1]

4 | RST_OPEN_DRAIN 3

PCB stands and Fiducial markers

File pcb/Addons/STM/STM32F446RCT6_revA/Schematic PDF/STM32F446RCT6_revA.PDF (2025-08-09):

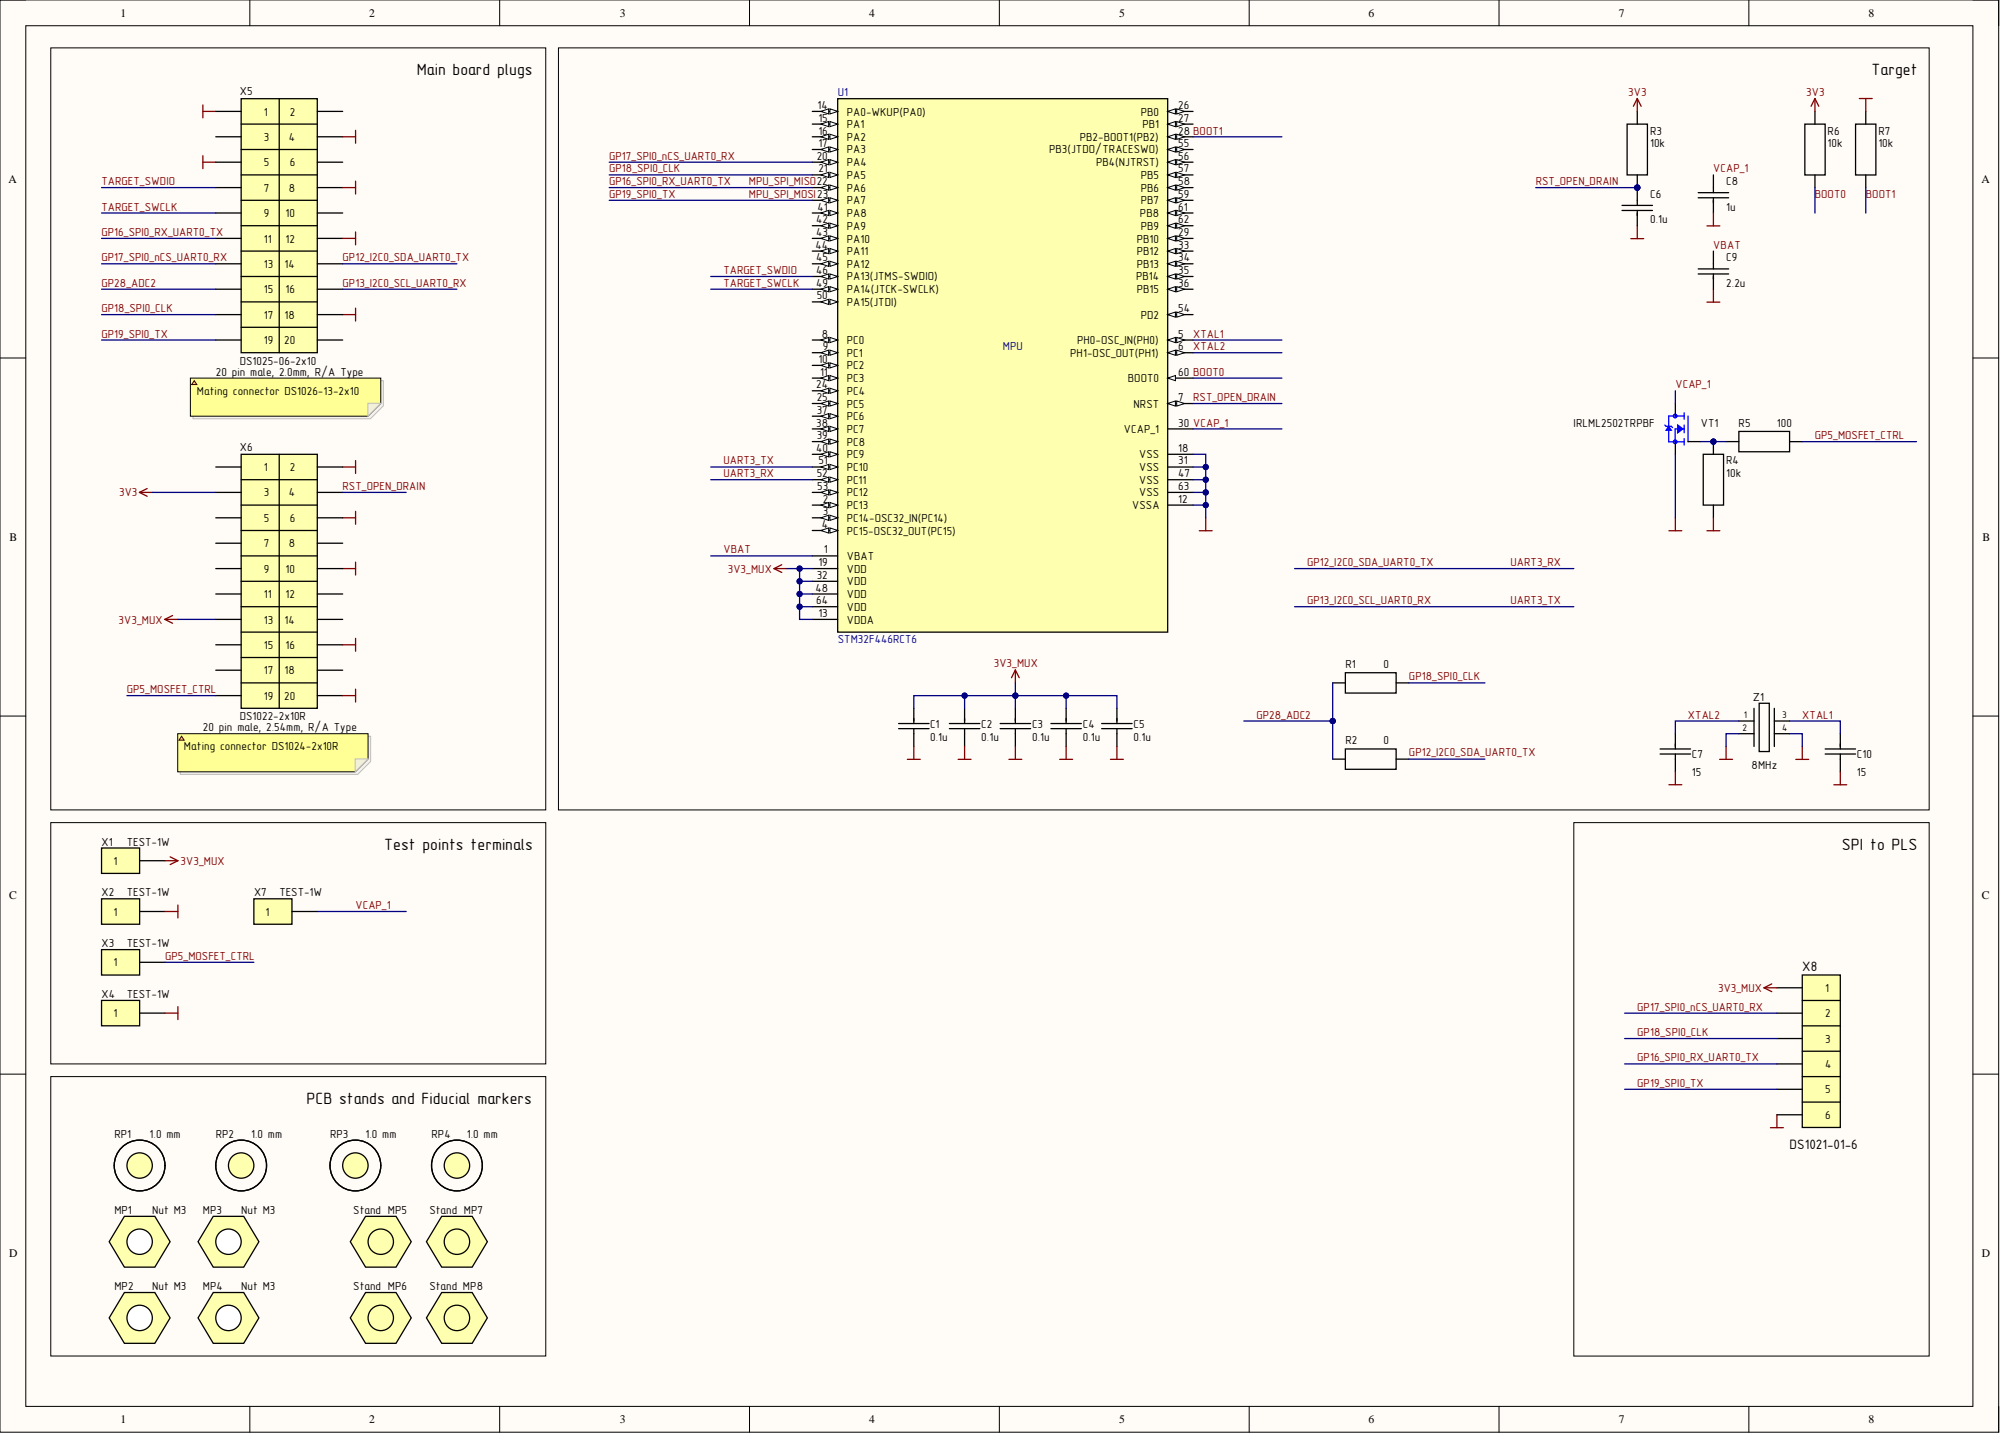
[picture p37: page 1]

4 | RST_OPEN_DRAIN 3

PCB stands and Fiducial markers

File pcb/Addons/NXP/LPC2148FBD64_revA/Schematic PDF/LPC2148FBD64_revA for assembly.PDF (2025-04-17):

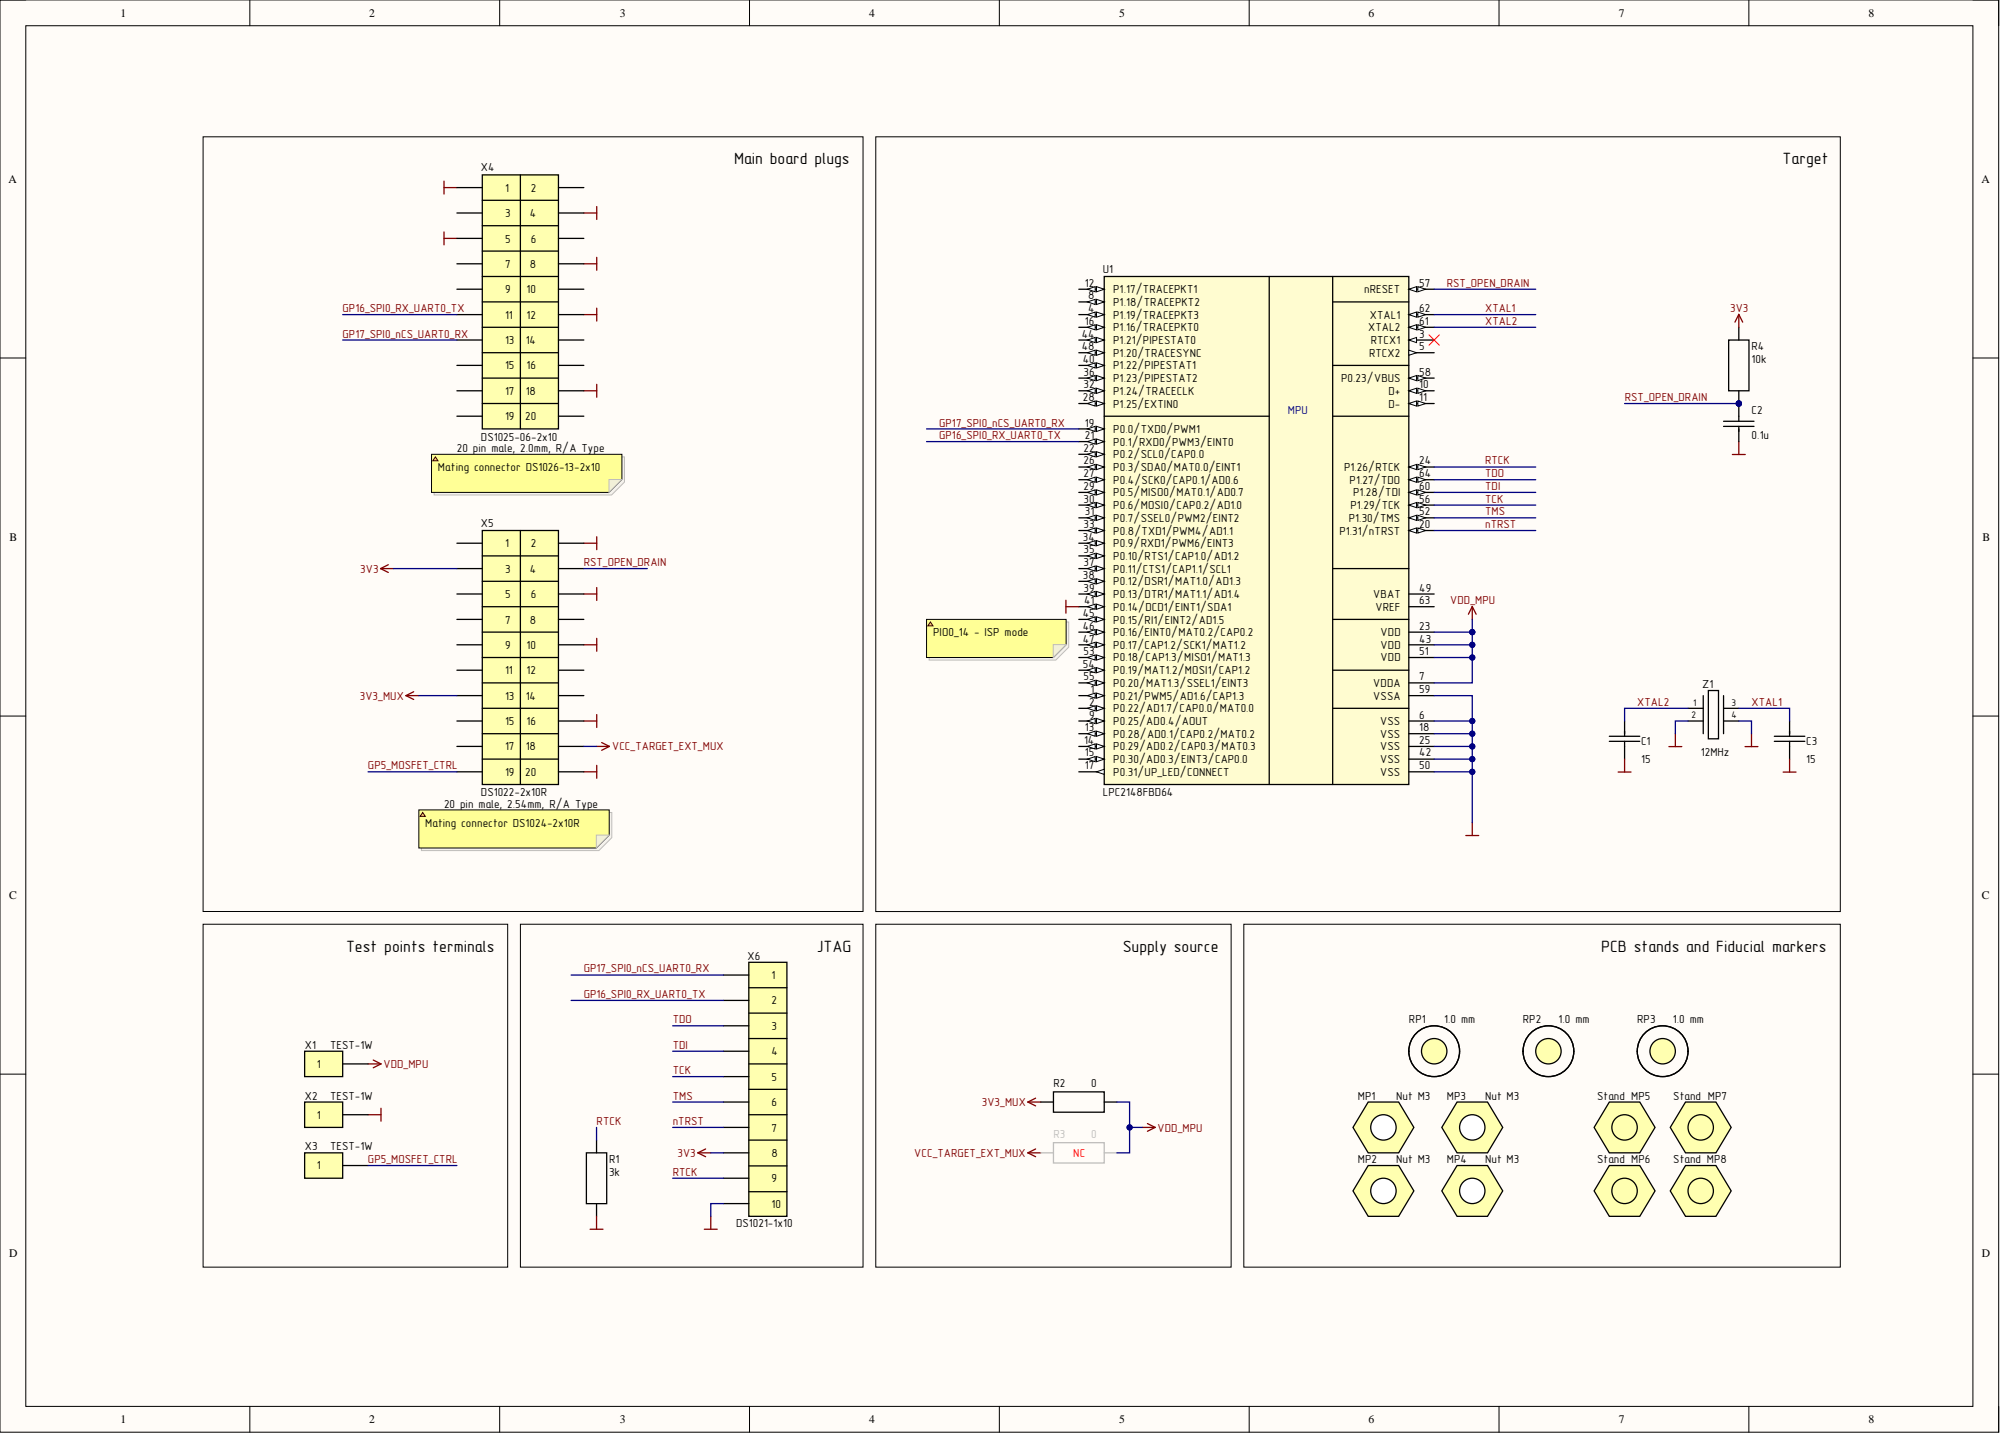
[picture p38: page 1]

PCB stands and Fiducial markers

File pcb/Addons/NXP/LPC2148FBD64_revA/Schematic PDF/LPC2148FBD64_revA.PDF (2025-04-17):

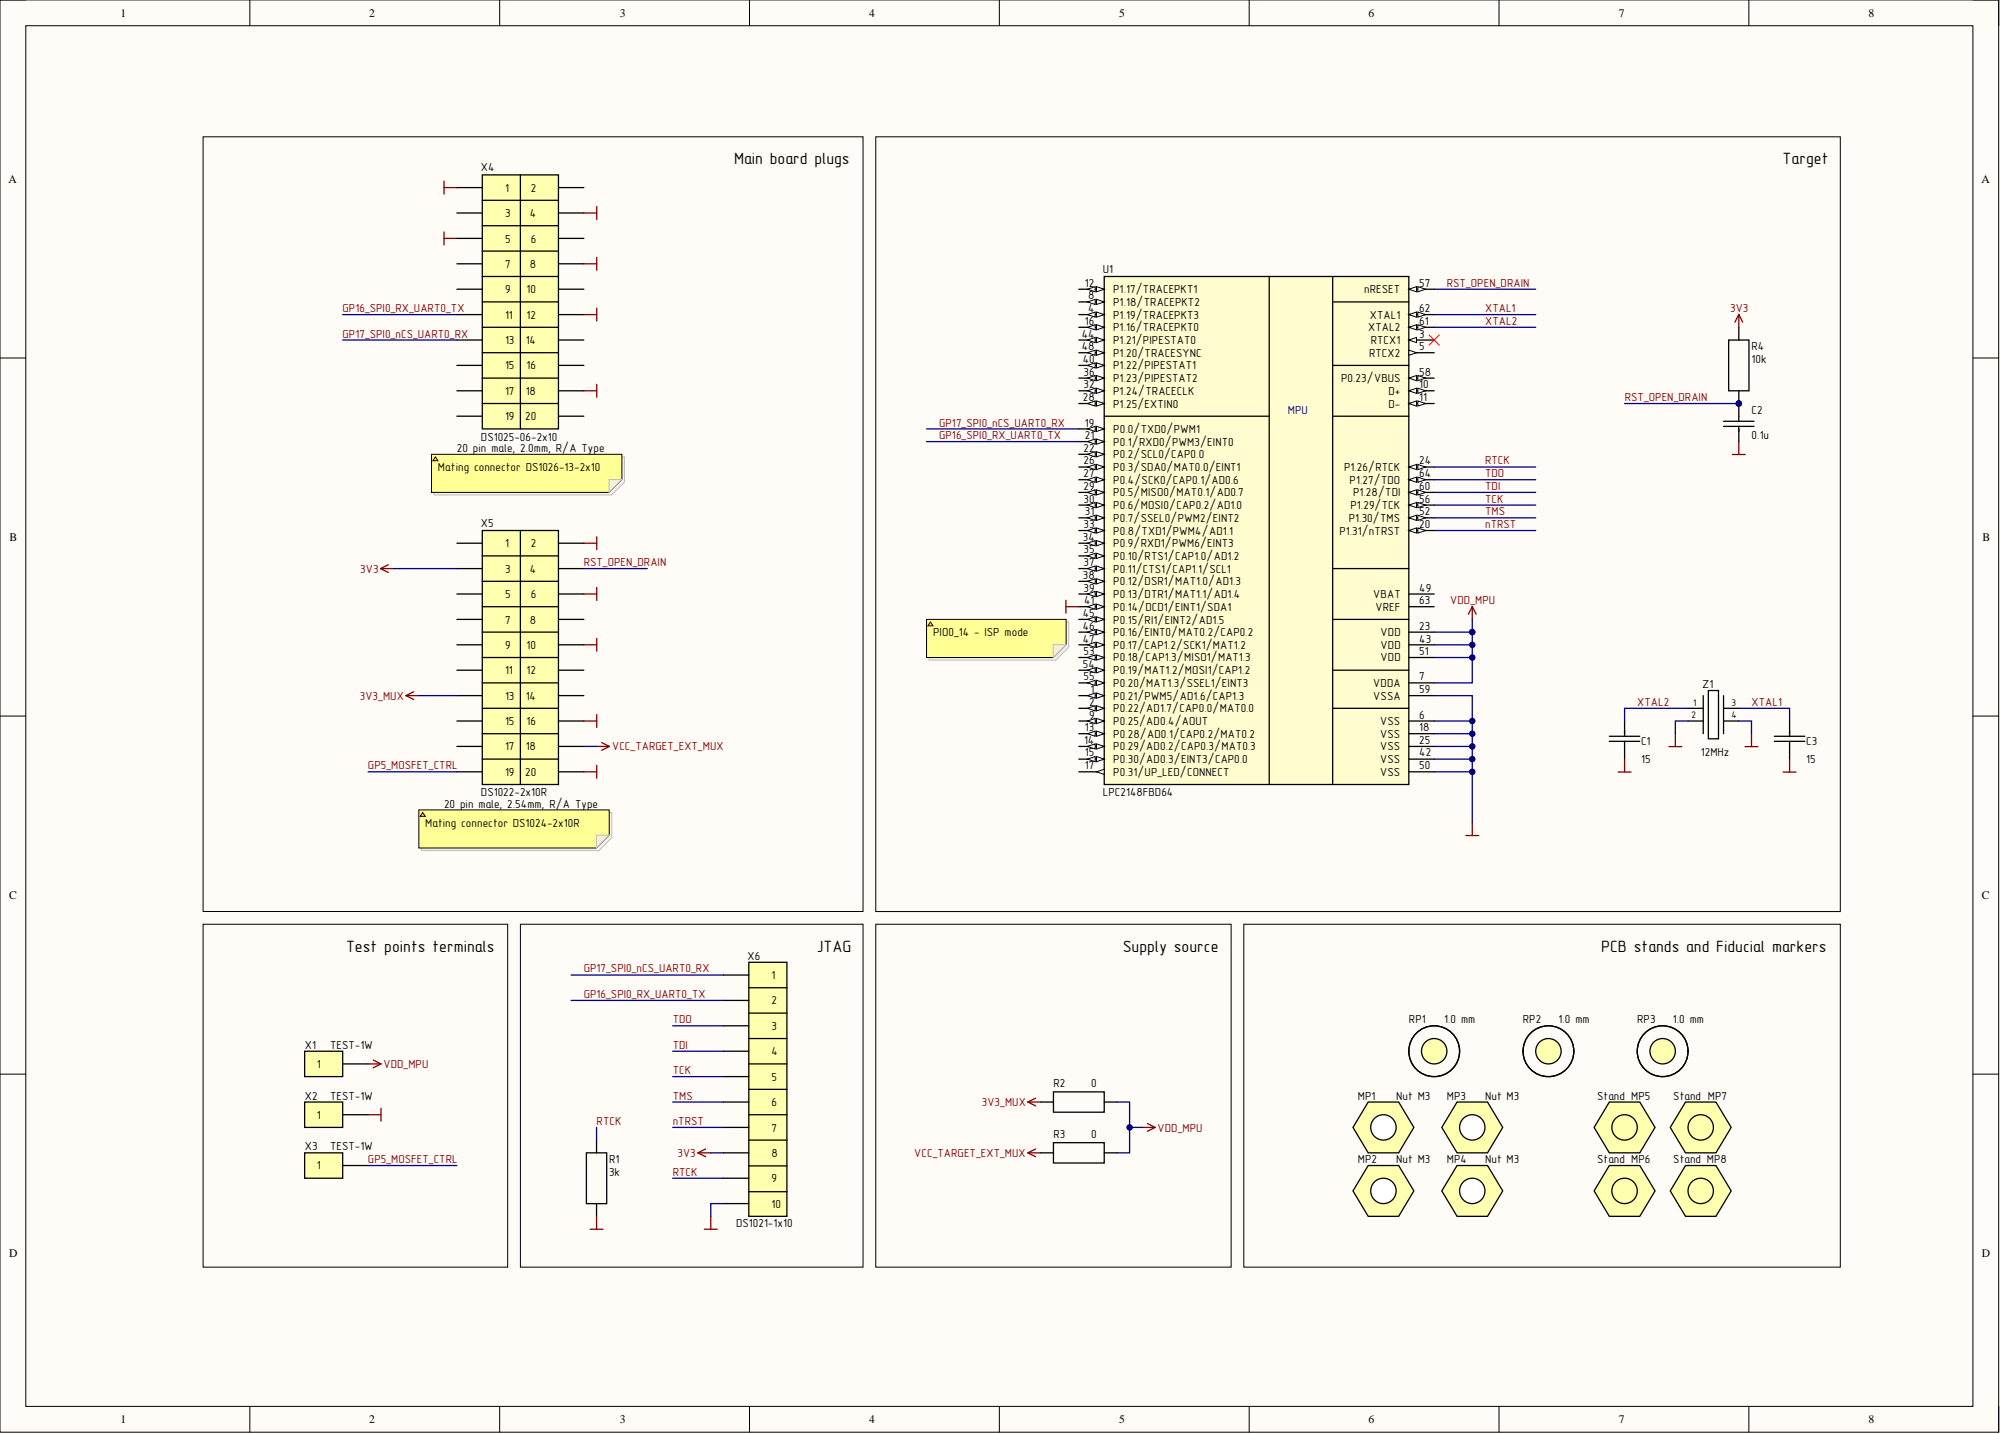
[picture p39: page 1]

PCB stands and Fiducial markers

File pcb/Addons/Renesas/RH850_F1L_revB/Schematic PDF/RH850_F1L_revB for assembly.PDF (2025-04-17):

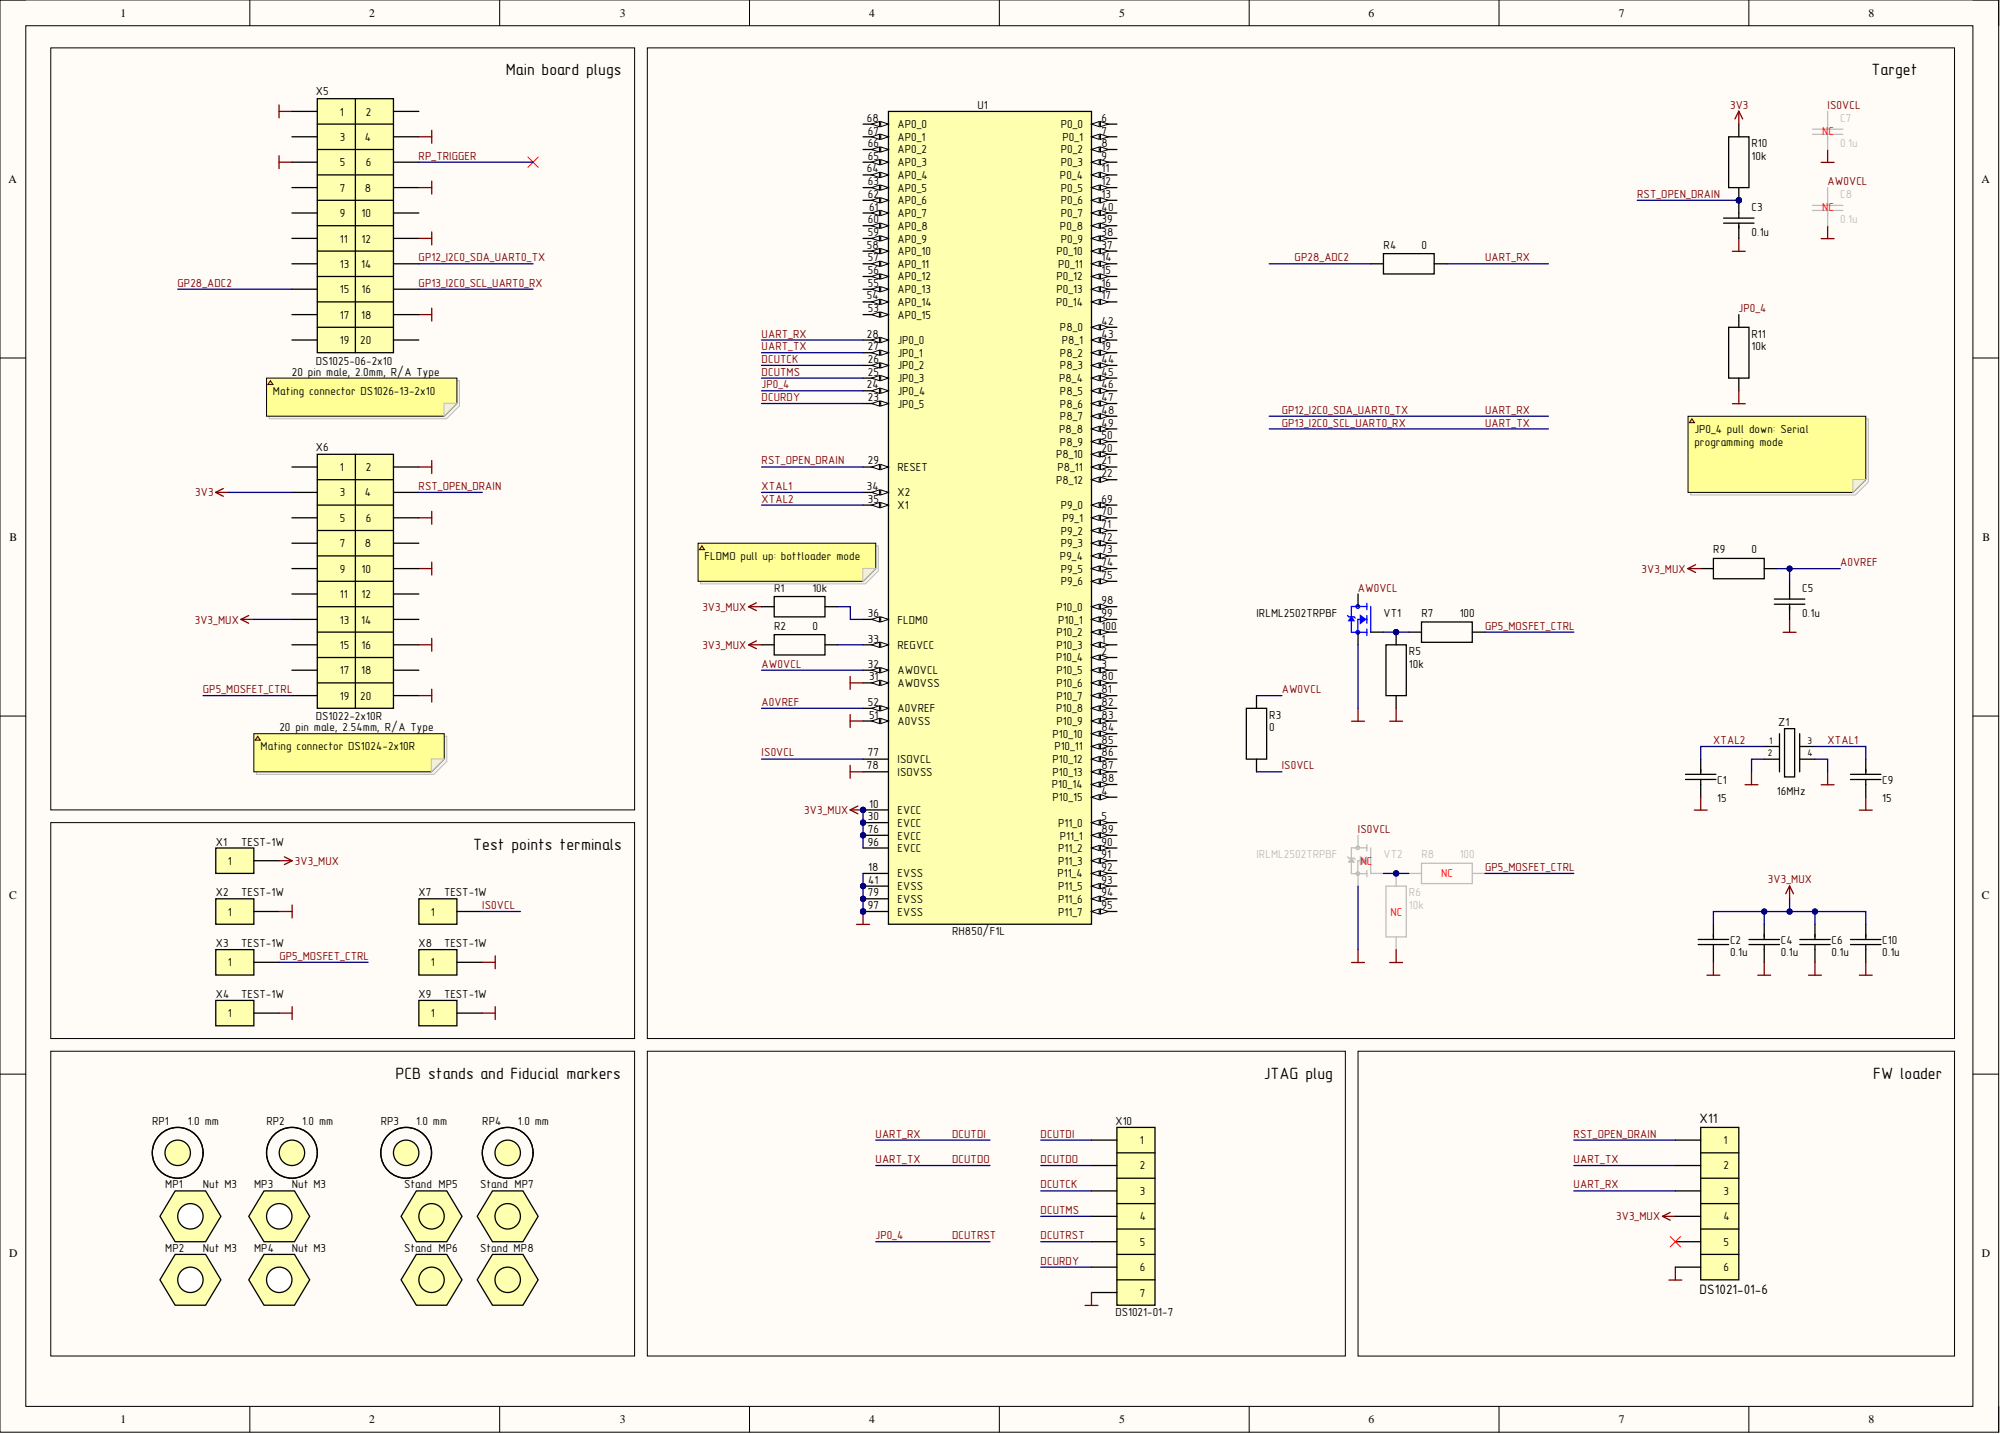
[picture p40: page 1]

Mating connector DS1024-2x10R Mating connector DS1026-13-2x10

PCB stands and Fiducial marker

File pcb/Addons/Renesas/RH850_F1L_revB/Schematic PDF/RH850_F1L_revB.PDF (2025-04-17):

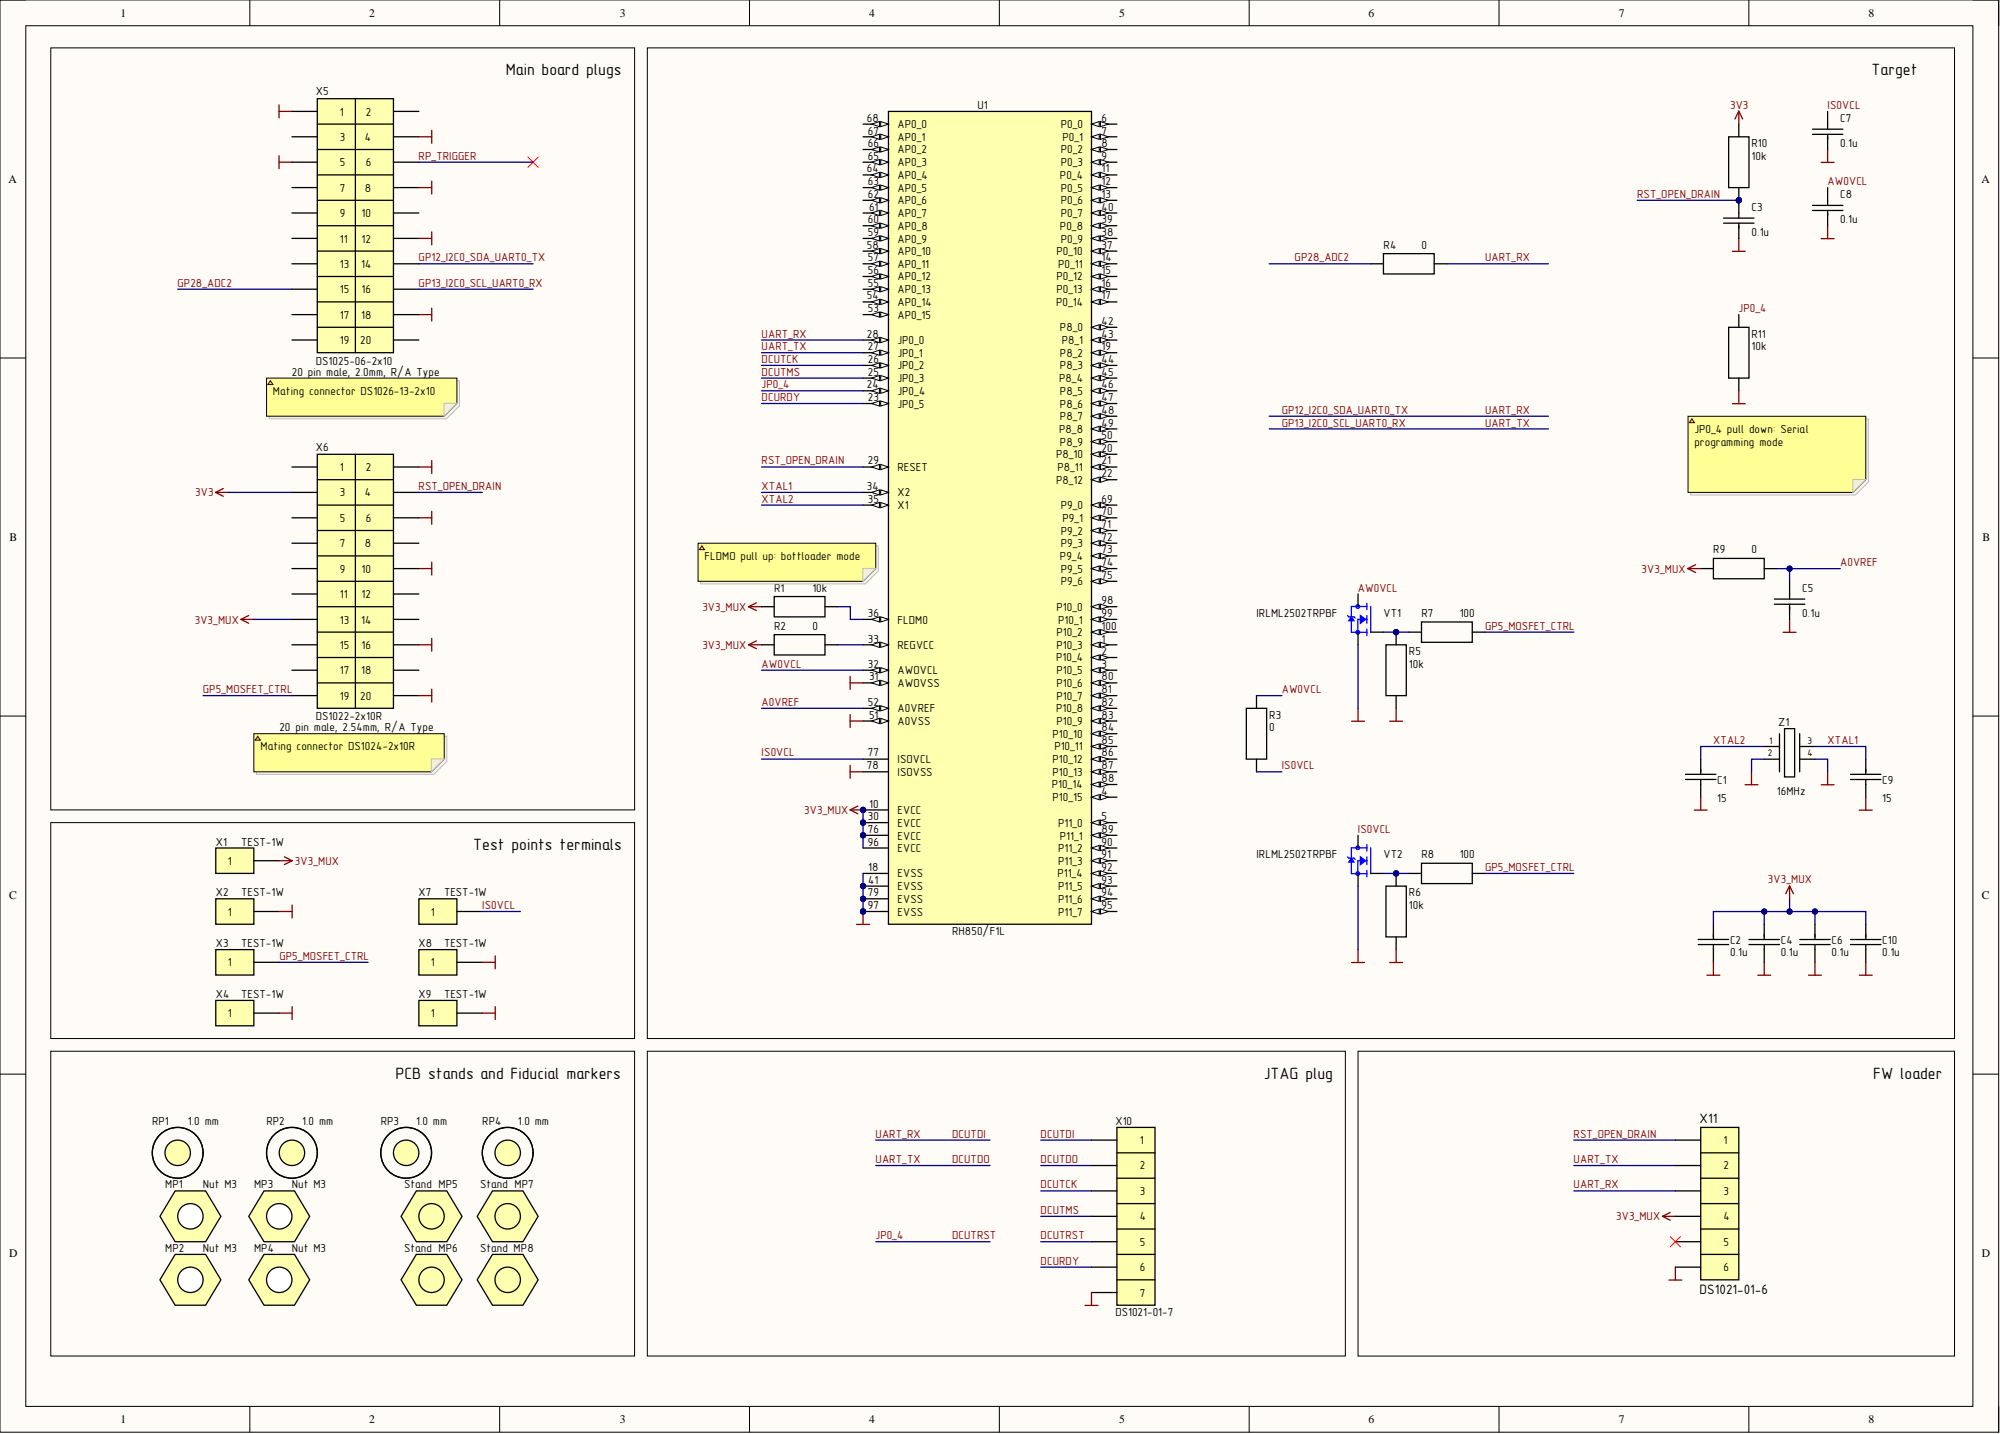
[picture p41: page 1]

GP12_I2C0_SDA_UART0_TX
Mating connector DS1024-2x10R Mating connector DS1026-13-2x10

PCB stands and Fiducial marker

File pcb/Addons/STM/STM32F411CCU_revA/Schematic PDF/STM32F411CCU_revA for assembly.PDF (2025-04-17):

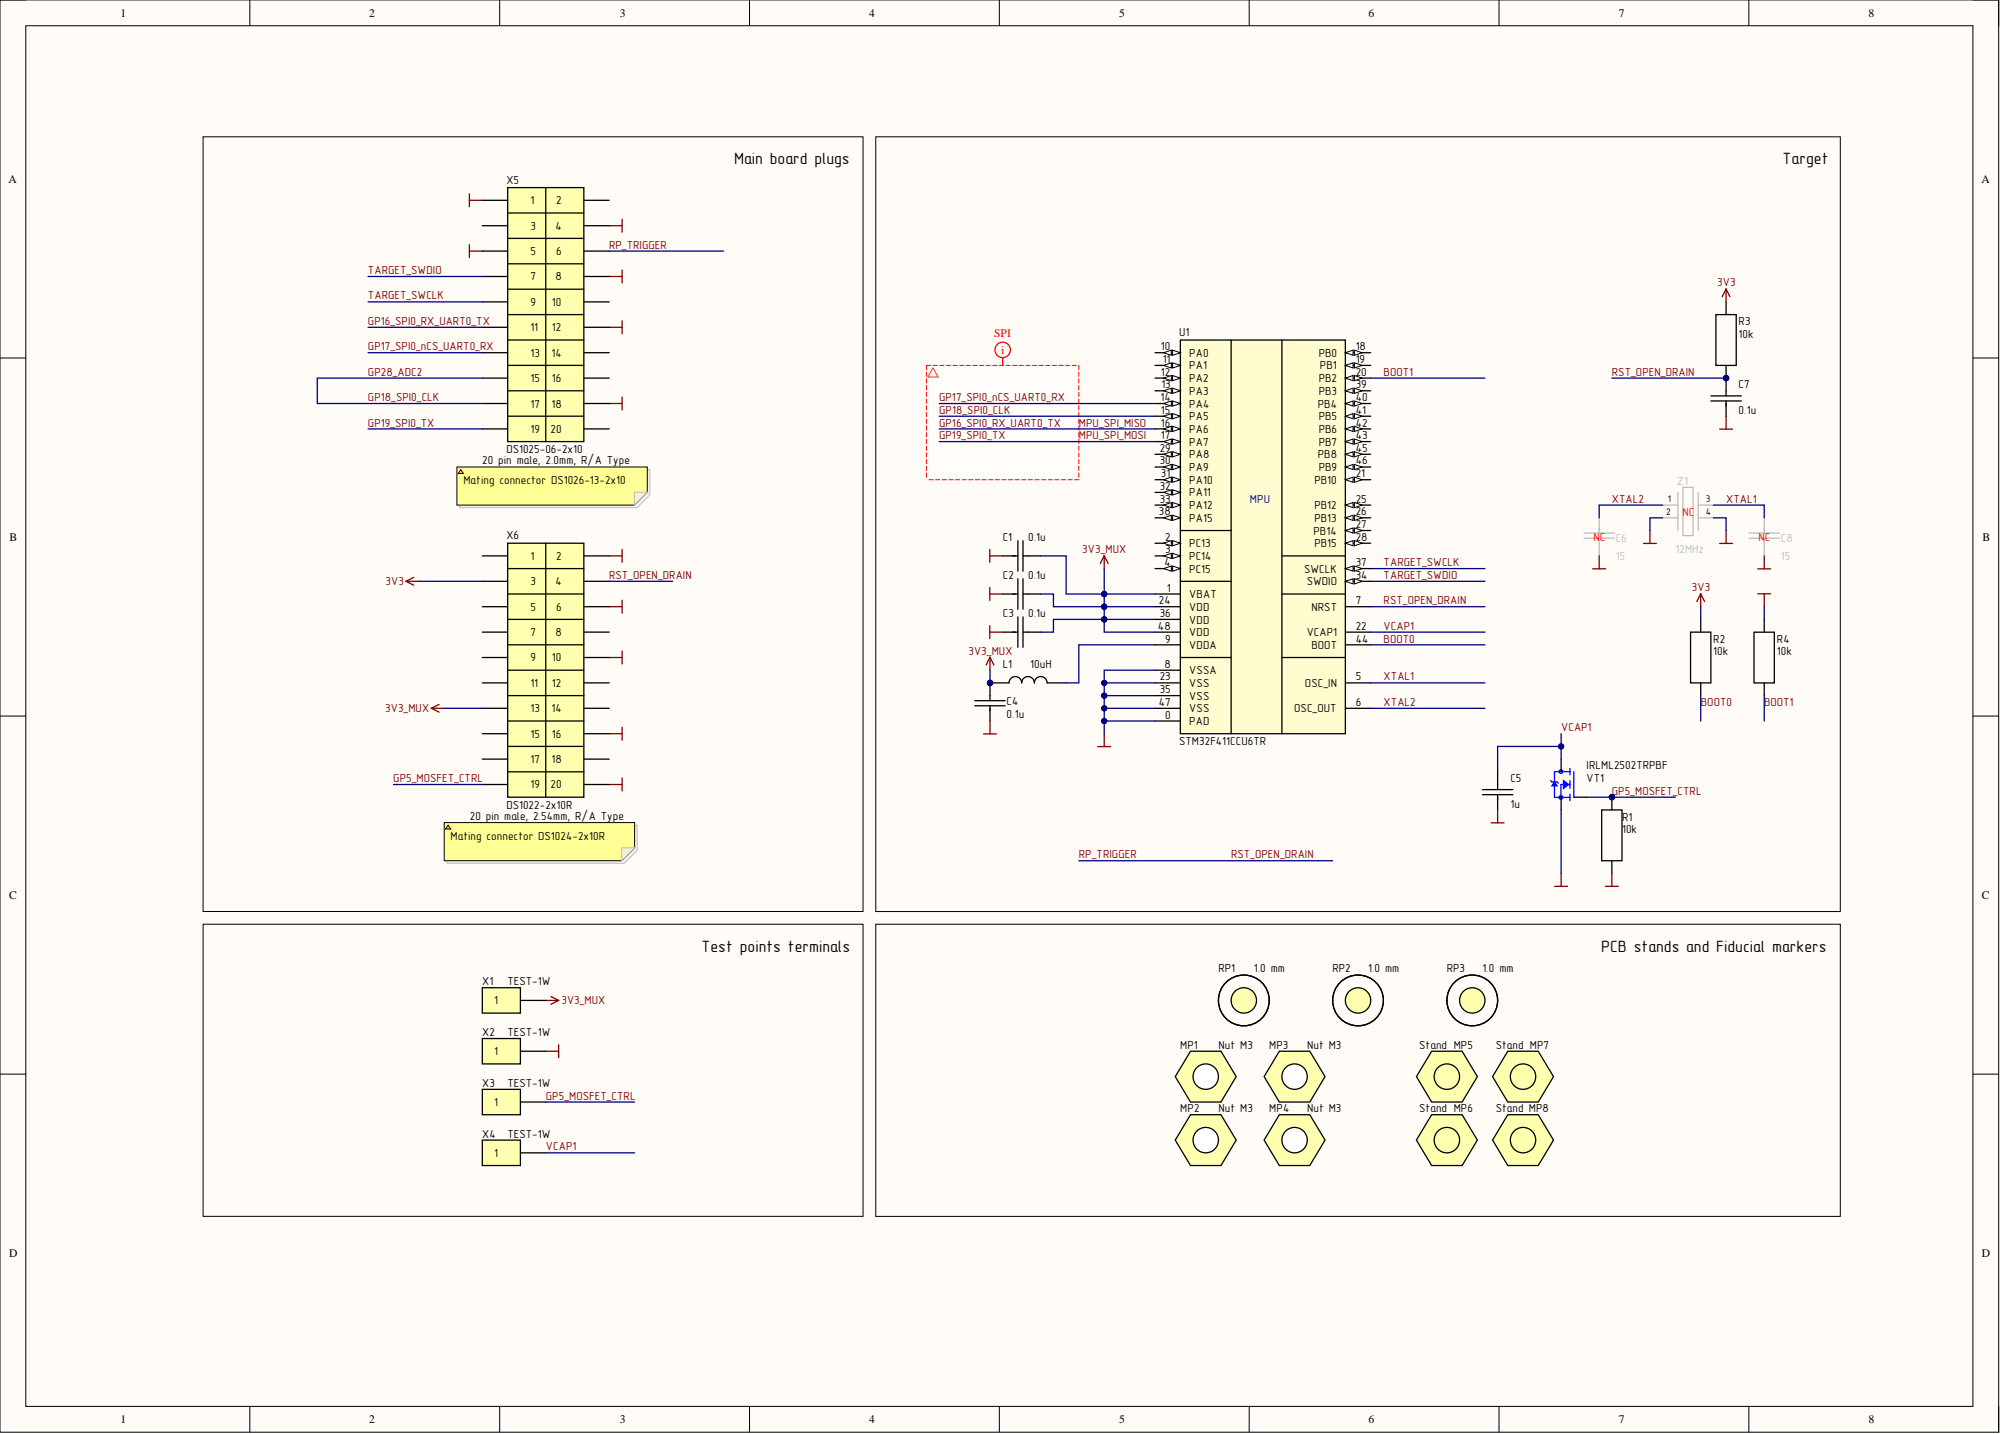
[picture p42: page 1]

VDD 36

PCB stands and Fiducial markers

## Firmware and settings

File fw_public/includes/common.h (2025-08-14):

#ifndef COMMON_H
#define COMMON_H
      
#include <stdio.h>
#include <stdlib.h>
#include <string.h>

#include "pico/stdlib.h"
#include "pico/bootrom.h"
#include "pico/multicore.h"
#include "hardware/clocks.h"
#include "hardware/uart.h"
#include "hardware/pio.h"
#include "hardware/spi.h"

#include "p_3v3_rst.pio.h"
#include "p_gnd_gpio.pio.h"
#include "p_gnd_cnt.pio.h"
#include "p_gnd_cnt_2g.pio.h"
#include "p_gnd_3v3.pio.h"
#include "p_3v3_cnt.pio.h"

#include "pwm.pio.h"
#include "ws2812.h"
#include "target.h"
#include "swd_pico.h"
#include "jtag.h"

#define MCU_UART uart0
#define MCU_SPI spi0

#define MCU_PIN_UART_TX GP12_I2C0_SDA_UART0_TX
#define MCU_PIN_UART_RX GP13_I2C0_SCL_UART0_RX

#define LPC_PIN_UART_TX GP16_SPI0_RX_UART0_TX
#define LPC_PIN_UART_RX GP17_SPI0_nCS_UART0_RX

#define DEFAULT_SWD_PIO pio0
#define DEFAULT_SWD_SM 0

#define DEFAULT_FREE_PIO pio0
#define DEFAULT_FREE_SM 1

#define DEFAULT_GLITCHER_PIO pio1
#define DEFAULT_GLITCHER_SM 0

#define MAX_LEN_SPI_BUF 0x100
#define MAX_LEN_DUMP_MEM 0x1000

#define BIT_CHECK(var,pos) ((var) & (1<<(pos)))
#define BIT_SET(a,b) ((a) |= (1ULL<<(b)))
#define BIT_CLEAR(a,b) ((a) &= ~(1ULL<<(b)))

#define LENGTH(ARRAY) (sizeof(ARRAY) / sizeof(ARRAY[0]))

#define CLK_MAIN_KHZ 250000UL

#define US2TICKS(us) (uint32_t)((us)*CLK_MAIN_KHZ/1000UL)
#define MS2TICKS(ms) (uint32_t)((ms)*CLK_MAIN_KHZ/1000000UL)

#define FLAG_CORE_VALUE 123
#define USB_ARG_MAX_LEN 0x80
#define USB_STR_LEN 0x200
#define UART_BUFF_LEN 0x200

#define STOP_CMD_BIT 0
#define GLITCH_CMD_BIT 1
#define GLITCHING_BIT 2
#define SYNC_BIT 3
#define GLITCH_SUCC_BIT 4
#define GLITCH_FAIL_BIT 5
#define GLITCH_ADDR_CMD 6
#define GLITCH_ADDR_CMD_BIT 7
#define GLITCH_ADDR2_CMD_BIT 8
#define GLITCH_ADDR2_CMD 9

#define GP0_SWCLK_PIO                            0
#define GP1_SWDIO_PIO                            1
#define GP2                                      2
#define GP3_TARGET_RESET                         3
#define GP4_3V3_CTRL                             4
#define GP5_MOSFET_CTRL                          5
#define GP6_VCC_EXT_3V3_LN_CTRL                  6
#define GP7_1V2_CTRL                             7 
#define GP8_1V8_CTRL                             8
#define GP9_5V_CTRL                              9
#define GP10_RP_TRIGGER                         10
#define GP11_SWD_CTRL                           11
#define GP12_I2C0_SDA_UART0_TX                  12
#define GP13_I2C0_SCL_UART0_RX                  13
#define GP14_TRIG_PWR_SEL_0                     14
#define GP15_TRIG_PWR_SEL_1                     15
#define GP16_SPI0_RX_UART0_TX                   16
#define GP17_SPI0_nCS_UART0_RX                  17
#define GP18_SPI0_CLK                           18
#define GP19_SPI0_TX                            19
#define GP20_I2C0_SDA                           20
#define GP21_I2C0_SCL                           21
#define GP22_BTN                                22
#define GP26                                    26
#define GP27_LED_RGD                            27
#define GP28_ADC2                               28

#define EMFI_READY_PIN GP10_RP_TRIGGER

// BRG blue red green
#define GREEN_COLOR  0b000000000000000011111000
#define BLUE_COLOR   0b111110000000000000000000 
#define RED_COLOR    0b000000001111100000000000 
#define WHITE_COLOR  0b111100001111000011110000 
#define PINK_COLOR   0b111100001111100000000000 
#define ORANGE_COLOR 0b000000001111100011100000 
#define OFF_COLOR    0b000000000000000000000000 

#define LOG_INFO_STR 1
#define LOG_INFO_RAW 2
#define LEN_LOG_INFO_MAX 0x10
typedef struct {
    uint8_t sig;
    uint8_t len;
    uint8_t type;
    uint8_t data[LEN_LOG_INFO_MAX];
}log_info_t;

typedef struct {
    uint32_t state;
    uint32_t cmd;
    uint32_t cur_offset;
    uint32_t cur_width;
    uint32_t start_offset;
    uint32_t end_offset;
    uint32_t start_width;
    uint32_t end_width; 
    int32_t step;
    uint32_t attempt;
    uint32_t target_no;
    uint32_t dump_addr1;
    uint32_t dump_addr2;
    uint8_t memory[MAX_LEN_DUMP_MEM];
    log_info_t* log_info;
    target_t* target;
    uint32_t (*on_succ)();
    uint32_t (*on_fail)();
    uint32_t (*on_user_stop)();
}app_t;

extern app_t app;
extern uint8_t mutex_app_log_info;

typedef struct {
    char name[20];
    int arglen;
    void (*func)(void);
} command_t;

typedef enum {
    V_1V2,
    V_1V8,
    V_3V3,
    V_Z
}VOLT_SEL;

void clear_board();
void set_leds_color(uint32_t color1, uint32_t color2);
uint32_t swd_ext_set(bool state);
void trst_pin_set(bool state);
void target_nrst(bool state);
void ctrl_3v3_pin_set(bool state);
void ctrl_ext_vcc_3v3_ln_set(bool state);
void gpio_pin_set(uint32_t gp, bool state);
void gpio_pin_get(uint32_t gp);
uint32_t set_level_shifter(VOLT_SEL volt);
VOLT_SEL get_level_shifter();

uint32_t uart_read_buff(uart_inst_t * uart, uint8_t* buff);
uint32_t uart_send_wait(uart_inst_t * uart, uint8_t* buff_tx, uint8_t* buff_rx, uint32_t time_wait);
uint32_t uart_tx_mem(uart_inst_t * uart, uint8_t* buff_tx, uint32_t size);
uint32_t clr_uart_fifo(uart_inst_t * uart);
uint8_t getc_uart(uart_inst_t * uart, uint32_t time_wait);
uint32_t uart_tx_print(uart_inst_t * uart, uint8_t* buff_tx, uint32_t time_wait);
void log_info_str(uint8_t* str, uint8_t size);
void log_info_raw(uint8_t* data, uint8_t size);
uint32_t get_uart_edges(const uint8_t* data, size_t length);

void pio_pwm_set_period(PIO pio, uint sm, uint32_t period);
void pio_pwm_set_level(PIO pio, uint sm, uint32_t level);
void pwm_init(void);
void emfi_trig_pin_init();
uint8_t is_emfi_ready();

#endif 

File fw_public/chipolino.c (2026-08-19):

#include "includes/common.h"
#include "targets/lpc.h"
#include "targets/nrf52.h"
#include "targets/stm32f4xx.h"
#include "targets/rh850.h"
#include "targets/rk3588.h"
#include "targets/rtl8762c.h"

#include "tusb.h"
#include <ctype.h>

void user_btn_callback();
uint32_t glitch_loop();

uint8_t mutex_app_log_info = 0;

log_info_t log_info = {
    .sig = 0x55,
    .len = 0,
    .type = LOG_INFO_RAW,
};

app_t app = {
    .start_offset = 0,
    .end_offset = 0,
    .start_width = 0,
    .end_width = 0,
    .step = 1,
    .attempt = 1,
    .log_info = &log_info,
};

target_t none_tgt = {
    .name = "none",
    .rst_delay_tick = 0,
    .check_delay_us = 0,
};

target_t *targets_list[] = {
    &none_tgt,
    &stm32f4xx_spi_rdp1_tgt, &stm32f4xx_uart_rdp1_tgt, &stm32f4xx_rdp2_tgt,
    &lpc2148_tgt,
    &lpc1343_tgt,
    &nrf52_tgt,
    &rh850_ser_tgt, &rh850_id_tgt, &rh850_rp_tgt,
    &rk3588_tgt,
    &rtl8762c_tgt,
};

command_t registered_commands[20];
char command_args[6][100];
uint32_t reg_cmd_len;
uint8_t str_arg[USB_STR_LEN];

void err_cmd()
{
    printf("\r\nERROR cmd\r\n");
}

void user_btn_callback() {
    // sleep_ms() kill interrupt work and another same func
    // print PANIC string to UART
    if (gpio_get(GP11_SWD_CTRL))
    {
        swd_ext_set(false);
        set_leds_color(PINK_COLOR, OFF_COLOR);
    }        
    else
    {
        swd_ext_set(true);
        set_leds_color(ORANGE_COLOR, OFF_COLOR);        
    }
}

uint32_t is_target_support(char *tgt)
{
    uint32_t i = 0;
    for (i = 0; i < LENGTH(targets_list); i++)
    {
        if (!strcmp(targets_list[i]->name, tgt))
        {
            return i;
        }
    }
    return 0;
}

void set_target_by_no(app_t *a, uint32_t tgt_no)
{
    a->target_no = tgt_no;
    a->target = targets_list[tgt_no];
}

uint32_t glitch_arg_save(app_t *a, char *arg0, char *arg1, char *arg2, char *arg3)
{
    a->start_offset = atoi(arg0);
    a->end_offset = atoi(arg1);
    a->start_width = atoi(arg2);
    a->end_width = atoi(arg3);
    return 1;
}

void register_command(command_t new_command)
{
    command_t *new_command_ptr = &(registered_commands[reg_cmd_len]);
    memcpy(new_command_ptr, &new_command, sizeof(command_t));
    reg_cmd_len++;
}

bool get_string_timeout_us(char (*buffer)[100], uint32_t timeout)
{
    if (tud_cdc_available())
    {
        for (int i = 0; i < 100; i++)
        {
            int usb_in_value = getchar_timeout_us(timeout);
            if (usb_in_value != PICO_ERROR_TIMEOUT)
            {
                char usb_in_char = usb_in_value & 0xff;
                if (!isspace(usb_in_char))
                {

                    (*buffer)[i] = usb_in_char;
                }
                else
                {
                    return true;
                }
            }
            else
            {
                return false;
            }
        }
    }
    else
    {
        return false;
    }
}

void parse_cmd_from_usb()
{
    BIT_CLEAR(app.state, GLITCH_ADDR_CMD_BIT);
    BIT_CLEAR(app.state, GLITCH_ADDR2_CMD_BIT);

    char cur_cmdname[100] = "";
    bool cmd_has_all_args = true;
    uint32_t counter = 0;
    command_t *cur_potential_cmd = &(registered_commands[0]);
    while (!get_string_timeout_us(&cur_cmdname, 100))
    {
        sleep_ms(100);
    }
    printf("%s ", cur_cmdname);
    for (int i = 0; i < reg_cmd_len; i++)
    {
        cur_potential_cmd = &(registered_commands[i]);
        if (strncmp(cur_potential_cmd->name, cur_cmdname, sizeof(cur_potential_cmd->name)) == 0)
        {
            break;
        }
    }
    for (uint8_t cmd_no = 0; cmd_no < cur_potential_cmd->arglen; cmd_no++)
    {
        memset(&command_args[cmd_no][0], 0, sizeof(command_args[cmd_no]));
        if (!get_string_timeout_us(&command_args[cmd_no], 100))
        {
            cmd_has_all_args = false;
            printf("\r\nNeed %d more arguments", cur_potential_cmd->arglen - cmd_no);
            break;
        }
        else
        {
            printf("%s ", command_args[cmd_no]);
        }
    }
    printf("\r\n");
    if (cmd_has_all_args)
    {
        gpio_put(PICO_DEFAULT_LED_PIN, false);        
        cur_potential_cmd->func();
    }
}

void handle_stop()
{
    BIT_SET(app.state, STOP_CMD_BIT);
}

void handle_bootrom()
{
    reset_usb_boot(0, 0);
}

void handle_state()
{
    log_info_t log_info_tmp;
    mutex_app_log_info = 1;
    memcpy((uint8_t *)&log_info_tmp, (uint8_t *)app.log_info, sizeof(log_info_t));
    mutex_app_log_info = 0;
    printf("--- state start ---\r\n");
    printf("state: 0x%x\r\n", app.state);
    printf("cur_offset: %d\r\n", app.cur_offset);
    printf("cur_width: %d\r\n", app.cur_width);
    printf("log_info: ");
    printf("%02x", app.log_info->sig);
    printf("%02x", app.log_info->len);
    printf("%02x", app.log_info->type);
    for (uint8_t i = 0; i < app.log_info->len; i++)
        printf("%02x", app.log_info->data[i]);
    printf("\r\n");
    printf("--- state end ---\r\n");
}

void handle_swd()
{
    if (atoi(command_args[0]) == 1)
        swd_ext_set(true);
    if (atoi(command_args[0]) == 0)
        swd_ext_set(false);
}

void handle_gpio()
{
    if (atoi(command_args[1]) == 1)
        gpio_pin_set(atoi(command_args[0]), true);
    if (atoi(command_args[1]) == 0)
        gpio_pin_set(atoi(command_args[0]), false);
}

void handle_trigger()
{
    if (!strcmp(command_args[0], "1v2"))
        set_level_shifter(V_1V2);
    else if (!strcmp(command_args[0], "1v8"))
        set_level_shifter(V_1V8);
    else if (!strcmp(command_args[0], "3v3"))
        set_level_shifter(V_3V3);
    else
        set_level_shifter(V_Z);
}

void handle_status()
{
    printf("--- status start ---\r\n");
    printf("Target: %s\r\n", app.target->name);
    printf("app.target_no: %d\r\n", app.target_no);
    printf("app.state: 0x%x\r\n", app.state);
    printf("reset delay: %d\r\n", app.target->rst_delay_tick);
    printf("check delay: %d\r\n", app.target->check_delay_us);
    printf("start_offset: %d\r\n", app.start_offset);
    printf("end_offset: %d\r\n", app.end_offset);
    printf("start_width: %d\r\n", app.start_width);
    printf("end_width: %d\r\n", app.end_width);

    printf("step: %d\r\n", app.step);
    printf("attempt: %d\r\n", app.attempt);
    printf("cur_offset: %d\r\n", app.cur_offset);
    printf("cur_width: %d\r\n", app.cur_width);

    if (gpio_get(GP11_SWD_CTRL))
        printf("swd_external: true\r\n");
    else
        printf("swd_external: false\r\n");

    VOLT_SEL v = get_level_shifter();
    if (v == V_1V2)
        printf("level shifter: 1.2v\r\n");
    else if (v == V_1V8)
        printf("level shifter: 1.8v\r\n");
    else if (v == V_3V3)
        printf("level shifter: 3.3v\r\n");
    else if (v == V_Z)
        printf("level shifter: Z\r\n");
    else
        printf("level shifter: unknown\r\n");

    printf("--- status end ---\r\n");
}

void handle_glitch()
{
    BIT_CLEAR(app.state, SYNC_BIT);
    BIT_CLEAR(app.state, GLITCH_SUCC_BIT);
    BIT_CLEAR(app.state, GLITCH_ADDR_CMD);
    if (is_target_support(command_args[0]))
    {
        set_target_by_no(&app, is_target_support(command_args[0]));
        if (glitch_arg_save(&app, command_args[1], command_args[2], command_args[3], command_args[4]))
        {
            if (BIT_CHECK(app.state, GLITCH_ADDR_CMD_BIT)) // GLITCH_ADDR
            {
                BIT_SET(app.state, GLITCH_ADDR_CMD);
                app.dump_addr1 = strtoul(command_args[5], NULL, 16);
            }
            if (BIT_CHECK(app.state, GLITCH_ADDR2_CMD_BIT)) // GLITCH_ADDR2
            {
                BIT_SET(app.state, GLITCH_ADDR2_CMD);
                app.dump_addr1 = strtoul(command_args[5], NULL, 16);
                app.dump_addr2 = strtoul(command_args[6], NULL, 16);
            }
            clear_board();
            app.target->board_init();
            app.target->rst_state();
            if (app.target->sync_checker())
            {
                app.target->load_pio_prog();
                BIT_SET(app.state, SYNC_BIT);
                BIT_SET(app.state, GLITCH_CMD_BIT);                
                multicore_fifo_push_blocking('G');
            }
            else
            {
                printf("Target no sync\r\n");
            }
        }
        else
        {
            err_cmd();
        }
    }
    else
    {
        err_cmd();
    }
}

void handle_glitch_addr()
{
    BIT_SET(app.state, GLITCH_ADDR_CMD_BIT);
    handle_glitch();
}

void handle_glitch_addr2()
{
    BIT_SET(app.state, GLITCH_ADDR2_CMD_BIT);
    handle_glitch();
}

void handle_get_memory()
{
    printf("--- get memory start ---\r\n");
    printf("addr 0x%x\r\n", app.dump_addr1);
    printf("mem ");
    for (int i = 0; i < 0x200; i++)
    {
        printf("%02x", app.memory[i]);
    }
    printf("\r\n");
    printf("--- get memory end ---\r\n");
}

void handle_set_rdp()
{
    printf("\r\n%s\r\n", command_args[0]);
    if (atoi(command_args[0]) == 0)
    {
        stm_set_rdp(0xAA);
    }
    else if (atoi(command_args[0]) == 1)
    {
        stm_set_rdp(0xBB);
    }
    else if (atoi(command_args[0]) == 2)
    {
        stm_set_rdp(0xCC);
    }
}

void handle_set_step()
{
    app.step = atoi(command_args[0]);
}

void handle_set_attempt()
{
    app.attempt = atoi(command_args[0]);
}

void handle_self_test()
{
    set_leds_color(OFF_COLOR, OFF_COLOR);
    set_leds_color(OFF_COLOR, OFF_COLOR);
    for(uint8_t i = 0; i < 3; i++)
    {
        gpio_pin_set(GP4_3V3_CTRL, true);
        gpio_pin_set(GP6_VCC_EXT_3V3_LN_CTRL, true);
        gpio_pin_set(GP7_1V2_CTRL, true);
        gpio_pin_set(GP8_1V8_CTRL, true);
        gpio_pin_set(GP9_5V_CTRL, true);
        set_leds_color(PINK_COLOR, PINK_COLOR);
        swd_ext_set(true);
        set_level_shifter(V_1V2);
        sleep_ms(1000);

        set_leds_color(WHITE_COLOR, WHITE_COLOR);
        set_level_shifter(V_1V8);
        sleep_ms(1000);

        set_leds_color(GREEN_COLOR, GREEN_COLOR);
        set_level_shifter(V_3V3);
        sleep_ms(1000);

        gpio_pin_set(GP4_3V3_CTRL, false);
        gpio_pin_set(GP6_VCC_EXT_3V3_LN_CTRL, false);
        gpio_pin_set(GP7_1V2_CTRL, false);
        gpio_pin_set(GP8_1V8_CTRL, false);
        gpio_pin_set(GP9_5V_CTRL, false);
        set_leds_color(OFF_COLOR, OFF_COLOR);
        swd_ext_set(false);
        set_level_shifter(V_Z);
        sleep_ms(1000);
    }    
}

void handle_unknown_cmd()
{
    printf("Unknown command\n");
}

void register_commands()
{
    register_command((command_t){"STOP", 0, &handle_stop});
    register_command((command_t){"GLITCH", 5, &handle_glitch});
    register_command((command_t){"GLITCH_ADDR", 6, &handle_glitch_addr});
    register_command((command_t){"GLITCH_ADDR2", 7, &handle_glitch_addr2});
    register_command((command_t){"BOOTROM", 0, &handle_bootrom});
    register_command((command_t){"STATE", 0, &handle_state});
    register_command((command_t){"SWD", 1, &handle_swd});
    register_command((command_t){"STEP", 1, &handle_set_step});
    register_command((command_t){"ATTEMPT", 1, &handle_set_attempt});
    register_command((command_t){"GPIO", 2, &handle_gpio});
    register_command((command_t){"TRIG", 1, &handle_trigger});
    register_command((command_t){"STATUS", 0, &handle_status});
    register_command((command_t){"GET_MEMORY", 0, &handle_get_memory});
    register_command((command_t){"GET_RDP", 0, &stm_get_rdp});
    register_command((command_t){"SET_RDP", 1, &handle_set_rdp});
    register_command((command_t){"SELF_TEST", 0, &handle_self_test});
    register_command((command_t){"", 0, &handle_unknown_cmd});
}

uint32_t glitch_loop()
{
    if (app.step < 0)
    {
        for (app.cur_offset = app.end_offset; (app.cur_offset > app.start_offset) && (!BIT_CHECK(app.state, STOP_CMD_BIT)); app.cur_offset+=app.step)
        {
            for (app.cur_width = app.start_width; (app.cur_width < app.end_width) && (!BIT_CHECK(app.state, STOP_CMD_BIT)); app.cur_width++)
            {
                for (uint8_t try = 0; (try < 1) && (!BIT_CHECK(app.state, STOP_CMD_BIT)); try+=app.attempt)
                {
                    printf("%d, %d\r\n", app.cur_offset, app.cur_width);
                    app.target->glitch(app.cur_offset, app.cur_width);                
                    if (app.target->unlock_checker())
                    {
                        return 1;
                    }
                }
            }
        }
        return 0;
    }


    for (app.cur_offset = app.start_offset; (app.cur_offset < app.end_offset) && (!BIT_CHECK(app.state, STOP_CMD_BIT)); app.cur_offset+=app.step)
    {
        for (app.cur_width = app.start_width; (app.cur_width < app.end_width) && (!BIT_CHECK(app.state, STOP_CMD_BIT)); app.cur_width++)
        {
            for (uint8_t try = 0; (try < 1) && (!BIT_CHECK(app.state, STOP_CMD_BIT)); try+=app.attempt)
            {
                printf("%d, %d\r\n", app.cur_offset, app.cur_width);
                app.target->glitch(app.cur_offset, app.cur_width);                
                if (app.target->unlock_checker())
                {
                    return 1;
                }
            }
        }
    }
    return 0;
}

void worker_core1()
{
    uint work_cmd;
    uint32_t fifo_val;
    uint32_t g = multicore_fifo_pop_blocking();
    if (g == FLAG_CORE_VALUE)
    {
        multicore_fifo_push_blocking(FLAG_CORE_VALUE);
    }

    while (1)
    {
        BIT_CLEAR(app.state, STOP_CMD_BIT);
        fifo_val = multicore_fifo_pop_blocking();
        if (fifo_val == 'G')
        {
            printf("Core1: rx cmd G\r\n");
            if (BIT_CHECK(app.state, GLITCH_CMD_BIT))
            {
                printf("Core1: Glitch start\r\n");
                BIT_CLEAR(app.state, GLITCH_CMD_BIT);
                BIT_SET(app.state, GLITCHING_BIT);
                set_leds_color(WHITE_COLOR, OFF_COLOR);
                if (glitch_loop())
                {
                    BIT_SET(app.state, GLITCH_SUCC_BIT);
                    printf("------------------------\r\n");
                    printf("Glitch OK done\r\n");
                    printf("Offset %d, Width %d\r\n", app.cur_offset, app.cur_width);
                    printf("------------------------\r\n");
                    set_leds_color(GREEN_COLOR, OFF_COLOR);
                }
                else
                {
                    printf("------------------------\r\n");
                    printf("Glitch BAD done\r\n");
                    printf("------------------------\r\n");
                    set_leds_color(RED_COLOR, OFF_COLOR);
                }
                BIT_CLEAR(app.state, GLITCHING_BIT);
            }
        }
    }
}

void board_init()
{
    ws2812_init(&ws2812_config);
    swd_ext_set(false);
    set_level_shifter(V_1V8);    
    ctrl_ext_vcc_3v3_ln_set(false);
    target_nrst(false);
    ctrl_3v3_pin_set(false);

    gpio_init(GP28_ADC2);
    gpio_set_dir(GP28_ADC2, GPIO_IN);

    gpio_init(GP22_BTN);
    gpio_set_dir(GP22_BTN, GPIO_IN);
    gpio_set_irq_enabled_with_callback(GP22_BTN, GPIO_IRQ_EDGE_RISE, true, &user_btn_callback);

    register_commands();
    sleep_ms(10);
    set_leds_color(OFF_COLOR, OFF_COLOR);
    set_leds_color(OFF_COLOR, OFF_COLOR);

    gpio_init(GP16_SPI0_RX_UART0_TX);
    gpio_set_dir(GP16_SPI0_RX_UART0_TX, GPIO_IN);
    gpio_init(GP17_SPI0_nCS_UART0_RX);
    gpio_set_dir(GP17_SPI0_nCS_UART0_RX, GPIO_IN); 

    gpio_init(GP12_I2C0_SDA_UART0_TX);
    gpio_set_dir(GP12_I2C0_SDA_UART0_TX, GPIO_IN);
    gpio_init(GP13_I2C0_SCL_UART0_RX);
    gpio_set_dir(GP13_I2C0_SCL_UART0_RX, GPIO_IN); 
}

int main()
{
    set_sys_clock_khz(CLK_MAIN_KHZ, true);

    stdio_usb_init();
    stdio_set_translate_crlf(&stdio_usb, false);
    multicore_launch_core1(worker_core1);

    multicore_fifo_push_blocking(FLAG_CORE_VALUE);
    uint32_t g = multicore_fifo_pop_blocking();
    board_init();
    while (!stdio_usb_connected())
    {
        sleep_ms(100);
    }
    if (g != FLAG_CORE_VALUE)
    {
        printf("Core1: not start\n");
    }

    while (true)
    {
        parse_cmd_from_usb();
    }
}

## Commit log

2025-04-17 end upd repo last
    [Bill of Materials-ChipOlino_revA.xlsx, Bill of Materials-LPC2148FBD64_revA(Normal).xlsx, Bill of Materials-RH850_F1L_revB(Normal).xlsx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]
2025-08-09 Update: add targets, scripts, upd Playbook
    [Bill of Materials-LPC1343FBD48_revA(Normal).xlsx, Bill of Materials-LPC2148FBD64_revA(Normal).xlsx, Bill of Materials-RH850_F1L_revB(Normal).xlsx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]
2025-08-14 fix build for new GCC
    [chipolino.c, common.h]
2026-08-19 add pcb files for RTL8762
    [Bill of Materials-RTL8762CKF_revA(Default).xlsx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]
